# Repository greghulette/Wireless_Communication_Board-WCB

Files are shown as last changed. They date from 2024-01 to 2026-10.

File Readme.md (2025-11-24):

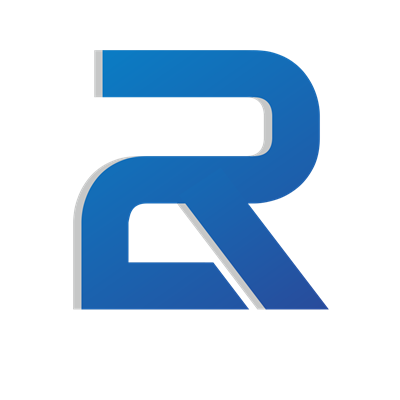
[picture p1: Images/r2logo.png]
<h1 style="display:inline; height: 75px; font-size:51px;">Wireless Communication Board (WCB)</h1>

<br>



# Software 3.0 and newer release changes the command structure.  Please read below to ensure proper operations.  

**NEW WIKI created to help better orgainize the documenation.  It can be found at the top the page or by clicking this link: [WCB Wiki](https://github.com/greghulette/Wireless_Communication_Board-WCB/wiki/)**

<br>
<br>
<br>
<br>
<br>

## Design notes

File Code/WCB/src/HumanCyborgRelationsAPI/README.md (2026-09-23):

> ## ⚠️ WCB vendored + patched copy — do not replace with stock upstream
>
> This is the [HumanCyborgRelationsAPI](https://github.com/roy86/HumanCyborgRelationsAPI)
> by roy86, **vendored directly into the WCB sketch** and patched for the
> Wireless Communication Board. It lives at `Code/WCB/src/HumanCyborgRelationsAPI/`
> and is pulled in with a relative `#include "src/HumanCyborgRelationsAPI/hcr.h"`,
> so **building the WCB firmware needs no library install** — and any HCR library
> already installed in your IDE is ignored (the bundled copy always wins).
>
> **WCB patches vs. upstream:**
> - **I2C/TwoWire removed** — the WCB drives the HCR over a serial UART only.
>   `hcr.h` `#define`s `TwoWire_h` before `#include <Wire.h>` (neutering it) and
>   every I2C constructor / transfer in `hcr.cpp` is commented out.
> - **`<String.h>` → `<string.h>`** (lowercase) so the build works on
>   case-sensitive filesystems (Linux CI), not just Windows/macOS.
> - **`PlayWAV()` debounce** is per channel and 150 ms (upstream: one global 5 s).
> - **`GetVolume(ch)`** added — the cached volume, no transmit. `getVolume()`
>   still sends `<QVx>` and returns the value cached before the reply.
> - **Dataframe key `QD`** accepted (the documented reply to `<QD>`); upstream
>   matched only `DF`, so the dataframe never parsed. Needs exactly 11 values.
> - **Receive framing:** `HCR_BUFFER_SIZE` 32 → 64, `<` resets the frame, only `>`
>   commits one (a CR/LF/NUL before it discards the partial frame), and an
>   over-long frame is dropped instead of parsed truncated.
> - **Reply validation:** every value field must be numeric, the field count must
>   match the key (2; `QE` 5; `QD`/`DF` 12), and `QVx` must be 0-100; anything else
>   is rejected (`onFrame(..., false)`) without touching the cache.
> - **`receive()` drains** up to `HCR_BUFFER_SIZE` waiting bytes per `update()`
>   (upstream: one byte), so a full reply set can't overflow the soft-serial buffer.
> - **`onFrame(frame, parsed)`** — protected virtual hook called after every
>   received frame. The library's own `Serial` prints never reach USB on the WCB.
> - **Virtual destructor** — the class now has a virtual hook, so it gets one.
> - **`StopEmoteGraceful()` / `StopGraceful()`** added — emit `<PSG>`, the
>   vocalizer's graceful stop. Upstream emits `PSV` from every stop path, so a
>   port owned by the library could only ever stop abruptly (issue #15).
> - **`<SoftwareSerial.h>` → `"../EspSoftwareSerial/SoftwareSerial.h"`** (`hcr.h`, and the
>   AVR/PIC32-only branches in `hcr.cpp`): the WCB's vendored, patched EspSoftwareSerial
>   (tracker #78, CLAUDE.md rule 7). Never use the angle-bracket include. CI installs no
>   stock copy, so the build would fail there; locally it would pull in the stock copy, and
>   the vendored header's `#error` or a class redefinition would stop the build.
> - **`SetEmotion(e, v)` accepts 0-100** (upstream accepted 0-99), to match `SetVolume`
>   and the range `;H,SETEMOTION` accepts. Upstream silently dropped v = 100.
>
> Upstream license is preserved in `LICENSE`. To pull a newer upstream, re-apply
> the patches above rather than dropping a stock copy in place.

---

Banner Employee Data title

# Human Cyborg Relations C++ API
C++ based API for interfacing with Michael Perl's [Human Cyborg Relations](https://humancyborgrelations.com/r2d2/) Teensy Based Vocalizers

## Overview

[Human Cyborg Relations](https://humancyborgrelations.com/r2d2/), created by Michael Perl, has set a new standard for Droid Vocalization through a fully functional AI, powered by advanced research into the speech patterns and emotional logic of R2-D2.

Each vocalization is unique. A sophisticated algorithm assembles R2’s speech "phoneme" by "phoneme." Billions upon billions of rules dictate how each sound should be selected, processed, timed, and sequenced to achieve emotional and canonical accuracy.

The [Human Cyborg Relations R2 Vocalizer](https://humancyborgrelations.com/r2d2/) has been ported to the Teensy 4.1 Hardware for stand-alone integration into custom droids build for the Astromech community usage. The WIKI and CODE here relates to the C++ Library created for Arduino/Teensy/ESP projects to allow people to interface their boards with the HCR R2 Vocalizer programmed Teensy 4.1 + Audio Shield.

Please when using this library, we encourage everyone to make a small donation directly to and support [Force for Change](https://www.starwars.com/force-for-change) and [FIRST®](https://www.firstinspires.org/)

## Documentation
### [API WIKI](https://github.com/roy86/HumanCyborgRelationsAPI/wiki)

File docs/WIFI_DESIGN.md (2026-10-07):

# WCB WiFi — hosting an access point, or joining one

Status: **in development on branch `WIFI`.** Not in a release.

A WCB can optionally bring up an IP interface — hosting its own access point, or
joining an existing one — so the mesh can be managed from a phone with no USB cable
and no extra hardware. It is **off by default**, and with it off the firmware behaves
exactly as it did before.

---

## 1. Why this lives on the boards

A phone cannot open a serial port. The Web Serial API is desktop-only — not Android
Chrome, never iOS — so a mobile client has no way to reach the mesh except over a
network. That single platform limit is what forces this design.

The alternatives were both rejected:

| Option | Why not |
|---|---|
| A dedicated relay board (`MgmtRelay` in `WCBClient`) | An extra ESP32, an extra power tap and an extra thing to fail, in every droid, whose only job is management. Fine as a bench tool; not something to ask every builder to install. |
| Require a NaviCore | Only a small subset of WCB users have one. Its AP cannot be assumed to exist. |

So the boards have to be able to carry it themselves. The relay and NaviCore paths
still work and are still useful — they are simply not the answer for most builders.

---

## 2. The one rule: the radio has one channel

The ESP32 has a **single radio**. An access point we host, or one we associate with,
shares its channel with ESP-NOW. Therefore:

> **The WiFi channel is always `meshChannel` (`?WCBCH`) and is deliberately not
> separately configurable.**

This is not a simplification for convenience. A WiFi channel that disagrees with the
mesh is a *silent, total* blackout: every ESP-NOW packet dropped, nothing logged on
the other boards, no fault indication anywhere. Offering the choice would mean
offering a way to brick the mesh with no symptom. Every entry point passes
`meshChannel` explicitly:

- `WiFi.softAP(ssid, pass, meshChannel, …)` — the channel argument **defaults to 1**.
  Once an AP owns the radio nothing later moves it, so a defaulted channel against a
  mesh on any other channel is exactly the blackout above.
- JOIN scans `meshChannel` alone for its SSID first (`WiFi.scanNetworks`, asynchronous, 120 ms) and calls
  `WiFi.begin(ssid, pass, meshChannel, bssid)` only for an AP heard there. `WiFi.begin`'s channel does not pin
  anything: it is where the driver's own connect scan *starts* (`wifi_sta_config_t.channel`, a "channel hint"),
  and with the AP absent that scan swept every channel on each attempt, taking the board off the mesh.
- JOIN asks the driver whether it is associated (`esp_wifi_sta_get_ap_info`), never `WiFi.status()`, and
  **verifies** the AP's own channel from that record: an AP elsewhere is disconnected and the join settles, since
  being deaf is worse than having no WiFi. `WiFi.status()` can lie both ways: the core leaves `WL_CONNECTED`
  standing after some disconnects, and it reconnects once on the first disconnect after every boot whatever
  `setAutoReconnect(false)` says, with a connect scan that sweeps. Reading the radio's channel mid-sweep, the old
  check took a lost AP for an off-mesh association and stopped rejoining for good. On a loss JOIN prints it, cancels
  that reconnect (`WiFi.disconnect()`) and goes back to scanning the mesh channel; an association that gets no
  address within 20 s is dropped and started over.

---

## 3. Modes

| Mode | Behaviour |
|---|---|
| `OFF` | ESP-NOW only. The default. Byte-for-byte the previous behaviour. |
| `AP` | Host a SoftAP on `meshChannel`, `WIFI_AP_STA` so ESP-NOW keeps its interface. Self-contained: no infrastructure, and nothing external can move the radio. The field mode. |
| `JOIN` | Associate with an existing AP (a NaviCore's, typically). One network reaches everything and the phone keeps its internet. |

**JOIN never falls back to hosting.** A board that quietly became an access point
because it could not find its network is precisely the rogue-AP surprise this design
avoids — and with several boards configured that way you would get several. It
scans the mesh channel for its network every 5 s indefinitely, logs occasionally, and stays a
station.

---

## 4. Ordering constraints

Two orderings are load-bearing, and they pull in opposite directions.

**`wcbWifiStart()` is called from `setup()` after `esp_wifi_set_mac()` and before
`esp_now_init()`.** That is the only point that satisfies both:

- *After* `esp_wifi_set_mac()`, so the ESP-NOW MAC is stamped on a plain `WIFI_STA`
  interface before an AP is added alongside it.
- *Before* `esp_now_init()`, because in AP mode the SoftAP must own the radio channel
  first. Once ESP-NOW is initialised nothing later moves the radio, and an AP raised
  afterwards fights it.

This mirrors what `WCB_Client` had to handle when NaviCore began hosting an AP:
`WCB_Client::begin()` inspects `WiFi.getMode()` and preserves an existing AP as
`WIFI_AP_STA` rather than forcing `WIFI_STA` and tearing it down.

**Settings apply at the next boot, not live.** Same discipline as
`saveMeshChannelToPreferences()`. Bringing an interface up or down re-enters the WiFi
driver underneath a running `esp_now`, and a config push arrives as a *stream* of
commands — losing the radio midway would strand everything still queued behind it.

---

## 5. Interaction with bit-banged serial (S3–S5) — **open**

This is the unresolved risk, and it is tracked here so it is not rediscovered.

S3–S5 are `EspSoftwareSerial`. TX busy-waits each bit period, so an interrupt landing
mid-byte compresses the remaining bits and the **receiver mis-frames** — the command
arrives cut short, not garbled. `enableIntTx(false)` fixes this by taking a critical
section, bounded to one byte (~0.94 ms at 9600) because `lazyDelay()` restores
interrupts at every stop bit.

`softSerialLoopTaskOnly()` (`WCB.ino`) only enables that protection where **no core-0
task writes the port**, because the library's interrupt mux is a single `static`
spinlock shared by all three ports — core 0 would otherwise spin on it with its own
interrupts disabled, inside the WiFi task. Ports excluded today:

- PWM input or output (`PWMTask` is pinned to core 0)
- the local Kyber port
- raw-mapped ports
- ports hosting a locally-attached Maestro

…all four because `espNowReceiveCallback` writes them directly from the WiFi task.

**Hosting an AP adds radio interrupt load** — beacons, associated stations, TCP — on
exactly those unprotected ports. Telling users "only enable WiFi on a board with none
of those configured" is not a deployable constraint.

The fix is to remove core-0 writers so every port qualifies for protection:

1. **`PWMTask`** is pinned to core 0 by choice (`WCB.ino`, `xTaskCreatePinnedToCore(…, 0)`).
   Every other task is already on core 1. Re-pinning removes the PWM exclusion — but
   it runs at priority 2 against the others' 1, so this needs measuring, not flipping. Its
   biggest cost is gone: output pulses are RMT-clocked (`pwmPulse()`, tracker #94), so
   `PWMTask` no longer busy-waits up to 2.5 ms for each one.
2. **`espNowReceiveCallback`** cannot move; it is the WiFi task. Its direct writes to
   Maestro, Kyber and raw-mapping ports must be handed to core 1 instead. The pattern
   and the consumer already exist — `mgmtQueueOut`/`drainMgmtOut`, and
   `RawSerialForwardingTask` polls every 2 ms — so the added latency is ≤2 ms.

Doing both also closes the residual noted in the source: a raw-serial mapping on a
*remote* board can target a port this board believes is idle, which is not locally
knowable and so cannot be handled by the predicate.

**Sequencing:** close the soft-serial timing first and confirm it on the bench, then
enable the AP on top. Doing them together leaves you unable to tell which change
caused a regression.

---

## 6. Commands

```
?WIFI                       Status: mode, SSID, IP, radio channel, free heap
?WIFI,OFF                   ESP-NOW only (default)
?WIFI,AP,<ssid>,<pass>      Host an access point
?WIFI,JOIN,<ssid>,<pass>    Join an existing one
```

All changes persist immediately and apply on the next reboot.

- The **AP password is mandatory, 8 characters minimum, and fails closed.**
  `WiFi.softAP()` with an empty passphrase creates an *open* network, and this
  interface accepts commands for the whole mesh with no credential of its own — a
  bare `?RESTART` carries none. It is rejected at both the command and at bring-up.
- **Default AP SSID** is `WCB-<alias>`, falling back to `WCB-<number>`. Two droids in
  one room must not advertise the same name.
- The password field is **not** trimmed: a trailing space is legal in a WPA2
  passphrase, and eating it would lock the operator out of their own AP.

### NVS

Namespace `wifi_cfg`: `mode` (u8), `ap_ssid`, `ap_pass`, `jn_ssid`, `jn_pass`.

### Config round-trip

`?WIFI` is emitted in the config dump (`WIFI,AP,<ssid>,<pass>` / `WIFI,JOIN,…` /
`WIFI,OFF`) so a backup captures it and a restore replays it. The password is
included deliberately: a restore that brought the AP back *without* its passphrase
would fail closed at boot, and the board would come up with no AP and nothing saying
why. `OFF` is emitted too, so restoring a WiFi-off backup actively turns it off
rather than leaving whatever was there.

---

## 6a. The WebSocket endpoint (`WCB_WS.{h,cpp}`)

`ws://<board-ip>/ws` — a second mouth for the same line protocol the USB port
speaks. Lines go to `processSerialCommandHelper()`, the identical dispatcher the
Serial0 reader feeds, so the two transports cannot drift. Starts automatically on
the first `loop()` pass where `wcbWifiReady()` is true, latched so a failed start
is not retried forever.

**Concurrency.** The httpd task is Core 0, beside the ESP-NOW receive callback. The
handler may only copy, enqueue and return — `processSerialCommandHelper()` writes
NVS, drives bit-banged SoftwareSerial and blocks on ETM retries. `wcbWsService()`
runs one command per pass from `loop()` on Core 1. The handler also **never
prints**: UART0 has no TX buffer, so a print there blocks the httpd task and holds
the UART0 mutex against `loop()`. Drops are counted and reported from `loop()`.

**Output tee.** `WCBSerial::write()` gains a third destination alongside USB and the
mesh relay. Teeing at that one point rather than at each print site is what keeps
the transports identical — handlers go on printing exactly as they always have.
`wcbWsSinkWrite()` only appends to a buffer: no print (that would recurse straight
back into the tee), no allocation, no TCP send.

**Per-command flags.** The drain resets `lastReceivedViaESPNOW` and `inSequenceBody`
before dispatching, exactly as the Serial0 reader does. They are snapshotted per
queue item, so a value left from a prior mesh recall's body drain would otherwise
latch and suppress this command's fan-out.

**Line cap is 1536, not MgmtRelay's 384.** The relay's socket only carries
`?OTA,DATA` with a 192-byte firmware chunk. This endpoint is the one an OTA over
WiFi uses, and that is the *direct* path — `?OTALOCAL,DATA,<base64>` with a
1024-byte chunk (`const CHUNK = 1024` in the Wizard), which encodes to ~1368 chars
plus prefix. At 384 every DATA frame would hit the line-too-long guard, and the
transfer would ACK the BEGIN and then move nothing.

**Two clients at once** (`WS_MAX_CLIENTS`, httpd's `max_open_sockets`). A third
connection still succeeds: `lru_purge_enable` closes the least recently used session
to take it. Each session costs heap beyond its static 1.5 KB accumulator: its socket,
TCP buffers and httpd's session state. With the AP up a classic ESP32 has about 17 KB
of heap, and with three sessions a `?backup` streamed to them took it to within 48 bytes
of empty (HIL tracker #111). It was three until 2026-10-07.

**A client that leaves without closing is let go at once** (HIL tracker #113). A phone out of range or a PC moved
to another network leaves its socket open while TCP retries it, and everything teed to it waits in lwIP, up to a
TCP send buffer (~5.7 KB) per session. So a failed send closes the session (`httpd_sess_trigger_close`), not just
the tee; `wsClose` resets the socket (`SO_LINGER` 0) so its buffers are freed at once; when the AP's last station
leaves, every session from the AP's /24 is closed on the next `loop()`; and httpd's send timeout, which a send to a
gone client blocks `loop()` for, is 2 s.

**AP address: the stock `192.168.4.1`. Do not call `softAPConfig()`.**

The plan was `192.168.4.<board number>`, so a host could tell a WCB from a NaviCore
by address — every ESP32 SoftAP defaults to `.1`, so probing it finds *something*
and cannot say what. It was tried **both before and after `softAP()` and breaks DHCP
either way**: the AP comes up, clients associate, `?WIFI` reports the correct IP, and
no lease ever arrives, so every client falls back to `169.254.x` and cannot reach the
board at all.

Measured repeatedly on hardware — Windows reports *"unable to contact your DHCP
server"* — and it is **not** a startup race: it still failed on a board that had been
up for minutes. It appeared to work once, which makes it worse than useless. An
intermittent DHCP failure costs far more to own than a duplicate default address.

Nothing about the symptom points at the cause: the address looks right in `?WIFI`
either way, and the AP is plainly up because clients associate to it.

**Identity belongs in the protocol, not the address.** A host should ask — one
command over the socket names the board — rather than infer from an IP.

**No default gateway.** The AP's DHCP server hands out an address and a subnet but
**no router** (DHCP option 3). This AP is a local management link with no upstream,
so advertising itself as the default gateway only invites a client to send
internet-bound traffic to a board that cannot deliver it: a laptop with a second
adapter ends up with two competing default routes, and a phone may decide the whole
network is broken. With no router offered, the client reaches `192.168.4.1` on-link
and keeps its existing default route for everything else.

It is done by clearing `OFFER_ROUTER` from the DHCP server's offer mask with
`esp_netif_dhcps_option(…, ESP_NETIF_ROUTER_SOLICITATION_ADDRESS, …)`. That option is
only accepted while the server is stopped, so the sequence is stop → set → start — the
same one the core's own `APClass::enableDhcpCaptivePortal()` uses. **The server is
restarted unconditionally, even if the set fails**: a stopped DHCP server is exactly
the dead-AP failure `softAPConfig()` produced, and nothing about that symptom points at
the cause. If the current mask cannot be read, the step is skipped entirely rather
than guessed at, leaving the stock behaviour in place.

Verified on hardware (WCB1, `6.2.1_101034RSEP2026`): after a full DHCP exchange the
client's gateway is `(none)` and its default route via the AP is gone, while the lease
itself is still a normal `192.168.4.2` and the WebSocket still connects.

**A client that was already connected keeps the old gateway.** A lease *renewal* is a
REQUEST/ACK, and Windows retained the previous default gateway when the ACK simply
omitted option 3 — `ipconfig /renew` after flashing still showed `192.168.4.1`. Only a
fresh DISCOVER (reconnect, `ipconfig /release` then `/renew`, or lease expiry) picks up
the gateway-free lease. Right after an upgrade, a gateway that is still there means the
client hasn't re-leased yet — not that the firmware didn't apply.

## 7. Wizard integration

WiFi is configured from the **board card** in the Setup Wizard, under an
`advanced-only` subsection — most builders never need it, and putting an access point
on a droid is a decision worth making deliberately.

It is a **per-board** field, unlike `meshChannel` which is system-wide, so it lives in
`boardConfigs[n].wifi` rather than in general settings. Four integration points in
`Wizard/parser.js`, all of which must move together:

| Point | What |
|---|---|
| defaults | `wifi: { mode, apSsid, apPass, joinSsid, joinPass }` |
| `case 'WIFI'` | parses `WIFI,OFF` / `WIFI,AP,<ssid>,<pass>` / `WIFI,JOIN,…` |
| command generation | emits one `WIFI,…` line, only when something changed |
| `check('wifi', …)` | so the diff engine sees an edit as unsaved |

The password is split off manually rather than taken from `parts[]`: a WPA2 passphrase
may contain commas, so everything after the SSID field is password.

`commandStringNeedsReboot()` in `app.js` lists `WIFI,`. Without that entry a push
applies the setting and never prompts for the restart that makes it take effect — the
board would silently keep its old WiFi state. The generator only emits the line when
something actually changed, so unrelated edits do not nag for a reboot.

**The channel is deliberately absent from this UI.** Offering it would be offering a
way to take the board off the mesh with no visible symptom. The note line instead
states which channel WiFi will run on, read from the live `meshChannel`.

### Why there is no separate WiFi tool

An earlier cut of this work shipped `Wizard/wifi-tool.html`, a standalone Web Serial
page. It was removed. Two reasons, both concrete:

- `?WIFI` is already in the **restorable config chain**, so the Wizard has to
  understand it regardless — a tool that set it independently would be silently
  undone by the next config push or restore.
- Two same-origin tabs cannot both hold a serial port.

### The transport constraint, and why it is already solved

A page served over **HTTPS cannot open a plaintext `ws://` or `http://`** connection to
a board. Mixed content is a hard block with no click-through, so the Wizard's published
GitHub Pages URL can never talk to a board over WiFi.

**NaviLink already routes around this** by serving the config-tool UI itself over
`http://127.0.0.1:PORT` and putting its WebSocket on that same origin. The host process
decides whether the far end is a COM port or the droid's AP, so serial and WiFi become
one code path in the page. Any browser-based network management has to be served that
way — from the host, not from Pages.

---

## 8. Measured cost

Baseline is 6.2.1 (`66845b9`), `PartitionScheme=min_spiffs`, core `esp32:esp32@3.3.4`.

| Target | Flash before | Flash after | Static RAM before | after |
|---|---|---|---|---|
| ESP32 | 1,299,367 (66%) | 1,309,559 (66%) | 95,664 (29%) | 95,744 (29%) |
| ESP32-S3 | 1,265,247 (64%) | 1,275,559 (64%) | 93,912 (28%) | 94,000 (28%) |

So the WiFi module itself costs ~10 KB of flash and under 100 bytes of static RAM on
both targets — neither percentage moved.

Adding the WebSocket endpoint (`WCB_WS`) on top:

| Target | Flash | Static RAM |
|---|---|---|
| ESP32 | 1,345,847 (68%) — **+36.3 KB** | 105,552 (32%) — **+9.8 KB** |
| ESP32-S3 | 1,311,099 (66%) — **+35.5 KB** | 103,808 (31%) — **+9.8 KB** |

The static growth is the per-socket accumulators (three, 3 × 1536 B, when this was
measured; two now), the 2 KB output sink and the 3 KB static receive buffer. The command queue is *heap*-allocated
(6 × 1540 B ≈ 9.2 KB) and so comes out of runtime free heap, not this figure.

**Measured on hardware**, WCB1 with the AP up and no client attached:

```
Free heap : 110588 bytes (min since boot 109828)
```

That figure was `ESP.getFreeHeap()`, which on a classic ESP32 also counts the ~39 KB IRAM
heap that a byte buffer cannot use (`MALLOC_CAP_INTERNAL`, as #58 found for
`getMaxAllocHeap()`), and it predates most of today's firmware. `?WIFI` now reads the heap
a `String` or a socket buffer comes from (`heap_caps_get_free_size(MALLOC_CAP_8BIT)`,
`WCB_WiFi.cpp`): about 17 KB on a classic ESP32 with the AP up and nobody attached, and
within a few hundred bytes of empty while a client is busy (HIL tracker #111). An
ESP32-S3 keeps about 100 KB.

That is the WiFi module only — no web server yet. For reference, the WebSocket
endpoint in `MgmtRelay` measured **+37 KB flash / +4.7 KB static RAM**, which would
take the ESP32 to roughly 68%.

**Runtime heap is the number that actually decides this**, and it needs hardware —
`httpd` plus the TCP stack want tens of KB, and AP+STA costs more than STA alone.
`?WIFI` reports `ESP.getFreeHeap()` and `getMinFreeHeap()` so it can be measured on a
board rather than guessed at. Static analysis says it fits; that is not the same
claim.

---

## Revision log

| Date | Commit | Change |
|---|---|---|
| 2026-10-07 | `41ce60b` | §6a: a WebSocket client that leaves without closing is let go at once - closed on a failed send and when the AP's last station leaves, reset so lwIP frees its buffers; send timeout 2 s (HIL tracker #113). |
| 2026-10-07 | `48da52a` | §6a: two WebSocket clients at once, not three (HIL tracker #111, Greg's call); a third evicts the least recently used. The memory section no longer reads the old 110 KB `ESP.getFreeHeap()` figure, which counted the IRAM heap, as headroom. |
| 2026-09-28 | `e55ba82` | §2: JOIN reads its association and the AP's channel from the driver, not `WiFi.status()` and the radio's momentary channel, cancels the core's forced reconnect on a loss, and starts over after 20 s associated without an address (tracker #103: the lost network was never noticed and never rejoined). |
| 2026-09-28 | `5770675` | §2: JOIN scans the mesh channel alone before each `WiFi.begin` (tracker #103): the channel argument was only the start of the driver's connect scan, which swept the band while the AP was absent. §3's retry line follows. |
| 2026-09-27 | `1f629a8` | §5 item 1: PWM output pulses are RMT-clocked (tracker #94), so `PWMTask` no longer busy-waits for each pulse; re-pinning it to core 1 costs less than it did. |
| 2026-09-10 | `b898088` | **The AP no longer offers a default gateway.** DHCP option 3 is cleared through `ESP_NETIF_ROUTER_SOLICITATION_ADDRESS`, so a client reaches `192.168.4.1` on-link and keeps its real default route — a board with no upstream advertising itself as the router gives a two-adapter laptop competing default routes and can make a phone reject the network. Stop → set → start with an unconditional restart, and skipped entirely if the offer mask can't be read; see §6a. **Verified on hardware** on `6.2.1_101034RSEP2026` (`b898088`): gateway `(none)` after a full DHCP exchange, lease and WebSocket unaffected — but an already-connected client kept the old gateway through a plain renew. |
| 2026-09-10 | `ba94d3a` | **Code review — five defects fixed, three of which defeated their own purpose.** (1) `WiFi.disconnect(true)` in the JOIN off-mesh guard: the bool is `wifioff`, and in STA-only mode it runs `STA.end()` → `WIFI_MODE_NULL`, stopping WiFi and **taking ESP-NOW with it** — the guard that exists to keep the board on the mesh was the one thing reliably killing it. Now `WiFi.disconnect()`. (2) The output sink was mutated from the printing task (including the ESP-NOW callback) while `sinkPump()` memmoved it on the loop task, with no lock — torn output indistinguishable from a real reply. Now guarded by a `portMUX`, with the critical sections deliberately never spanning the TCP send. (3) JOIN latched `joinSettled` on **success**, so with auto-reconnect off nothing ever retried after the AP rebooted or the droid drove out of range, and `wifiUp` never cleared so `?WIFI` reported "up" with no address. Only the off-mesh case settles now. (4) An oversized inbound frame returned without draining the payload, leaving it to be parsed as the next frame header and desynchronising the session permanently; it now returns `ESP_FAIL` so httpd closes cleanly. (5) `WIFI,` was missing from `dataBearingVerb`, so a passphrase ending in `?` was eaten by the trailing-`?` help shortcut and never saved. Also: the WS drain now `trim()`s like the Serial0 reader (a leading space made a line unprefixed, i.e. a mesh-wide broadcast), and bring-up prints `ws://…/ws` instead of a `http://…/` that was always a 404. |
| 2026-09-07 | `7586a19` | **Bulk replies were being truncated over the socket.** `wcbWsSinkWrite()` dropped whole lines once the 2 KB staging buffer filled, and it only drained once per `loop()` pass — but a config dump is a tight run of `Serial.println()` with no `loop()` iteration between them, so most of a ~3 KB reply was discarded. It now flushes **inline, but only while running on the loop task** (handle captured in `wcbWsService()`); off that task — above all the ESP-NOW callback — it still drops, because a TCP send there would stall the WiFi task. Verified: `WCB_WEBTOOL_CONFIG_PULL` over the socket returns 3,024 bytes / 67 lines with **0 drops**, ending in its checksum, `WIFI,` line included. |
| 2026-09-07 | `7586a19` | **`softAPConfig()` removed entirely — it breaks DHCP in either position.** See §6a; the board stays on the stock `192.168.4.1` and identity moves into the protocol. |
| 2026-09-07 | `7586a19` | **VERIFIED ON HARDWARE.** `softAPConfig()` was being called *before* `softAP()`, which leaves the DHCP server stopped — clients associated, got no lease, fell back to `169.254.x` and could not reach the board. Moved it after. Confirmed end to end on WCB1 (ESP32-D0WD): lease `192.168.4.2`, WebSocket connected to `ws://192.168.4.1/ws`, `?WIFI` and `?VERSION` answered over the socket, and an unsolicited `[ETM] WCB19 came ONLINE` streamed through — so the output tee carries events, not just command replies. Free heap 77,044 with a client attached (min 61,236). |
| 2026-09-06 | `eec12d5` | **Added the WebSocket endpoint** (`WCB_WS.{h,cpp}`, `ws://<ip>/ws`), which is what makes the AP useful — until now the radio was up with nothing listening. Feeds `processSerialCommandHelper()`, so it is the same command surface as USB. Handler copy-enqueue-returns on Core 0 and never prints; commands run from `loop()`; output tees through `WCBSerial::write()`. Line cap 1536 B, not MgmtRelay's 384, because `?OTALOCAL` uses 1 KB chunks. The AP also moved to `192.168.4.<board number>` so it stops colliding with NaviCore's default `.1`. Measured free heap before this landed: 110,588 B. |
| 2026-09-05 | `766f52d` | **`WCB_WiFi.cpp` was printing into an unopened port.** It omitted `#include "WCB_RemoteTerm.h"`, which ends in `#define Serial WCBDebugSerial`; `setup()` only calls `begin()` on that wrapper, so the core's raw `Serial` is never opened. `?WIFI` matched, ran and printed nothing — a *dead command* with no error, because the command was known. Recorded as rule 12 in `CLAUDE.md`, since it applies to any new subsystem file. |
| 2026-09-03 | `867addf` | WiFi moved into the Wizard board card (advanced-only) and the standalone `wifi-tool.html` removed — `?WIFI` is in the restorable config chain, so the Wizard has to own it or a push would silently undo an external tool. Wired through all four `parser.js` points, and `WIFI,` added to `commandStringNeedsReboot()`; without it a push applied the setting and never asked for the reboot that makes it real. |
| 2026-09-02 | `55df332` | Initial design and implementation on branch `WIFI`. `?WIFI` with OFF/AP/JOIN modes, channel locked to `?WCBCH`, fail-closed AP password, non-blocking JOIN with channel verification and no AP fallback, NVS `wifi_cfg`, config round-trip, and `Wizard/wifi-tool.html`. Section 5 records the open soft-serial interaction, which gates enabling this on a board with PWM / Kyber / raw-mapped / local-Maestro ports. |

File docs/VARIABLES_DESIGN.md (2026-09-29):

# WCB Variables & Conditional Execution — Design

Dynamic, persistent variables plus a single-command `IF` gate, usable in stored
sequences, at the serial terminal, and over ESP-NOW.

---

## 1. Variables

- **Store:** two kinds, one namespace. **Volatile** vars (`;V`, the default) live
  in RAM only — no flash, gone on reboot. **Persistent** vars (`;VP`, `?VAR,SET`)
  are RAM-mirrored and saved to NVS namespace `wcb_vars` (loaded into RAM at boot).
  Reads (`IF`, `?VAR,GET`) always hit RAM (instant); a persistent write also commits
  the NVS blob. A name is **one** variable — it's *either* volatile or persistent at
  any moment, not two separate slots.
- **Cap:** 100 variables (`WCB_MAX_VARIABLES`). Set #101 → error.
- **Type:** signed 32-bit integer. "Boolean" is just `0` / non-zero — `true`/
  `false` are input sugar for `1`/`0`. No separate type is tracked.
- **Names:** 1–15 chars (NVS key limit), **case-sensitive**, restricted to
  `[A-Za-z0-9_]`. Any other character (`, = < > ^ ; ?` space …) → rejected with
  an error at save time.
- **Undefined = 0.** `IF,x=1` on an unset `x` is false; `IF,x=0` is true.

---

## 2. Commands

### Set / mutate (runtime) — `;V` (volatile) / `;VP` (persistent)
`;V,<name>,<value-or-verb>[,<amount>]`  — volatile (default)
`;VP,<name>,<value-or-verb>[,<amount>]` — persistent (saved to NVS)

| Form | Effect |
|---|---|
| `;V,name,<int>` | set to integer (**volatile**) |
| `;VP,name,<int>` | set + **persist** to NVS |
| `;V,name,0` / `,1` | set boolean |
| `;V,name,true` / `,false` | set 1 / 0 |
| `;V,name,TOGGLE` | flip: non-zero → 0, 0 → 1 |
| `;V,name,INC` / `;V,name,INC,<n>` | add n (default 1) |
| `;V,name,DEC` / `;V,name,DEC,<n>` | subtract n (default 1) |

`;VP` accepts the same verbs. The comma after `V`/`VP` is **required** — the old
no-comma `;Vname,value` shorthand was removed.

**Persistence is a property of the variable, chosen at creation and never silently
lost:**
- `;V` on a **new** name → volatile; `;VP` (or `?VAR,SET`) on a new name → persistent.
- `;VP` **promotes** an existing volatile var to persistent.
- `;V` on an existing **persistent** var keeps it persistent (and persists the new
  value) — it does **not** demote. Demoting persistent → volatile is deliberate:
  `?VAR,CLEAR` then recreate with `;V`.

Both are `;` runtime commands — they work in sequences / serial / ESP-NOW and
respect the `IF` gate (a gated set is skipped).

### Manage (config) — `?VAR`
- `?VAR,LIST` — list every variable, its value, and its `[volatile]`/`[persistent]` type
- `?VAR,SET,<name>,<value>` — create/update a **persistent** variable with an
  **absolute** value (int / `true` / `false`; no `TOGGLE`/`INC`/`DEC` — those are
  runtime `;V`/`;VP`). Used by the Tools-page variable manager.
- `?VAR,GET,<name>` — print one
- `?VAR,CLEAR,<name>` — delete one
- `?VAR,CLEAR,ALL` — delete all

Note: there is no separate "declare" step — the first `;V` (volatile), `;VP`, or
`?VAR,SET` (persistent) creates the variable.

### Conditional (runtime) — `IF`
`IF,<condition>[,AND|OR,<condition> …]`

- **Condition (inline operator):** `<name><op><literal-int>`
  Operators: `=`  `!=`  `<`  `>`  `<=`  `>=`
  e.g. `IF,domeanimations=1`, `IF,count>5`, `IF,mode>=2`
- **Compound:** conditions joined by `,AND,` / `,OR,`, evaluated **strictly
  left-to-right, no precedence / parentheses**.
  `IF,a=1,AND,b=1`  •  `IF,mode>2,OR,override=1`
- **Right-hand side is a literal integer** (no var-to-var compares in v1).
- **Gates exactly the next `^`-delimited command.** True → next command runs.
  False → next command is skipped; the rest of the chain continues.

---

## 3. Execution model (invoke-time, chain-local gate)

> **History:** v1 used a global `skipNextCommand` flag consumed inside
> `handleSingleCommand`. That design raced across command sources (an
> unrelated ESP-NOW command could be swallowed by another chain's IF), across
> queue-drain boundaries, and across timer groups — it was replaced.

IF gating is resolved **when the chain is invoked**, inside the two canonical
chain splitters with **chain-local** state (no global):

```
parseCommandsAndEnqueue / parseCommandGroups, while walking the tokens:
    bool ifSkipping = false                 # lives on the stack, per chain
    for each trimmed token:
        ifGateConsumeToken(token, ifSkipping)   # ONE shared implementation
            IF,…       -> evaluate NOW; false => start gating
            comment    -> never consumes the gate
            ;t500      -> while gating: dropped, gating CONTINUES
            ;t500,cmd  -> while gating: dropped, gate consumed
            other      -> while gating: dropped, gate consumed
        tokens that survive are enqueued / grouped normally
```

- Shared semantics live in `ifGateConsumeToken()` (WCB_Variables.cpp) so the
  timer and non-timer walks cannot drift.
- **Timers between IF and its command work**: `IF,x=1^;t500^cmd` waits then
  runs when true; skips the delay AND the command when false.
- **Consecutive IFs AND together**: `IF,a=1^IF,b=2^cmd` runs `cmd` only when
  both hold (same result as the compound `IF,a=1,AND,b=2`). Compound is clearer;
  both work.
- **IF cannot ride inside a `;t` payload** (`;t500,IF,…` → error: write
  `IF,cond^;t500^cmd`) and **cannot ride inside a `;w` payload**
  (`;w2,IF,…` → error: gate the whole route — `IF,cond^;w2,cmd`).
- **Set and test must be separate invocations.** IF evaluates at invoke time,
  before any command of the same chain has executed — so
  `;V,x,1^IF,x=1^cmd` reads the OLD value of `x` (stale-by-one). Correct
  pattern: one sequence sets the flag, another tests it:
  `?SEQ,SAVE,arm,;V,x,1` … `?SEQ,SAVE,fire,IF,x=1^cmd`.

---

## 4. Scope & per-board semantics

- Works everywhere a command can be issued (serial / ESP-NOW / sequences).
- **Variables are per-board** (each board's own NVS):
  - `;w2,;V,domeanimations,1` → sets it on **WCB2 only**
  - broadcast `;V,domeanimations,1` → sets it on **every** board
  - `IF` always tests the variable on **whichever board runs the chain**

---

## 5. Backup

A persistent set or clear **succeeds only if NVS takes it.** `saveVarsToNVS()` reports whether
the store now holds what RAM holds. When a write fails (a full NVS), the set prints the
`[VAR] ERROR` line, prints no `[persistent]` confirmation, which is the line the Wizard's push
waits for, and puts RAM back as it was: a new variable is gone, an existing one keeps its old
value and type. A refused clear keeps the variable. So what a board reports is what it will
boot with. An empty store removes the NVS key instead of writing an empty blob, so clearing
the last variable works even on a full store (HIL `seq.nvs_full_consistency`, opt-in `nvs_fill`).

`?backup` emits one `?VAR,SET,<name>,<absolute-int>` config line per **persistent**
variable, so persistent variables round-trip through a backup/restore and survive a
reflash (not just a reboot). **Volatile** variables are RAM-only and are **not**
backed up. Relative verbs (`TOGGLE`/`INC`/`DEC`) are never emitted — only absolute
values.

---

## 6. UI

- **Wizard:** unchanged (variables aren't part of first-time setup).
- **Tools page (config tool):** a **Variables** panel per board — list, add,
  edit value, delete. `IF`/`;V` are typed directly into stored sequences; the
  sequence editor only needs to **accept `IF,…` and `;V,…` as valid** (no special
  conditional UI). They already render on their own lines (split on `^`).

---

## 7. Limits & notes

- 100 int vars ≈ ~5 KB, sharing the single 20 KB NVS partition with all config.
  Fine today; gets dedicated space when/if the 8/16 MB repartition happens.
- **Flash wear:** volatile `;V` never writes flash — safe to drive from a fast timer
  loop or a live feed at any rate. Only persistent writes (`;VP` / `?VAR,SET`) commit
  the NVS blob, and each rewrites the *whole* variables blob, so keep a
  rapidly-changing value **volatile** (don't `;VP` it). NVS wear-levels (~1–6 M blob
  rewrites before the 20 KB partition wears), but a persistent value churned hundreds
  of times a second can still wear it out in hours — which is exactly why volatile is
  the default.
- No nesting: `IF,a=1^IF,b=1^M23` does **not** mean "a AND b" (the first IF just
  gates the second IF). Use compound `IF,a=1,AND,b=1` instead.

---

## 8. Code touch-points

| File | Change |
|---|---|
| `WCB_Variables.h/.cpp` | RAM+NVS store with a volatile (`;V`, default) / persistent (`;VP`, `?VAR,SET`) split — `;VP` promotes, `;V` never demotes; `;V`/`;VP`/`?VAR` handlers, `IF` evaluator + `ifGateConsumeToken()` (the ONE shared gate implementation), name validation, backup emit (`?VAR,SET` form, persistent only) |
| `WCB.ino` | `loadVariables()` in setup; chain-local IF gating in `parseCommandsAndEnqueue` (via the shared helper); IF-in-`;w`-payload rejection in `processWCBMessage`; bare-IF safety drop in `handleSingleCommand`; `;V`/`;VP` (V-prefixed) case in the `;` dispatcher; `?VAR` case in `processLocalCommand`; backup emit call |
| `command_timer.cpp` | chain-local IF gating in `parseCommandGroups` (same shared helper); IF-as-timer-payload rejection; trimmed-token handling |
| `WCB_Help.cpp` | `?VAR ?`, `;V`, `IF` help blocks + overview lines |
| Wizard `app.js`/`index.html`/`parser.js` | Tools-page Variables manager; IF+command grouped on one editor line; `?VAR,SET` (and legacy `;V`) round-trips in backup parse/build |

---

## Revision log

Newest first. One row per change that altered what this document describes.

| Date | Commit | Change | Why |
|---|---|---|---|
| 2026-09-27 | `cc2a8a9` | A persistent set or clear that NVS refuses prints no confirmation and leaves RAM as it was; an empty store removes the key. | On a full store `?VAR,SET` printed the ERROR and then its `[persistent]` ACK, so the Wizard counted a value that was gone at the next boot, and a cleared variable came back (WCB coverage re-scan #13). |
| 2026-08-06 | — | Split variables into **volatile** (`;V`, now the default — RAM-only) and **persistent** (`;VP` / `?VAR,SET` — NVS). `;VP` promotes a volatile var; `;V` never demotes a persistent one. Dropped the no-comma `;Vname` shorthand; `?VAR,LIST` now shows the type. Also corrected §5 (backup emits `?VAR,SET`, not `;V`). | A `;V` in a fast loop rewrote the whole NVS blob on every value change — hundreds of writes/sec could wear out the shared 20 KB partition in hours. Making the churny default RAM-only protects the flash without the user having to know; persistence is now an explicit opt-in (`;VP`). |

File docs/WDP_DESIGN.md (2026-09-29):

# WDP — Wireless Discovery Protocol (WCB Mesh)

**Status:** Implemented and shipping — this document describes the protocol **as built**.
**Scope:** ESP32/ESP32‑S3 WCB firmware (`Code/WCB`), the Wizard/Config Tool (`Wizard/`), and the
`WCB_Client` Arduino library (v1.7.0+). Serial‑attached devices announce via the companion spec
[`WDP_DEVICE_ANNOUNCE.md`](WDP_DEVICE_ANNOUNCE.md).

---

## 1. What WDP is (and isn't)

WDP is a lightweight discovery/advertisement layer for the WCB ESP‑NOW mesh — conceptually
**"Cisco CDP/LLDP, but for WCBs."** Each board periodically announces *its own* identity and
capabilities; every board listens and builds a **neighbor table**. From that one mechanism the
mesh gets friendly aliases, a live "what's on my mesh" view in the Wizard, controller
auto‑configuration, and — with auto‑join — a peer table that builds itself.

**Goals (all met by the shipped implementation)**
- **Zero‑config awareness** — boards learn the mesh without hand‑entering cross‑board maps.
- **Extensible** — TLV encoding; new advertised facts never break older firmware.
- **Cheap** — a couple of 252‑byte broadcasts per minute per board (an advert, plus one WDP‑DA
  device‑list frame for a board with a few serial‑attached devices).
- **Backward compatible** — no wire‑size change; pre‑WDP firmware ignores the packets harmlessly.
- **Authoritative‑by‑owner** — a board only ever advertises *its own* facts.

**Non‑goals**
- **Not config replication/sync.** WDP is *discovery*. A board's own saved config remains the
  source of truth for itself.
- **Not a reliability layer.** Adverts are best‑effort broadcasts; the model is eventual
  consistency.
- **Not a new security boundary.** It sits *behind* the existing ESP‑NOW gates (§8).

**Relationship to ETM:** ETM answers *"is WCB 3 alive?"* (heartbeats → `boardTable[]`);
WDP answers *"who is WCB 3 and what can it do?"* (adverts → `wdpNeighbors[]`). Same carrier,
same auth, parallel tables.

---

## 2. Transport

WDP rides the existing 252‑byte ETM struct (`espnow_struct_message_etm`) as packet type
`PACKET_TYPE_WDP = 12`, reusing the `structCommand[200]` field that is empty on non‑command
packets. No wire‑size change, so the size‑based receive router is untouched; old firmware sees an
unknown packet type in the ETM branch and drops it.

A board's serial‑attached (WDP‑DA) device list rides the same struct as **`PACKET_TYPE_WDP_DA =
17`** (§3). It has its own packet type for the same reason WDP could be added at all: released
firmware and `WCB_Client` drop an ETM packet type they don't know (the fall‑through `return` at the
end of the ETM receive path; `WCB_Client`'s packet switch has no `default`). Sent on type 12, an older
board's advert decoder would take it for an **empty advert** and blank the sender (the SOLICIT trap, §3).

Decode is **deferred to `loop()`** (`enqueueWdpPacket` → `drainWdpPackets`, which dispatches on the
packet type) — the ESP‑NOW receive callback runs on the WiFi task and must not do heavy work.

### Cadence

| Trigger | Count | Notes |
|---|---|---|
| Boot burst | 3× starting ~1.6 s after boot | fast initial population, follows the ETM boot announce |
| Periodic backstop | every 60 s | staggered per board (`WCB_Number`‑based phase) so co‑booted boards don't collide |
| Solicited | 1× on hearing a SOLICIT (or local `?WDP,POLL`) | jittered 0–600 ms by board number so a fleet doesn't reply in lockstep; lets an operator refresh the whole mesh on demand |
| Advert change | 1× + 1 re‑send 800 ms later | the payload is hashed every 500 ms; any change (a label, a capability, a device) goes out now |

Every advert is followed by the board's **WDP‑DA device list** (§3), one frame per 25 ms. The list is
also sent on its own, plus one re‑send, whenever it changes (a device is saved, goes quiet or is
forgotten).

Facts go **stale** after `WDP_TTL_MS` = 180 s (~3 missed adverts). Staleness is display state —
the record stays in RAM until overwritten or `?WDP,CLEAR`.

---

## 3. Wire format

```
structCommand[200]:
+----------------------+
| 'W'  (0x57)          |  magic
| version (0x01)       |  WDP protocol version
+----------------------+
| TLV | TLV | TLV | ...|  until 0x00 terminator or end of field
+----------------------+

each TLV:  [ type : 1 ][ len : 1 ][ value : len bytes ]
```

Unknown TLV types are skipped via the length prefix, so an added TLV never breaks an older
peer’s parse.

**That is not the whole compatibility story, though.** A TLV whose meaning is *structural* —
one that changes what the packet **is**, rather than adding a fact to it — must be understood
by every receiver, because skipping it yields a wrong answer rather than a partial one.
`0x11` **SOLICIT** is the case in point: a solicit is byte-identical to an advert at the packet
layer (same magic, same proto, same WDP packet type) and carries no TLVs of its own. A receiver
that skips the unknown `0x11` decodes it as an *empty advert* and, because a board is the sole
authority for its own facts, replaces that board’s neighbor record with a blank one. Check for
SOLICIT **before** decoding, and return without touching the table
(`WCB_WDP.cpp` `wdpOnAdvertReceived`, `WCB_Client.cpp` `_handleWdpAdvert`).

### TLV registry (as shipped)

| Type | Name | Value | Sent by |
|---|---|---|---|
| `0x00` | END | terminator | — |
| `0x01` | ALIAS | board alias, ≤24 chars | WCB |
| `0x03` | FWVER | firmware version string, ≤27 | WCB + client |
| `0x04` | HWVER | numeric hw id (1, 21, 23, 24, 31, 32) | WCB |
| `0x05` | CAPFLAGS | uint16 LE capability bitmap (below) | WCB |
| `0x06` | MAESTRO | list of locally attached Maestro device IDs | WCB |
| `0x09` | PORTLABEL | `[port 1‑5][label bytes]`, one TLV per labeled serial port; unlabeled ports fall back to the type of the port's first‑heard saved WDP‑DA device | WCB |
| `0x0A` | CTRLID | controller (special‑peer) id this board links to | WCB, only when linked |
| `0x0B` | DEVTYPE | device type name — marks the sender as a **client device**; doubles as its display name | client |
| `0x0C` | HWREV | hardware revision string, ≤15 | client |
| `0x0D` | CAPTAGS | space‑separated capability tags, ≤48 | client |
| `0x0E` | MAESTRO_CFG | `[id][baudCode]` pairs — Maestro id+baud, for remote-proxy auto-config | WCB |
| `0x0F` | WLED_CFG | `[id][baudCode]` pairs — WLED id+baud, for remote-proxy auto-config | WCB |
| `0x10` | PWMTARGET | `[targetWCB][port]` pairs — this board's REMOTE PWM outputs; each named board self-configures that output port | WCB |
| `0x11` | SOLICIT | len 0 — a bare "advertise now" request (`?WDP,POLL`); carries no facts, receivers reply with a jittered advert and never record it | WCB |
| `0x12` | FLAGS | `[flags:1]` advert-flags bitmap. Bit `0x01` **TEMPORARY** = "adopt me as a **temporary** peer" — live so the mesh can reach it, but never persisted, evicted on silence, gone on reboot. For occasional devices (e.g. a management relay) | client (or WCB) |
| `0x13` | SEQHASH | `[hash:4 LE]` FNV‑1a over the board's stored‑sequence `key_list` **and every stored value** — a fingerprint of what sequences the board has, contents included, so an in‑place edit moves it too. A consumer caches what it pulled and re‑pulls only when this changes. Absent (`0`) means the firmware predates the TLV; an **empty** inventory is `0x811C9DC5`, not `0`. See [`SEQUENCE_INVENTORY.md`](SEQUENCE_INVENTORY.md) | WCB |
| `0x40–0xFE` | *reserved* | vendor / future | — |

*(Draft types `0x02 ROLE`, `0x07 CONTROLLER`, `0x08 HEALTH` were never shipped — see §10.)*

**CAPFLAGS bits:** `0x0001` HCR · `0x0002` MP3 · `0x0004` WLED · `0x0008` Kyber‑local ·
`0x0010` Maestro‑remote · `0x0020` PWM · `0x0040` Controller‑link · `0x0080` Maestro‑host ·
`0x0100` DFPlayer.

Wire strings are scrubbed on receive (`,`/`]`/control chars → `_`) so they can't corrupt the
machine‑readable dump lines (§7).

### WDP‑DA device‑list frames (`PACKET_TYPE_WDP_DA = 17`)

A board's saved serial‑attached devices (§5), in `structCommand[200]` of the same ETM struct:

```
[0] 'D' (0x44)  magic        [1] 0x01  frame version
[2..5] listHash (uint32 LE)  [6] frameIdx   [7] frameCount   [8] recordCount
then records until a 0 byte (port 0 = end) or the end of the 200 B:
  [port 1-5][flags][tLen][type ≤24][fLen][fw ≤27][hLen][hwRev ≤15][cLen][capTags ≤48]
flags bit 0x01 = LIVE (heard within the last 90 s)
```

A record is at most 120 B, so any record fits one frame; records pack greedily in list order (port by
port, first‑heard first) and a long list spans frames (at most 20). `listHash` is FNV‑1a over every
record's bytes, LIVE flag included, then the record count — so a device going quiet changes it too. An
empty list is one header‑only frame, which is how a receiver learns every device was forgotten.

A receiver assembles all `frameCount` frames of one `listHash` before it shows the list, replacing the
sender's previous one; a lost frame leaves the previous list in place, never half of a new one, and the
next send completes it. A `listHash` it already shows is ignored, so the per‑advert re‑sends cost only
the decode. Receivers keep neighbors' lists in a shared 32‑record RAM pool (`WDP_DA_POOL`) — not
persisted; the owning board has them saved and re‑sends them in its boot burst. A list that doesn't
fit the pool is dropped (logged once) and the one already shown stays. The same record encoding is the
NVS blob (`wdp_da`/`list`: `['D'][0x01][count]` + records, LIVE flag unused).

---

## 4. Neighbor table

`wdpNeighbors[MAX_WCB_COUNT]` (RAM‑only, indexed by `wcbNumber‑1`): alias/devtype, fw, hw
version/revision, capFlags/capTags, controller link, Maestro IDs, port labels, `isClient`,
last‑advert age, confirmed/stale.

Processing rule: an advert **replaces the sender's record wholesale** — the board is the sole
authority for its own facts, so removals happen naturally on the next advert. The *descriptive*
table is deliberately **not persisted** (it re‑learns within one advert cycle); what persists is
peer **membership** (§6).

---

## 5. The three announcer types

1. **WCBs** — advertise automatically when WDP is on (default).
2. **WCB_Client devices** (NaviCore, Sabé, MaestroSim, …) — call `setIdentity(type, fw, hwRev,
   caps)` (library ≥1.7.0) and the same advert goes out over the mesh; consumers see
   `isClient=true` with DEVTYPE/HWREV/CAPTAGS. Since 1.8.0 clients also **decode** adverts
   (`onNeighbor`/`getNeighbor`/`neighborCount`), and since 1.9.0 they **auto‑join** boards they
   hear (§6) — the client twin of everything in this document.
3. **Serial‑attached devices** — anything wired to a WCB serial port announces with a one‑line
   `@WDP1 {json}` every 25–30 s (see `WDP_DEVICE_ANNOUNCE.md`). The WCB keeps one record per
   port **and type** — up to `WDP_DA_PER_PORT` (4) per port, so boards chained on one port are each
   tracked (`?WDP,DA` to inspect).
   - **Confirmed by a second announce.** A device heard once is RAM‑only and dropped if not heard
     again within 90 s — the same idea as auto‑join's two‑advert vetting (§6): chained boards can
     garble each other into a line that still parses, and a record that is kept for good must not
     come from one such line.
   - **Persistent.** A confirmed record is saved to NVS (`wdp_da`) and kept when its device goes
     quiet (90 s without an announce: shown as not heard, still listed), and across reboots —
     reloaded as "not heard since boot". Only `?WDP,DA,FORGET` / `?WDP,DA,CLEAR` removes one; a
     newcomer on a full port may replace a device heard only once, but never a saved one, and is
     refused (logged once) until one is forgotten.
   - **Advertised to every neighbor**, in the board's device‑list frames (§3), so `?WDP,<n>` and
     `?WDP,DUMP` on any board list every board's devices, and the Wizard mesh view shows them.
   - The type of the port's **first‑heard** confirmed record — heard or quiet — fills its PORTLABEL,
     so the label holds still while several devices take turns announcing, and a Maestro plugged
     into WCB 4 shows up mesh‑wide by name with zero config. A `?LABEL` replaces only that name.

---

## 6. Dynamic peer membership + auto‑join

Historically the peer set was the contiguous range `1..WCBQ` and adding a board meant touching
every board's quantity. As built, each board maintains an explicit **membership set**:

```
active peers = {1..WCBQ}  ∪  {learned peers}  ∪  {temporary peers}  ∪  {controller/special peer}
               (the floor)    (WDP auto-join)     (WDP TEMPORARY)       (tracked separately)
```

- **Auto‑join** (default **ON**, `?WDP,AUTOJOIN,ON|OFF`, persisted): when a board hears a device
  advertise **twice**, it registers it as an ESP‑NOW peer **live** and adds it to membership.
  Regular WCBs **and** client devices both auto‑join (both force the derived MAC, so the peer is
  reachable from its id alone); the controller id is never auto‑joined (handled by the controller
  path, §9). A device that advertises the TEMPORARY flag (§3) joins as a *temporary* peer instead
  (below).
- **Learned peers are permanent.** Membership is persisted to NVS (`learned_peers`: schema
  version + MAC‑octet fingerprint + 20‑bit mask) and restored on every boot. Heartbeats drive
  online/offline as always, but membership never self‑evicts — a powered‑down board stays a
  member and simply shows offline until it returns. Cleanup is deliberately the operator's call:
  `?WDP,FORGET,<id>` (one) or `?WDP,CLEAR` (all learned). Changing the mesh MAC octets discards
  the saved membership (the fingerprint no longer matches).
- **Temporary peers.** A device can advertise the `FLAGS`/TEMPORARY bit (§3) to say
  *"adopt me, but don't keep me."* It registers live like a learned peer (so the mesh can reach
  it) but is **never persisted** to `learned_peers`, is **gone on reboot**, and is **evicted after
  ~50 s of silence** (`del_peer` — keeps the 20‑slot ESP‑NOW table lean; matches the `WCB_Client`
  temporary‑neighbor TTL so it clears the WCB roster as promptly as a NaviCore's). A device that was a
  permanent learned peer and then starts advertising the flag is **downgraded** to temporary. Use
  it for occasional devices — e.g. a management relay you connect now and then — that shouldn't
  become a permanent fixture; `?WDP,FORGET` / `?WDP,CLEAR` drop them like any peer. They show
  `PEER=4` ("temporary") in `?WDP,DUMP` and the Wizard mesh panel.
- **WCBQ is the floor, not the ceiling.** It still pre‑registers `1..WCBQ` at boot (useful so a
  fresh board isn't peerless before the first advert), and a live `?WCBQ` change reconciles
  registrations without a reboot. Run WCBQ=1 for a purely learned mesh.
- All ETM machinery (offline sweep, broadcast expected‑ACK set, retries, stats, load test) runs
  off the membership set. In‑flight messages evaluate against their own send‑time ACK snapshot,
  so membership changes can't race a pending broadcast. A learned peer is not counted against
  broadcast completion until it has ACKed at least once (protects mixed fleets with pre‑WDP
  firmware). Any ACK counts, including one that arrives after the configured boards' ACKs
  already resolved the broadcast: that is the usual order for an unproven peer, which the
  broadcast does not wait for (`etmProcessAck`, tracker #96).

This all works because WCB MAC addresses are **derived, not learned**: every board and client
forces its radio MAC to `02:<oct2>:<oct3>:00:00:<id>`. Knowing a board's number is knowing its
address, so "add a peer" is a pure local `esp_now_add_peer` — no handshake needed.

---

## 7. Commands + Wizard integration

| Command | Effect |
|---|---|
| `?WDP` / `?WDP,LIST` | human‑readable neighbor list |
| `?WDP,<n>` / `?WDP,DETAIL,<n>` | one neighbor in detail |
| `?WDP,STATUS` | `[WDP:en,autojoin,proto,neighbors,peers]` one‑liner |
| `?WDP,DUMP` | machine‑readable dump for the Wizard (below) |
| `?WDP,DA` | this board's serial‑attached (WDP‑DA) devices per port, incl. ones heard once |
| `?WDP,DA,FORGET,S<n>[,<type>]` | forget one device on a port (type as listed, any case), or all of the port's (RAM + NVS; neighbors drop it on the list's re‑send) |
| `?WDP,DA,CLEAR` | forget every serial‑attached device on this board |
| `?WDP,POLL` | advertise now + broadcast a SOLICIT so every board re‑advertises (fast convergence; skips the 60 s wait) |
| `?WDP,ON` / `?WDP,OFF` | enable/disable WDP (persisted; default ON) |
| `?WDP,AUTOJOIN[,ON\|,OFF]` | auto‑join learned peers (persisted; default ON) |
| `?WDP,ADD,<id>` | manually add a learned peer (same as hearing it) |
| `?WDP,FORGET,<id>` | drop one learned peer (RAM + ESP‑NOW + NVS) |
| `?WDP,CLEAR` | drop all learned peers + wipe the neighbor table |
| `?PEERSLIVE` | read‑only: live membership count (also emitted in config pulls) |

**DUMP format** (one line per neighbor, `PEER`: 0 = not a member, 1 = WCBQ floor, 2 = learned,
3 = self, 4 = temporary):

```
[WDP:N=..,CLIENT=..,ALIAS=..,HW=..,HWREV=..,FW=..,CAP=....,CTRL=..,CAPTAGS=..,MAESTRO=..,AGE=..,SEEN=..,PEER=..]
[WDPIF:N=..,S=<port>,DEV=<label>]          ← one per labeled/detected port
[WDPDA:N=..,S=<port>,TYPE=..,FW=..,HW=..,CAPS=<tags>,SEEN=<0|1>,AGE=<s|->]
                                           ← one per saved WDP-DA device on board N's port, any board,
                                             first-heard order; SEEN=1 = heard in the last 90 s; AGE =
                                             s since heard (this board only, "-" = not since boot or
                                             a neighbor's); "" = not sent, CAPS space-separated
[WDPX:N=..,MB=<id@baud.…>,WL=<id@baud.…>]  ← per board hosting Maestro/WLED: the per-device baud the
                                             main line omits, plus the full WLED list (`-` = none)
[WDPSEQ:N=..,HASH=<8 hex>]                 ← stored-sequence fingerprint (see SEQUENCE_INVENTORY.md)
[WDPPWM:N=<src>,DST=<dst>,S=<port>]         ← a remote-PWM drive edge: board <src> drives WCB <dst>'s S<port>
[WDPCFG:EN=..,AUTOJOIN=..,PEERS=..]
[WDP:END,count=..]
```

The self row is emitted first, flagged `PEER=3`. `WDPDA`/`WDPX`/`WDPSEQ`/`WDPPWM` are separate
lines (not new fields on `[WDP:...]`) so older Wizards ignore them instead of failing to parse the record; only
edges *touching the queried board* are reconstructable from one dump (a board keeps just the
`PWMTARGET` entries that name itself), so the full graph is assembled across per‑board pulls.

**Wizard:** the *WDP Mesh* panel renders the dump — every neighbor with kind/platform/fw/caps/
Maestros (with baud)/remote WLED/remote‑PWM wiring/port devices/membership, plus an auto‑join
toggle, per‑row Forget for learned peers, and Clear‑learned. Under each port it lists the
serial‑attached devices from `[WDPDA:…]` (dimmed when not heard), each with a ✕ that forgets it on
its own board — directly, or relayed through `MGMT,FRAG` for another board. The General section shows a
read‑only "mesh: N live peers" badge next to WCB Quantity (from `PEERSLIVE` in the config pull).

---

## 8. Security

Everything WDP does sits behind the inbound gates, in order:

1. **MAC‑group check** — source octets 2/3 must match this installation (all packet types).
2. **Password** — the ETM struct password must match.
3. **Sender validity** — id in range, not self.
4. **Sender‑MAC binding** — the claimed sender id must equal the source MAC's last octet
   (possible because all MACs are derived). A rogue in‑group node can no longer claim another
   board's id to fake an ACK, flip online state, spoof a controller advert, or trigger auto‑join.
   The `WCB_Client` library (≥1.9.0) enforces the same rule.

Auto‑join additionally requires **two** adverts before acting, so a single stray packet can't
inject a peer, and a learned peer only carries *membership* — an advert can never supply a MAC or
redirect traffic (addresses are always derived locally).

Like CDP, adverts are cleartext identity/capability broadcasts — acceptable for a hobby mesh,
noted here for completeness.

---

## 9. Auto‑configuration (shipped behaviors)

On **first learn** of a client device whose DEVTYPE is a controller (`NaviCore`, `Sabé`/`Sabe`):

1. If no controller peer is configured (`specialPeerEnabled` false), enable it pointed at the
   sender — same effect as `?CONTROLLER,ON,<id>`, registered live, no reboot. A manually pinned
   controller is never overridden.
2. If this board has a physically attached Maestro (and isn't the Kyber‑local host), flip
   Maestro‑remote on so the controller can drive it over the mesh.

On **every advert** from a confirmed peer whose `PWMTARGET` TLV (§3) names this board as a
remote **PWM output** target: if that port isn't already a PWM output and isn't reserved
(`canUsePWMOnPort`: a local Kyber's own port, a Maestro‑remote board's S1, or a device or
local‑Maestro port), reserve/configure it live — pin set + persisted to NVS, no reboot. Receiver-side
(the target owns its own config), so a board that was powered off when the mapping was created
still self-configures the instant it hears the advert. Idempotent and **self-healing**: the
auto-configured port is tagged (persisted) with its driving board, and when that board's *fresh*
advert stops naming the port (the mapping was deleted) the receiver clears its stale output
config itself — dropping the port from the list + NVS and re-enabling that port's broadcasts — so
a deletion made while the receiver was offline no longer strands the port forever waiting on a
`;MAP,PWM,CLEAR,OUT` push it may have missed. As with the manual clear (which reboots), the pin is
fully returned to plain serial on the next reboot; the self-heal deliberately does **not** force
one — a board shouldn't reboot itself because a *peer* dropped a mapping. Only WDP-tagged ports
self-heal; a manually configured PWM output is never auto-removed. The other hardware port of a
Kyber‑local board is not reserved, so an advert configures it like any port. A refused port is
skipped silently and retried on every advert, so a peer mapping that still names a port the Kyber
has just moved off re-claims it at that peer's next advert (the ~60 s backstop at the latest).

On **every** `;H` / `;A` / `;D` trigger, **single‑owner capability routing** (`routeStoredOrCap` →
`wdpCapOwner`) resolves the command to exactly one host: a persisted/pinned host if it is set and
online, otherwise the lowest‑numbered **online** board advertising the capability (HCR / MP3 /
DFPlayer), so
a broadcast can't fire the trigger N times. A pinned host that is *offline* fails over to live
election instead of black‑holing. WLED and Maestro are **id‑addressed** (`;L<id>` / `;M<id>` route
per‑id to the board that advertised that id), so they need no single‑owner election.

On **first learn** of a peer‑hosted Maestro or WLED, its `id → board @ baud` is auto‑added as a
remote proxy (`maestroAutoAddRemote` / `wledAutoAddRemote`) from the `MAESTRO_CFG` / `WLED_CFG`
TLVs — first‑host‑wins, persisted. No port field is needed in the TLV: remote Kyber bytes are
broadcast and the target board owns its own port. A **Kyber‑local** host additionally folds a
newly‑learned remote Maestro into its live `kyberTargets` (add‑only), so it forwards to the
just‑discovered board with no manual `?KYBER,LOCAL` re‑issue.

Plus the membership auto‑join of §6.

---

## 10. Future work (designed, not built)

*(Single‑owner capability routing (HCR/MP3), Maestro/WLED `id → board` auto‑config, and
temporary peers — once listed here — have shipped; see §9 / §6. The temporary idea
generalized the old "management‑peer 19" sketch into a per‑device `FLAGS`/TEMPORARY advert bit,
so any device can opt in regardless of id.)*

- **Generic capability addressing** — a syntax to address any command to a *capability*
  (`"whoever has X"`). Today only the ID‑less HCR/MP3 triggers auto‑resolve to a single owner;
  there is no general `;@<cap>` addressing form, and the Wizard has no surface to view or pin
  which board currently owns a capability.
- Draft TLVs / ideas not shipped: ROLE (`0x02`) and HEALTH (`0x08`) TLVs, and descriptive‑table
  persistence (deliberately a non‑goal — §4).

---

## 11. Pointers into the code

- Firmware: `Code/WCB/WCB_WDP.cpp` / `.h` (advertise, decode, neighbor table, WDP‑DA, commands),
  `Code/WCB/WCB.ino` (carrier structs, receive gates + queue, membership arrays,
  `addActivePeer`/`removeActivePeer`, `learned_peers` NVS, `?PEERSLIVE`). WDP‑DA:
  `wdpDaHandleLine` (announce → record), `wdpDaTick` (quiet / heard‑once drop, NVS save),
  `wdpDaBuildFrame` / `wdpDaOnFrameReceived` (the device‑list frames), `wdpDaCommand` (forget).
  The serial task and `loop()` share the table under `wdpDaLock()` — a scheduler suspend, because
  both run on core 1 and a critical section would hold off the soft‑serial RX ISR.
- Client library: `WCBClient` repo, `src/WCB_Client.{h,cpp}` — `setIdentity`, `onNeighbor`,
  `getNeighbor`, `neighborCount`, `setAutoJoin`, `forgetPeer`, `clearLearnedPeers`;
  `examples/NeighborDiscovery`.
- Wizard: `Wizard/app.js` (`parseWdpDump`, `renderWdpMesh`, mesh actions), `Wizard/parser.js`
  (`PEERSLIVE`).
- Serial device announce: [`WDP_DEVICE_ANNOUNCE.md`](WDP_DEVICE_ANNOUNCE.md).
- Stored-sequence inventory (the `SEQHASH` TLV and the pull it triggers):
  [`SEQUENCE_INVENTORY.md`](SEQUENCE_INVENTORY.md).

---

## 12. Revision log

| Date | Change | Commit |
|---|---|---|
| 2026-09-28 | **A learned peer's late ACK promotes it.** `etmProcessAck` promoted a learned peer only for an ACK that matched a still-pending entry, so one that was only ever broadcast to, whose ACK usually lands after the configured boards resolved the entry, was never counted or retried (tracker #96). | `cc231ba` |
| 2026-09-27 | **The advert stagger uses the board's own number.** `setup()` loaded `WCB_Number` after `wdpBegin()`, so the backstop phase was computed from the default 1 and every board advertised in WCB1's slot, in lockstep when powered together. `WCB_Number` now loads first; the same move fixes saved PWM outputs to W1 reloading as local ports (WCB coverage re-scan #1, #16). | `cc2a8a9` |
| 2026-09-23 | **PWMTARGET auto-config can claim the free hardware port of a Kyber‑local board.** `canUsePWMOnPort` now reserves only the port a Kyber mode owns (the Kyber's own port; S1 under Maestro REMOTE — `kyberModeReservesPort`, WCB_Storage.cpp), so the other hardware port takes an auto-configured PWM output like any port; before, it was refused along with the Kyber port (tracker #73 D4, HIL `kyber.local_free_port_takes_pwm`). Nothing changes on the wire. | `95dd811` |
| 2026-09-23 | **WDP‑DA devices are persistent, advertised to every neighbor, and forgettable** (issue #19 follow‑up). A device is confirmed by its second announce (heard once = RAM only, dropped after 90 s: a record kept for good must not come from one collision‑garbled line); a confirmed one is saved to NVS `wdp_da`, reloaded at boot as "not heard since boot", and kept when it goes quiet — still listed (`SEEN=0`) and still naming its port. It leaves only through the new `?WDP,DA,FORGET,S<n>[,<type>]` / `?WDP,DA,CLEAR` (and a Wizard ✕); a full port no longer evicts a saved device, it refuses the newcomer. The whole list goes to every neighbor as **`PACKET_TYPE_WDP_DA` (17)** device‑list frames — a new type because old firmware and `WCB_Client` drop unknown ETM types, while on type 12 an old board would read it as an empty advert — assembled all‑or‑nothing per list hash into a 32‑record pool; `?WDP,<n>` and every board's `?WDP,DUMP` now list every board's devices. `[WDPDA:…]` gained `SEEN=` and `AGE=-`. Host test covers the frame codec and assembly. | `ef4381d` |
| 2026-09-22 | **WDP‑DA keeps one record per port *and type*, up to 4 per port** (issue #19). One record per port meant boards chained on one port overwrote each other: `?WDP,DA` showed whoever announced last, and an unlabeled port's PORTLABEL flipped on every announce (~every 14 s for two boards), each flip costing an advert plus a re‑send. The label now comes from the port's first‑heard live record, so it holds still; a full port replaces the record heard from least recently. New self‑only `[WDPDA:…]` dump record with each device's type/fw/hw/caps/age. Announces must now be one whole line (end in `}`, no second `@WDP`) so a collision‑garbled line can't leave a phantom record. Also fixed in passing: TTL expiry compared ages unsigned, so a refresh landing just after `wdpDaTick` read `millis()` expired a device that had just announced. Nothing changes on the wire. The DUMP block above also gained the missing `WDPSEQ` line and `WDPCFG`'s `EN=`. | `95dd811` |
| 2026-08-19 | **A structural TLV is not forward-compatible by skipping.** `WCB_Client` predated `0x11` SOLICIT and decoded one as an empty advert, so every `?WDP,POLL` / "Poll mesh" blanked the sending board’s alias, port labels, capability flags, Maestro ids and seqHash in the client’s roster until that board’s next real advert (up to 60 s). Added the same solicit-first guard the firmware has, plus the missing other half — the client now **answers** a solicit, arming a jittered advert from `_wdpTick()` rather than sending inline (`_handleWdpAdvert` runs on the WiFi-task receive callback). `WCB_Client` 1.15.1. | `8455484` |
| 2026-08-17 | **SEQHASH now covers stored VALUES, not just `key_list`.** A keys-only hash never moved when a sequence was edited in place, so every peer kept a stale copy while believing it current — the exact failure the fingerprint exists to prevent. Cached in RAM and invalidated at each write path, because the WDP dirty-check rebuilds the advert twice a second and hashing values uncached would mean N NVS reads at 2 Hz. Mixed fleets are fine: the contract is only "if it changes, re-pull", so an older board simply doesn't signal value edits. | `80f44d9` |
| 2026-08-17 | Added TLV `0x13` **SEQHASH** — 4-byte stored-sequence inventory fingerprint, advertised before PORTLABEL so it survives a full payload. Names themselves are **not** advertised (~16 B each would evict the port labels from the fixed 200 B payload); they are pulled on demand — see [`SEQUENCE_INVENTORY.md`](SEQUENCE_INVENTORY.md). Decoder + `WdpNeighbor::seqHash` in firmware and `WCB_Client`; new `[WDPSEQ:N=,HASH=]` record in `?WDP,DUMP`; round-trip and absence-semantics coverage in `tests/wdp_wire_test.cpp`. | `bbd6bdf` |

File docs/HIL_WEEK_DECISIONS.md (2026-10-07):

# The away week (2026-09-27 to about 2026-10-04): decisions and full HIL runs

Greg, leaving on 2026-09-27: *"Can you make sure you're always working towards this goal this week and make any
decisions needed. Just track them so I can review when I return."* The goal: *"a complete hil tool that tests the wcbs,
navicore and intellex fully. All features of every system should be testable. Use playwright testing to test webpages
and functionality of that."*

Every decision that would normally have been his is recorded here, newest last, with how to undo it, and every
full HIL run of the week is logged below with a short summary (Greg: *"keep track of all the full hil tests you run
through the week as well with a brief summary of them"*). The work itself is tracked in
[HIL_TEST_AUDIT.md](HIL_TEST_AUDIT.md) §6 (plan and progress notes) and the commits it names.

## What Greg decided before leaving

- Servos may move all week. The bench GUI may be stopped. Firmware may be changed and flashed, NaviCore included.
- WCB work is pushed to `WIFI`, never to WCB `main` (which publishes a release). NaviCore, Intellex, WcbCmd and
  WCBClient may be pushed to `main` (NaviCore `main` republishes the production config tool).
- The dev mesh password in the WCBClient MgmtRelay example stays (F17 closed).
- Scheduled check-ins keep the work going; they live in the Claude session in VS Code, which must stay open.

## Decisions

| # | Date | Decision | Alternatives considered | Why | How to undo | Where |
|---|---|---|---|---|---|---|
| D1 | 2026-09-25 | WcbCmd shipped as **0.9.1**, not a re-used 0.9.0, and **not tagged** (so the Arduino Library Manager still offers 0.7.0). | Keep 0.9.0; tag 0.9.1. | 0.9.0 was already public with both bugs; a tag publishes a Library Manager release, which Greg had not asked for. | `git tag 0.9.1 0ab4af5 && git push origin 0.9.1` to publish. | WcbCmd `0ab4af5` |
| D2 | 2026-09-25 | WcbCmd #2's 200 ms stale-partial timeout shipped as bench-verified, with its limit documented (a WCB `loop()` stall over 200 ms mid-frame drops that frame), rather than redesigned. | Rescan for `7E` on a tail failure, which would remove both the timeout and the limit. | The shipped version had passed on the bench; a redesign could not be HIL-verified that day. | Revisit with the rescan approach. | WcbCmd `docs/WCB-INTEGRATION.md` Phase 5 |
| D3 | 2026-09-27 | All HIL tests for all three systems (WCB, NaviCore, Intellex, and their Playwright specs) live in this repo's `tests/`, run by one `run.py` and one GUI. | Put NaviCore/Intellex tests in their own repos. | One bench, one runner, one report: the goal is one complete tool. | Move a suite later; the runner loads suites by path. | `tests/` |
| D4 | 2026-09-27 | Check-ins every 3 hours (session cron), work chained continuously in between; usage paced so the weekly limit does not stop the week. | Once or twice a day. | A usage limit then costs hours, not half a day. | `CronDelete` the job in the session. | session job `c6b3f811` |
| D5 | 2026-09-27 | F23 fixed as recommended: every PWM output pulse (local passthrough and `;P`) is one RMT symbol on a per-port channel, so preemption cannot stretch it; with no channel free the port keeps the bit-bang and says so once. | Re-pin PWMTask to core 1 (a mitigation only: a flash write stalls both cores). | The 1830-for-1000 us pulse was the one a digital servo holds. | Revert the `pwmPulse()` commit; the fallback image is `results/builds/wcb-esp32-meshq-f21`. | tracker #94 |
| D6 | 2026-09-27 | A full HIL run (everything, servos on) at least once a day, overnight when the bench is idle, and after each phase; each one logged below. | Only targeted runs. | Catches cross-suite regressions the targeted runs miss; the bench is otherwise idle at night. | Stop scheduling them. | the run log |
| D7 | 2026-09-27 | The nightly full runs use `bench.json`'s opt-ins exactly as Greg ticked them, attended ones included (`mesh_password` - never run before - `nvs_erase`, `wifi_pc`, the relay OTA re-flashes, `nvs_wear`, `seq_wipe`, the soak). | Leave the attended ones out while nobody is at the bench. | Greg ticked them and wants everything tested; each is recoverable over USB without hands: W1's mesh password from W2's chain (the same value), an erased NVS from W1's chain, an OTA by a USB flash; `wifi_pc` uses only the second adapter, not the one carrying the internet. | Untick them in `bench.json`. | `tests/hil/bench.json` |
| D8 | 2026-09-27 | The Intellex test plan's 14 recommendations (DX1-DX14) adopted as written: tests in `tests/intellex/` run by `suites/s32_intellex.py`; a staged copy of Intellex per test with `LOCALAPPDATA` pointed into the stage; three env hooks added to Intellex (`INTELLEX_OFFLINE`, `INTELLEX_SERIAL_ALLOW`, `INTELLEX_DISCOVER_HOSTS`); flashing only W2, with its own bench image; new Intellex opt-ins start unticked. Pushing Intellex `main` also published Greg's unpushed local commit `d615344` ("Wizard: reconnect the link at its own slot, not slot 1"). | Test through Playwright route interception only, with no Intellex change. | Background loops and Python-level tests need the same leash; each hook is a few lines and inert when unset. | Revert Intellex `e9f95f2`. | Intellex `e9f95f2` |
| D9 | 2026-09-27 | The NaviCore plan's decisions D-NC1 to D-NC41 are taken as recommended (`hil_plan/NAVICORE.md` §7): its config may be written only inside a guard that proves byte-identity afterwards; it is flashed by `?OTALOCAL`, esptool only for recovery; WCBClient then NaviCore `main` are pushed after a bench pass; the SBUS controller gets RAM-only test verbs, flashed locally and not pushed; credentials are filtered from the logs. Except D-NC37 (wire a third probe to NaviCore's pins), which needs Greg's hands and waits for him. | Decide each as the work reaches it. | They are well-argued, each with its undo, and the week has no one to ask. | Per row, in the plan. | `hil_plan/NAVICORE.md` |
| D10 | 2026-09-27 | Every real firmware defect the WCB re-scan confirmed (26, `hil_plan/WCB.md` §3) is fixed this week, high first, each proven by its test on the bench before it is pushed; the 12 Wizard defects are fixed with their specs. First: the PWM mappings loading before the board number, `?HW` accepting the other chip's pin map, and the race that drops a typed broadcast from the mesh. | File them for Greg. | He asked for decisions to be made, and a known defect with a proving test is cheaper to fix now than to rediscover. | Revert per commit. | `hil_plan/WCB.md` §3 |
| D11 | 2026-09-27 | Intellex's specs live in `tests/intellex`, beside `tests/wizard`; the NaviCore config tool's specs go in `tests/wizard` under `navicore/` (D-NC10), served from the same origin as the Wizard. | One folder for every browser test. | Intellex's pages are served by Intellex, not by `serve.js`, and need no Web Serial grant, so they do not share the Wizard folder's Chrome profiles or server. | Move the folder. | `tests/intellex` |
| D12 | 2026-09-27 | The re-scan defects are fixed in batches: each batch is one image, flashed once to W1 and W2, and each fix is proven by its own new test. The three high ones' tests run first on the unfixed image, to show each catches its defect. | One image per defect. | A flash plus the checks around it costs minutes per board, and the fixes and tests are independent. Seeing a test fail before the fix is the evidence it tests the right thing. | n/a (process). | `hil_plan/WCB.md` §3 status |
| D13 | 2026-09-27 | The delimiter setters (`?DELIM`, the legacy `?D<x>`) refuse `,` and letters and digits too, not only the two prefixes (re-scan #7, #8). | Refuse only the prefix collisions, as the plan said. | `,` splits every command's arguments, and only the legacy `?D^` got the board back. The legacy form takes any two-character line, so the typo `?DE` made `E` the delimiter and split `?DEBUG,ON`. | Delete the two checks at the end of `delimCharOk` (WCB.ino). | WCB.ino `delimCharOk` |
| D14 | 2026-09-27 | A received timer chain longer than a timer-queue slot (219 characters) is carried whole in a heap buffer (re-scan #22). Only a failed allocation or a full queue refuses one, and `loop()` reports it. | Refuse it with a message; make every slot bigger. | `WCB_Client` fragments any command over 188 characters, so a long `;T` show chain from NaviCore is legitimate. Bigger slots would cost that heap all the time, on a board with about 19 KB in AP mode. | Restore the slot-length refusal in `enqueuePendingTimerChain`. | WCB.ino |
| D15 | 2026-09-27 | #31, a passphrase that cannot end in a space: the comment is corrected; `?WIFI` is not exempted from the line trim. | Exempt `?WIFI` lines from the trim in all three readers. | An exemption would make a terminal's stray trailing space part of the credential, which locks the operator out more often than a passphrase that must not end in a space. | n/a | WCB_WiFi.cpp comment |
| D16 | 2026-09-27 | #23, the unbounded line buffer: the cap is per source, 4 KB on S1-S5 and 32 KB on USB. | One 4 KB cap, as the plan said. | A whole `?backup` chain is pasted on USB as one line and passes 4 KB on a board with many sequences. The risk #23 names is a device that never sends a line end. | Change `serialLineMax` (WCB.ino). | WCB.ino |
| D17 | 2026-09-27 | Two dangerous new tests run unattended because each gates itself. `chars.delim_collision_refused` sends `?DELIM,?`, which would need an erase-flash should the guard ever regress (DELIM is now exempt from the trailing-`?` help shortcut, which used to swallow it), only after two recoverable arms prove the guard in both setters. `seq.reserved_bookkeeping_keys` sends the save and clear that would corrupt the sequence list only after a harmless local recall is refused. | Attended opt-ins; the plan put WP44 behind `seq_wipe`. | An opt-in nobody ticks is a test that never runs. On unfixed firmware each stops at its gate with nothing unrecoverable sent. | Add `opt_in="seq_wipe"` (or a new opt-in) to either decorator. | s18, s17 |
| D18 | 2026-09-27 | The ETM load generator's start line and its new closing line ("complete: N frame(s) sent") print always, not under `?DEBUG`. | Keep them under `?DEBUG,ON` and turn debug on on W2 for the test. | They are the only sign the load ran: with ETM on, `?STATS` counts only tracked sends, and the load is untracked. Each peer prints them once per `?ETM,CHAR`. | Gate them on `debugEnabled` again in `processETMLoad`. | WCB.ino |
| D19 | 2026-09-27 | The serial reader (`serialCommandTask`) no longer writes `lastReceivedViaESPNOW` or `inSequenceBody`; `parseCommandGroups` takes the origin as arguments. This goes one step past the plan's #3. | Leave the reader's reset in place. | It is the last cross-task writer of the loop-prevention flag. Landing while `loop()` ran a mesh-received command, it made that command look local, for example a second mesh fan-out of a recall. Every path the reader feeds now states its origin. | Restore the two writes in `processIncomingSerial`. | WCB.ino, command_timer.cpp |
| D20 | 2026-09-27 | Two re-scan rows corrected on reading the code. #25's first half was not a defect: the "space" the untracked ETM sender wrote was a raw NUL byte in the source, shown as a space; it is now an escaped `'\0'`. #26 (strncmp password checks) also covers `otaPktAuth`, 13 sites, not 11. | n/a | The code is the source of truth. | n/a | `hil_plan/WCB.md` §3 |
| D21 | 2026-09-27 | The wiki edits for these user-visible changes wait for the `WIFI` to `main` merge that releases them: `?HW` refusing the other chip, `?MAC` validation, the delimiter rules, the 30-character `?LABEL`, stricter legacy spellings, `?STOP` from the mesh. The list is kept with the status in `hil_plan/WCB.md` §3. | Edit the wiki now. | The wiki describes the released firmware, and users flash from `main`. | Edit it now anyway. | `hil_plan/WCB.md` §3 |
| D22 | 2026-09-27 | NaviCore follow-up, filed and not done yet: `WCB_Client` should drop `ETMCHAR_` and `ETMLOAD` frames as the WCB firmware does. NaviCore writes unprefixed mesh text to its opted-in ports, and every `?ETM,CHAR` sends it some. | Fix it in the WCB phase. | It is a `WCB_Client` change, which ships with NaviCore's bench pass (D9); no NaviCore port is opted in by default. | n/a | `hil_plan/NAVICORE.md` findings |
| D23 | 2026-09-27 | #15, PWM against a serial mapping (the plan left the rule open): PWM is refused on a port a `?MAP,SERIAL` reads as its INPUT, at configure time only (`serialMapOwnsPort`). A mapping's destinations are checked by neither side. | Refuse destinations too; put the term in `canUsePWMOnPort`. | Symmetric with `?MAP,SERIAL`, which refuses a PWM port as its input only. `canUsePWMOnPort` also runs in the boot loaders, and the output loader erases a saved output on a refused port, so a pair saved by older firmware would lose its PWM at the next boot. | Add the term to `canUsePWMOnPort` (boot included), or check destinations in both. | WCB_PWM.cpp |
| D24 | 2026-09-27 | #15, devices against a local Maestro: the refusal is a new line of its own (`[HCR] S2 is a local Maestro's port - config blocked`), and the old `... already in use by PWM/Kyber/...` lines keep their exact text. | Add "Maestro" to the existing lines. | Tests and tools match the existing lines exactly. | Merge the texts and update the tests that pin them. | WCB_HCR/MP3/DFP/WLED.cpp |
| D25 | 2026-09-27 | An independent review of the whole firmware batch before flashing; its three firmware findings were checked and fixed. `?DELIM,?` printed the help page (the trailing-`?` shortcut), so DELIM joined FUNCCHAR and CMDCHAR in the exemption. An over-long line is dropped whole instead of running its head. A `?C`-first console chain takes the timer gate too. The fourth, the Wizard offering delimiters the firmware now refuses, went to the Wizard work. | Flash first, review later. | A batch this size goes onto both bench boards and then to users; a review is cheap next to a bad image. | n/a | this log |
| D26 | 2026-09-28 | This checkout's pre-commit hook launcher (`.git/hooks/pre-commit`, not versioned) finds its script through `git rev-parse --git-common-dir` instead of `--show-toplevel`/.git. The stamping script is unchanged. | Commit worktree work with `--no-verify`. | In a git worktree `.git` is a file, so the old launcher failed before stamping and blocked every worktree commit; skipping the hook would skip the version stamp it exists for. | Restore the old line (saved in the session scratchpad as `pre-commit.orig`). | `.git/hooks/pre-commit` |
| D27 | 2026-09-28 | After the re-scan batch is committed (the hook stamps a new version string), the bench boards are re-flashed from the committed tree, so the nightly full run exercises exactly the committed image and its version matches CI's build of that commit. | Leave the pre-commit build on the bench, as with F23. | Traceability: a board reporting a version then runs that version's code. | n/a | `results/builds/FLASHED.md` |
| D28 | 2026-09-28 | Wizard: a push that changes only `?WCBQ` asks for no reboot. The Wizard agent found that the plan's WP20 row (a WCBQ edit appends `^?reboot`) was wrong: `?WCBQ` applies live (`rebuildActivePeers`, `syncActivePeerRegistrations`). | Reboot anyway, as the plan said. | A needless reboot interrupts a running board; the firmware needs none. | Add `WCBQ` to the Wizard's reboot verbs. | Wizard `app.js` |
| D29 | 2026-09-28 | The SBUS controller's stalled replies are handled in the harness, not in the controller firmware. `sbus.to_navicore` failed in run `20260928-005805` with no `getcfg` reply. The session logs show the cause: in `20260922-095341` the same missing reply arrived 5.2 s late, just ahead of the next test's pong. The controller holds a reply in its USB outbox until the host sends another byte (its own comments describe the HWCDC `connected` latch, `SBUSController.ino` `serialOutboxPump`), and its UI's 3 s ping heartbeat is what releases it there. `SbusCtl` now pings every second while it waits, as that UI does; `selftest.py` `t_sbus_reply_nudged_by_ping` holds a reply until a ping arrives. The controller-side latch is recorded in `HIL_TESTING.md` §6, not fixed: any host must ping anyway to open its 5 s mirror window. The same investigation found the controller's boot banner prints its AP password as `Pass: <value>`, which `redact_text` missed; it is hashed now. |
| D30 | 2026-09-28 | Wizard W-1 to W-12 merged to `WIFI` after a review and a second round (`b57fe2a`, `975bcba`). Behaviour chosen on Greg's behalf: a push replays the character changes in the board's own order (DELIM, then CMDCHAR, then FUNCCHAR) from the board's live characters, and a change the board would refuse part-way is refused before anything is sent, with the two pushes that would do it named, rather than split into two pushes silently. A board still on `,` as its delimiter gets `<func>D<x>` first, and the push is refused while General still shows `,`. A device edit taken back puts the port back to what the board reported. Left open, recorded in `hil_plan/WCB.md` section 3: an edit to one mapping re-sends every mapping (a PWM input one reboots the board), a mapping removed while disconnected is never cleared, and a harmless `Invalid format` after a direct delimiter change. The eleven new no-board specs are registered in `s30_wizard.py`. |
| D31 | 2026-09-28 | Tracker #95 fixed rather than documented: a data-carrying verb in mixed case (`?Mgmt,`, `?Seq,`, `?Wifi,`, and FUNCCHAR, CMDCHAR, DELIM) keeps a trailing '?' like the upper- and lower-case spellings, and `;Seq<key>` recalls like `;SEQ<key>`. The dispatcher already takes every verb in any case, and the WiFi case silently lost a passphrase ending in '?'. Two s17 tests had pinned the old behaviour as observed, not as a design (no doc recorded it); they now check the fixed behaviour. Found by the s05 test writer (WCB-WP13). |
| D32 | 2026-09-28 | Two more of the wave's findings. Tracker #96 is fixed in the same image as #95: any ACK from a learned peer now proves it reciprocates ETM, where only an ACK matched to a still-pending entry did, so a peer that was only ever broadcast to could go unretried indefinitely. The s18 test that tolerated both race outcomes now requires the second broadcast to count the peer either way. Tracker #97 (a full NVS can leave a new mapping's or device's port blocked with nothing on it after a reboot) is deferred: it needs a nearly full NVS, it touches seven configure paths, and it deserves its own full-NVS bench test; the proposed fix is in the tracker. The 46 legacy spellings that match only all-upper or all-lower stay as they are: a mixed-case one answers `Unknown command`. |
| D33 | 2026-09-28 | NaviCore's recorder buffer is bench state the harness must leave as found. `navicore.rec_play_clip` played a saved clip and left it in the buffer, so the next night's run found 191 events there and skipped the test as "an unsaved take". The test now puts the buffer back (empty, or the saved clip it held) and treats a buffer that exactly matches a saved clip as that copy. The buffer the 20260927 run left was cleared once by hand (`?REC,CLEAR`, RAM only) to return NaviCore to its pre-week state. |
| D34 | 2026-09-28 | NaviCore INF4 (`hil/ncflash.py`), as its builder chose: an OTA flash keeps one 1 KB chunk in flight (the config tool keeps eight) and settles anything unexpected with `?OTALOCAL,STATUS`, aborting rather than rewinding a written slot; the recovery write is one esptool connection writing the app at 0x10000 and `boot_app0.bin` at 0xe000 with `--after watchdog-reset` (as Greg's flasher does), never 0x0 or 0x8000, and only when a caller passes `allow_esptool`; a build refuses library drift between the sketchbook and the repos, a changed FQBN, a core other than 3.3.4, or a tree that changed during the compile. INF3 (`nc_guard`) is bench-verified (`nccfg.guard_selftest`, the diff path, byte-identical). |
| D35 | 2026-09-28 | The NaviCore recovery ladder is proven end to end before any new NaviCore image is flashed, esptool included: a new image that does not boot can only be undone by the esptool write, and nobody is at the bench to recover a board this week. Done on the healthy board with both slots holding the same known-good image (after `ncflash`'s first OTA flash of that image into `app1`): the real `recover` ran with its PING and hard-reset rungs stubbed to fail, esptool wrote the image into `app0` and set otadata, and NaviCore came back on `app0`, config untouched (only app0 and otadata are written). |
| D36 | 2026-09-28 | Tracker #98 fixed in the next image: `?KYBER,LIST`'s copy-paste line for another board now matches the one `?KYBER,LOCAL` prints (each Maestro's own baud, from the Maestro table, and the label `Maestro <id>`). Display only, but the line is meant to be pasted, and pasted it re-bauded the other board's Maestro. The s14/s22 tests (25, WCB-WP15 rows 2-4, WP51, WP27, WP53) are merged; the plan's disagreements with the code are in their docstrings (a two-slot get reads the later slot; the PWM output count in NVS never shrinks; a WDP fold needs the proxy cleared first). |
| D37 | 2026-09-28 | Tracker #99 fixed in the next image: an HCR, MP3 Trigger or DFPlayer refuses a port a serial mapping reads, and a mapping refuses their ports as its input, the same rule PWM got in D23 (a WLED only transmits, so it is left out). Three low observations from the same tests are recorded under #99 and not changed. The s15/s24 tests (21, WCB-WP26, WP52, WP39) are merged; they use W2's `?ETM,OFF` on its own console (not the `?MAC,3` flip) to take W2 offline, and WCB19 as a pin never heard. `docs/WLED_INTEGRATION.md` §3-§4 now describe the shipped commands. |
| D38 | 2026-09-28 | The s14/s22 tests ran on `6.2.1_280727RSEP2026` (`20260928-073122`): 23 of 25 pass. `kyber.local_targets_one_write_per_port` skips on this bench (W1's table holds an `M3:W2S1` proxy, and the test will not remove it); left as a skip, since rebuilding W1's Maestro table in order is itself a risk to the bench (D12-era `restore_w1_maestro_order`). #98's first fix is corrected (a remote slot records no port). Tracker #100 (cleared devices and PWM outputs leave NVS keys; W1 grew by 21 entries, one time) is deferred with a proposed fix, like #97: it needs a per-device design, and nothing is lost meanwhile. |
| D39 | 2026-09-28 | Tracker #101 fixed in the next image: a line whose append the heap refuses is dropped whole like an over-long one, instead of running its head alone. The s12/s13/s16/s17 tests (16; WCB-WP32, WP49, WP50, WP33, WP44 row 2, WP55) are merged, and `var.clear_all_name_collision`, vacuous since #39 made 'all' reserved, is retired for `var.reserved_all_and_clear_all`. `input.usb_line_over_heap_dropped_whole` nearly exhausts W1's heap for a few seconds; it runs unattended unless it ever panics W1, which would move it behind an opt-in. |
| D40 | 2026-09-28 | NaviCore INF6 (`hil/ncmesh.py`) and NC-WP1 (35 `nccfg` tests) merged. The new `navicore_reboot` opt-in is ticked in `bench.json` for the nightly runs, like every opt-in Greg ticked (D7): a software restart of NaviCore, and every recovery rung is proven (D35). `navicore_fault` is not ticked until INF9's hook build exists and is reviewed (its hooks corrupt `/config.json` on purpose). `nccfg.boardtype_change_no_reboot` stays a normal test, as the plan has it: a crash in its few seconds would boot NaviCore on the other pin profile, from which its USB config restore still works. NaviCore findings D-NC42 (UTF-8 cut by `strlcpy`), D-NC43 (tapWindowMs above holdMs's cap), D-NC44 (a parked tap survives a config apply; `nc_guard`'s fallback is exposed, not this bench's defaults) are logged in NAVICORE.md with `(should)` tests for the first two; NaviCore itself is not changed this week unless a test needs it. |
| D41 | 2026-09-28 | NaviCore INF7 (the config-tool Playwright rig) and NC-WP3's no-board specs merged: 61 spec ids in `s49_navicore_tool.py`, all green headless (83 expected with the Wizard's, 15 of them `(should)` specs failing on purpose as `test.fail`). As its builder chose: the tool is served on its own origin (8779), every request off 127.0.0.1 is aborted so nothing reaches GitHub or the cloud store, Playwright's clock steps timeouts, and stand-ins replace esptool-js and CryptoJS. CI does not run the NaviCore specs yet: that needs a NaviCore checkout step in `wizard-tests.yml`, left for Greg. The tool defects the specs pin (D-NC30-D-NC35 and the new ones in NAVICORE.md) are NaviCore repo changes and are not made this week. |
| D42 | 2026-09-28 | WCB wave 3 group 1 merged (WCB-WP16, WP17, WP36, WP37, WP47). As its writer chose: the WiFi setter tests save a throwaway or derived AP name for at most 6 s with no reboot and replay W1's own `?WIFI` line (no opt-in), and only the AP-up-under-its-derived-name half is behind `wifi_modes`; the identity windows are short (W1 is WCB 3 for ~3 s, off its mesh group for one boot in the fingerprint test) and each restore is confirmed or fails with the commands to type. Latent, logged not fixed: `saveWifiSettings` and five other setters still ignore their NVS write results (the class of re-scan #20). |
| D43 | 2026-09-28 | D-NC6 refined: this week's NaviCore image (INF9's hooks plus Greg's uncommitted NaviCore work, taken as-is) is built from a NaviCore branch `hil-week` in its own worktree, and **nothing is pushed to NaviCore main or WCBClient master this week**. A NaviCore main push reaches users through the config tool's Firmware tab, and it would publish Greg's work in progress unreviewed; the bench needs only the local image. Greg's NaviCore checkout is left exactly as it is. The branch, the image and the suite's results wait for his review; pushing is then one command. |
| D44 | 2026-09-28 | WCB wave 3 group 2 merged (21 tests; WCB-WP14, WP18, WP28, WP38, WP45, WP46, WP56); no new firmware defect. Two opt-ins ticked in `bench.json` for the nightly runs, as Greg ticked every opt-in (D7): `etm_seq_wrap` (several minutes of mesh flood and one W2 reboot) and `navicore_fault` (INF9's hook image now exists and was reviewed; each hook test restores NaviCore's config under `nc_guard`, and a hook-free image skips them). NaviCore INF9 is built on the local `hil-week` branch (Greg's WIP reviewed: nothing half-written, all six changes already on the bench image) and `ncflash` gained a source directory (`ncflash-source`, merged). |
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

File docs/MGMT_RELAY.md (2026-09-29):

# MGMT relay: the remote config pull

How a requester (the Wizard, Intellex, the HIL harness, or a person at a terminal) reads the saved config of a board
it has no cable to. The requester talks to a **relay** (a WCB, or a WCB_Client host running WcbMgmt such as NaviCore
or the MgmtRelay example) over USB serial or a WebSocket; the relay talks to the **target** over ESP-NOW.
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

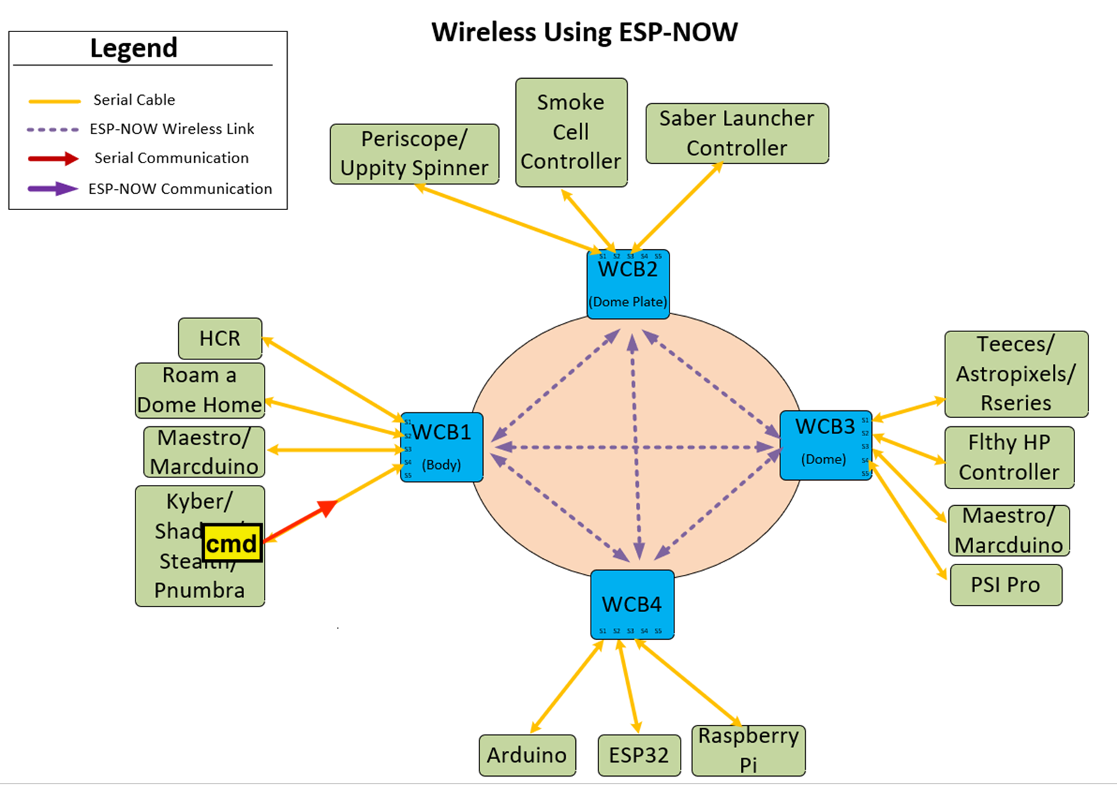
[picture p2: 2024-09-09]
Images/gif/Broadcasts/OverviewImage-3.png

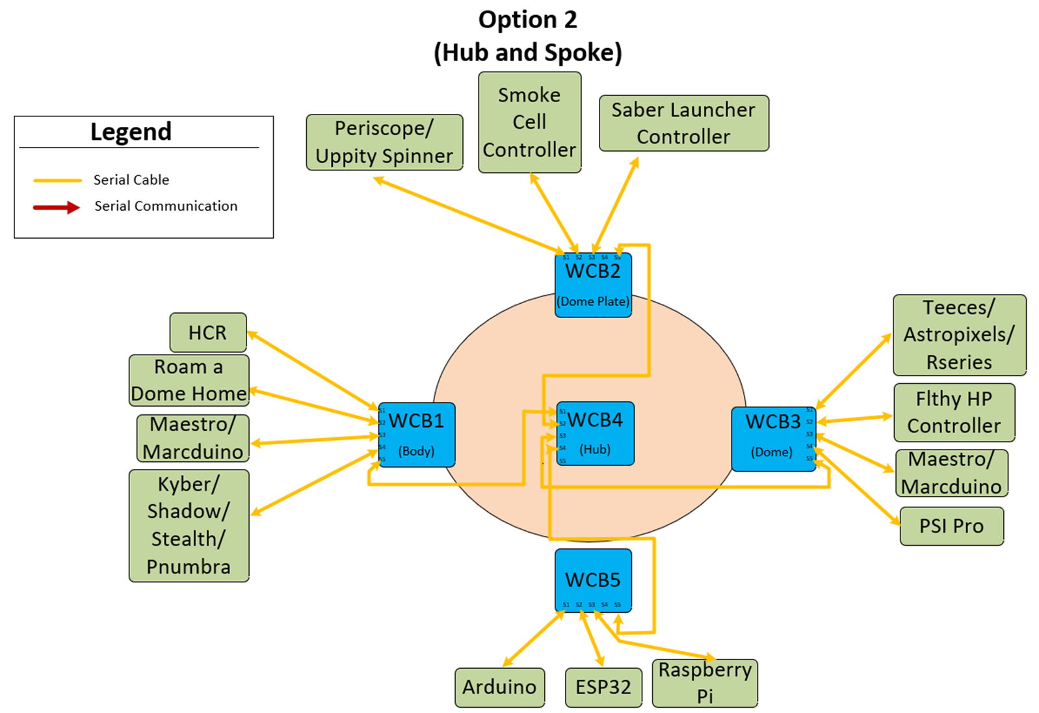
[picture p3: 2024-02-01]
Images/SerialOnlyConceptOption2.png

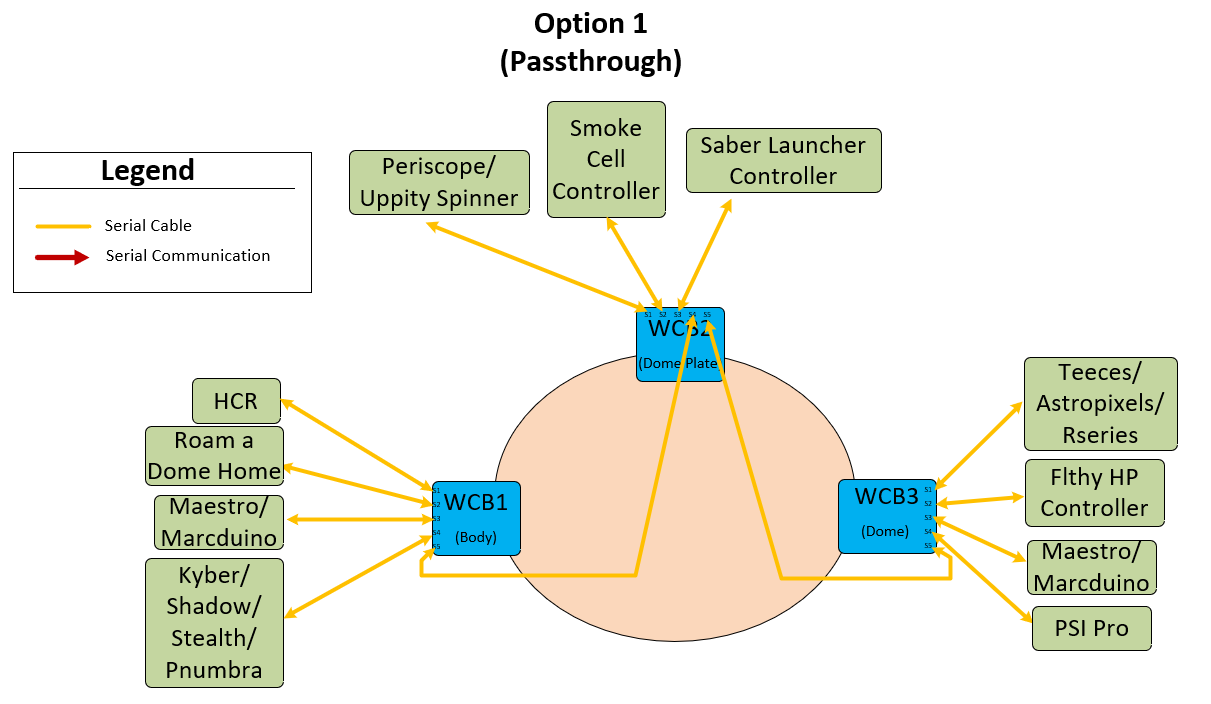
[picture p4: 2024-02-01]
Images/SerialOnlyConceptOption1.png

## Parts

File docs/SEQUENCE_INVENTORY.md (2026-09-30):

# Stored-Sequence Inventory

How a consumer — NaviCore, a browser UI, another controller — discovers **which stored
sequences exist** on the WCBs in a mesh, pulls any one of them in full, and pushes edits
and new sequences back.

The problem it solves: anything that offers "run a sequence" needs the list of sequences.
Hard-coding it goes stale silently the first time someone saves one from the Wizard.

Three operations, covered in §3 (list), §3a (fetch one), §3b (write). §3c covers how a
recalled sequence runs: nested recall and the cycle guard. §3d covers where sequences are
stored: a file of their own, not NVS.

---

## 1. Why the obvious answers don't work

There were already two ways to ask a board about its sequences. Neither is usable by a
remote consumer.

### `?SEQ,LIST` is not a wire format

`listStoredCommands()` (`WCB_Storage.cpp:712`) is a series of `Serial.printf` calls:

```
--- Stored Commands ---
Key: 'wave' -> Value: ';M1,1^;S5,<CA1021>^***wave and chirp'
--- End of Stored Commands ---
```

There is **no `?SEQ,LIST` packet and no mesh reply** — the full packet-type list is at
`WCB.ino:215-243` and nothing there carries sequence data. Three further traps if anyone is
tempted to scrape it anyway:

- The empty case prints `No stored commands.` with **no header or footer**
  (`WCB_Storage.cpp:717`), so a state machine keyed on the header never terminates.
- Values are `%s`-printed inside single quotes with **no escaping**.
- Output reaches **UART0 only** — `WCBSerial::write` (`WCB_RemoteTerm.cpp:49`) writes to
  `HardwareSerial` plus the optional RTERM mirror, never S1–S5. And over RTERM the line
  buffer flushes at 160 bytes *or* newline, whichever comes first
  (`WCB_RemoteTerm.cpp:68`, `RTERM_TEXT_SIZE` at `WCB_RemoteTerm.h:52`), with no
  continuation marker — so a long sequence value arrives torn into what look like separate
  lines. That failure only shows up on the sequences that matter.

### The config pull carries values, and overflows

`?MGMT,PULL,<n>` does return machine-readable text, and it *does* include sequences as
`?SEQ,SAVE,<key>,<value>` tokens (`collectConfigCommands`, `WCB.ino:3645`). But it carries every
sequence **value** plus the entire board config, and one reply caps at
`MGMT_MAX_CHUNKS` × 182 = **2912 characters** (`WCB.ino:1038`).

A board with ~20 real sequences exceeds that. A pull that asks for parts
(`?MGMT,PULL,<n>,P`, which the Wizard sends) then gets the config in parts of 2880 characters,
joined and CRC-checked by the requester ([MGMT_RELAY.md](MGMT_RELAY.md)). A plain pull gets a
`[MGMT:CFGERR,<n>]NOPARTS` line, and any pull through a relay or from a target that predates
parts still gets **nothing at all**, indistinguishable from a timeout. Either way the whole
config crosses the mesh just to read a list of names; that cost, and the silence on older
boards, are what this feature routes around.

---

## 2. The design: advertise a hash, pull the names

Two halves.

**A 4-byte fingerprint rides the WDP advert.** `WDP_TLV_SEQHASH` (`0x13`) is FNV-1a over
the board's key list (`k1,k2,...,` in save order) **and every stored value**. It changes
whenever a sequence is saved, edited, renamed or erased. Six bytes on the wire, which the
advert can afford.

It covers values, not just names, because editing a sequence in place never touches the
key list — a keys-only hash would leave every peer holding a stale copy while believing
it current, which is the exact failure the fingerprint exists to prevent. It is cached in
RAM and invalidated at each write path: the WDP dirty-check rebuilds the advert twice a
second, and hashing values uncached would mean a walk of the whole store at 2 Hz forever. A
store that cannot be read at that moment (§3d: it will not mount on a low heap) keeps the last
fingerprint and is tried again every 5 s; a value it could not read is never hashed as empty.

**The names are pulled on demand** with a dedicated request/response pair, only when the
hash a consumer sees differs from the hash it cached.

A steady mesh therefore costs **zero** request traffic, and a sequence saved on any board
shows up within a couple of seconds — WDP re-advertises on content change within ~500 ms
(`WCB_WDP.cpp:352`), it does not wait for the 60 s backstop.

### Why names are not simply advertised

The WDP payload is a fixed 200 bytes (`WCB_WDP.cpp:303`) and is already oversubscribed:
alias 26 + fwver 24 + hwver/capflags/ctrlid/flags 13 + maestro & wled cfg 40 + pwmtarget 22
+ five port labels 135 + magic/version/end 4 = **263 bytes worst case**. That is why port
labels are built last and documented as dropped gracefully on overflow
(`WCB_WDP.cpp:276`).

Sequence keys are capped at 15 chars (the **NVS key limit**, which the store keeps), so ~20 names is ~320 bytes —
more than the entire payload. Advertising them would silently evict the port labels, which
drive Maestro/WLED auto-config. `SEQHASH` is placed **before** PORTLABEL in the build order
for the same reason PWMTARGET is: it is functional, labels are cosmetic.

---

## 3. Wire format

### Request — `PACKET_TYPE_SEQ_REQ` (13)

Reuses `espnow_struct_config_req`, 43 bytes (`WCB.ino:783`). Broadcast, not unicast, so it
works before the target is a registered peer.

```
char    structPassword[40]
uint8_t packetType       = 13
uint8_t targetWCB        // board being asked
uint8_t requesterWCB     // only this requester is answered
```

Sent **three times** — a first broadcast frame to a given board is routinely dropped on a
busy mesh. The target dedups repeats from the same requester inside 1.5 s
(`handleSeqReqPacket`), so three sends still produce exactly one response.

The request reads the sequence store, so it is **deferred out of the WiFi callback** onto the
loop task via `enqueueMgmtReq` / `drainMgmtReqs`, exactly like CONFIG/STATS/ETM. Running it
inline stalls ESP-NOW and drops other inbound packets. A store it cannot read right then (§3d)
gets **no answer**, not an empty inventory: a `WCB_Client` reads any reply as the inventory. The
handler clears its dedup so the requester's retry is answered.

### Response — `PACKET_TYPE_SEQ_FRAG` (14)

Reuses `espnow_struct_config_frag`, 230 bytes (`WCB.ino:792`), through the shared
`sendResultFrags()` helper (`WCB.ino:3050`). **182 usable payload bytes per chunk** — the
183rd is reserved as a NUL terminator. (`WCB.ino:2950` records why: an earlier version used
all 183 and dropped one character per chunk, which ate the comma in `SEQ,SAVE,key,value`.)

> **Dispatch is by SIZE first, then packetType.** `CONFIG_REQ` and `MGMT_FRAG_UNICAST` are
> both type 5 and are told apart only by 43 vs 226 bytes (`WCB.ino:3316`). Any
> reimplementation of these structs must match the byte count exactly or the packet routes
> into the wrong handler — or nowhere, with no diagnostic at either end. `WCB_Client` pins
> both with `static_assert`.

### Payload

```
<hash8hex>,<count>[,<key1>,<key2>,...]
```

Comma separation is safe: `saveStoredCommandsToPreferences()` takes a stored key as
everything **before the first comma**, so a key can never contain one.

The empty case is `811C9DC5,0` — the FNV basis and a zero count — so a parser needs no
special case for "board has no sequences".

Sizing: 80 keys (`MAX_STORED_COMMANDS`) × 16 bytes ≈ 1280 bytes → 8 of the 16 available
chunks. Comfortable, unlike the config pull.

---

## 3a. Fetching ONE sequence

### Request — `PACKET_TYPE_SEQVAL_REQ` (15)

`espnow_struct_seqval_req`, **59 bytes** — its own struct because it must carry the
key, and the 43-byte request has no room.

```
char    structPassword[40]
uint8_t packetType       = 15
uint8_t targetWCB
uint8_t requesterWCB
char    key[16]          // NUL-terminated, ≤15 chars (the NVS key limit)
```

> It cannot instead be an ordinary `?SEQ,GET,<key>` command. A command arriving over
> ESP-NOW does not carry its sender into the firmware's handler — `sourceID` is a
> **serial port** (0 = USB, 1–5) and the ESP-NOW origin is only the
> `lastReceivedViaESPNOW` bool — so the target would not know who to answer.

59 is deliberately distinct from every other packet size (43/55/226/230/243/249/252)
because the receive path routes by size; a `static_assert` pins it on both sides.

Deduped target-side on **(requester, key)** within 1.5 s, not on requester alone —
otherwise a consumer walking a name list back to back would have its second request
mistaken for a retry of the first.

### Response — `PACKET_TYPE_SEQVAL_FRAG` (16)

Same 230-byte frag struct, through the same `sendResultFrags()`. Payload:

```
<key>,<status>,<value>
```

`status` is `OK`, `NOTFOUND`, or `TOOBIG`. The value may itself contain commas, so a
parser takes everything after the **second** comma verbatim. A store the target cannot read
right then (§3d) gets no answer at all, and the requester retries: `WCB_Client` reads any
status it does not know as `NOTFOUND`, which would be wrong.

**The reply is sent once and nothing acknowledges it.** Every chunk is one ESP-NOW
broadcast, 20 ms apart, with no second pass (unlike the config pull, which sends two).
Lose one chunk and the requester gets nothing: no partial value, no error. Its
half-built session is cleared silently after 10 s. So a requester must retry on
timeout, at least 1.5 s after its last request for the same key, or the dedup above
eats the retry. On the HIL bench, about 1 in 4 replies of 5-7 chunks was lost on the
first try.

**`TOOBIG` is reported explicitly.** `sendResultFrags()` silently refuses anything
over 16 chunks, so the handler checks the budget first and answers with a status
instead of nothing. Silence is what makes a config pull through older firmware unusable here (§1) and
reintroducing it in the replacement would recreate the very bug this routes around.
The budget allows a 2,903-character value, and the store takes up to 3,999 (§3d), so a
long enough sequence answers `TOOBIG`. What usually stops a long value first is the heap a
save costs (§3b): on a classic ESP32 about 2,400 characters. HIL `inv.seqget_largest` finds the
largest value a board actually stores and round-trips it.

### Why one at a time

A single value is bounded — ~1800 chars is about 10 of the 16 chunks. The whole set
is not. A consumer pulls the name list, then walks it:

```
requestSequenceNames(3)  →  "wave,park,scream"
  requestSequence(3, "wave")
  requestSequence(3, "park")
  …
```

No aggregate ceiling, fetch lazily (only the sequence someone actually opened), and
a board that drops mid-walk just resumes. At ~100 ms per round trip, mirroring a
20-sequence board takes 2–3 seconds.

There is deliberately **no** "give me everything" packet. That would need a real bulk
sender, which neither the firmware nor `WCB_Client` has — the library's bulk facility
is receive-only (it parses inbound `bb`/`bc`/`bd` and NACKs; there is no `sendBulk()`).

---

## 3b. Writing sequences

**No new wire format.** A write is an ordinary command — `?SEQ,SAVE,<key>,<value>` or
`?SEQ,CLEAR,<key>` — because everything needed already exists:

- `WCB_Client::send()` fragments anything over one packet (up to
  `WCB_MGMT_MAX_COMMAND_LEN`, 16 × 179 = 2864 chars).
- The firmware's parser has a dedicated `?SEQ,SAVE` branch that does **not** split on
  the `^` delimiters inside a sequence value — it treats only delimiter+funcChar
  (`^?`) as the boundary, because `^;` belongs to the value (`WCB.ino:2015-2048`).
- MGMT reassembly of a client-sent command keeps **unicast** semantics on 6.1.1+
  firmware, so a save lands on that board instead of fanning out.

A second, bespoke write path would drift from the one the Wizard and the console
already use. Don't add one.

**A long save costs about 7× its length in heap while it runs.** The line is copied at
almost every layer of the dispatcher before `saveStoredCommandsToPreferences()` takes its
own copy: the port's line buffer, the queue item, `args`, its upper-cased twin and the SEQ
arguments. A classic-ESP32 board has about 24 KB of byte-addressable heap after boot, so
a value of about 2,400 characters or more either fails with "Out of memory: could not copy"
or reaches the store with little heap left.
`?STATS`'s "min free since boot" is the sum of each heap region's own low point, not one
moment's free heap. After such a save it can read near 0 until the next reboot, without the
board ever having been out of memory (tracker #75).

**Key rules** (enforced client-side so a bad write fails loudly instead of silently):
1–15 chars (the NVS key limit, which the store keeps so a sequence can move between the two),
and **no comma** — `saveStoredCommandsToPreferences()`
takes the key as everything before the first comma, so a comma would truncate it on
save and then never match on read. The firmware refuses a longer key on **every** path, not
only on save (`SEQ_KEY_MAX_LEN`, `WCB_Storage.h`): NVS compares only the first 15 characters of
a lookup, so `?SEQ,GET`, `;C` recall, the `SEQGET` relay and `?SEQ,CLEAR` would otherwise read,
run or erase the sequence stored under the 15-character prefix. A longer key is reported as not
found and never reaches the store; on the NVS fallback, erasing by such a name still drops it
from `key_list`, where firmware before d83042e could list a key it had failed to store. The MP3 and DFPlayer
`ONERR` callback key is held to the same 15 characters.

**Two names are reserved.** `key_list` and `seq_mig_done` are the NVS layout's own records, kept
in the `stored_cmds` namespace beside the sequences it holds (§3d: the fallback, and every
firmware before the store). `?SEQ,SAVE`, `?SEQ,CLEAR`, `?SEQ,GET` and a `;C` / `;SEQ` recall
refuse both (`seqKeyReserved`, `WCB_Storage.h`), a recall before its mesh fan-out; `GET` answers
`NOTFOUND`. In that layout a save by either name corrupted the list or the migration flag, a clear
unlisted every sequence or re-armed the legacy migration, and a recall ran the name list as
broadcast text. `?NVS` shows what `stored_cmds` holds (HIL `seq.get_internal_keys`,
`seq.reserved_bookkeeping_keys`).

**A stored value ends only at delimiter + function identifier.** `?SEQ,SAVE`, `?CS` and `?MGMT,`
carry values that may themselves contain the command delimiter and a `;t` token, so only the
splitter that knows that boundary (`parseCommandsNoChecksum`) may walk such a chain. The timer
splitter (`parseCommandGroups`) does not: it cuts on the bare delimiter and reads any `;t` as an
inter-group delay, which truncated the stored value and ran its tail as live commands. Chains
carrying one of those verbs are kept off the timer path by `chainCarriesValueVerb()` (`WCB.ino`) at
every routing gate: `isTimerChain()` for the console and WebSocket reader, both ESP-NOW receive
paths and the reassembly of a multi-chunk `?MGMT,FRAG` or fragmented client unicast, and the
recall's own test in `recallCommandSlot()`. The cost is deliberate: a chain mixing a real `;t`
timer with a `?SEQ,SAVE` loses its inter-group timing, traded against a truncated stored value.
`isTimerChain()` also sends a chain that starts with the function identifier to the timer engine,
but only when a token is a real `<cmdChar>T<digits>` and no token is a checksum (a verified chain
goes through the checksum gate, which the timer path skips). Such a chain used to be refused
outright, so `?VERSION^;S1a^;T800^;S1b` ran both writes together and printed `Invalid Serial
Command` for the `;T`. A received chain longer than a timer-queue slot (219 characters) rides a
heap buffer to `loop()`; one the heap or the full queue cannot take is reported there
(`[TIMER] ... not run`), never cut.

### Confirming a write

There is no per-save reply packet. Confirm either by reading the value back with a
`SEQVAL_REQ`, or — cheaper — by watching the target's `seqHash`: the board
re-advertises within ~500 ms of any write, and **the hash covers values**, so an
in-place edit moves it just as a new key does.

That last point is why the hash is content-aware. A keys-only fingerprint would not
change when a sequence was edited, and every other consumer on the mesh would keep
serving a stale copy while believing it current.

---

### `0` vs `0x811C9DC5`

| `seqHash` reads | Means |
|---|---|
| `0` | The board advertised **no** SEQHASH — firmware predates the TLV. Unknown, not empty. |
| `0x811C9DC5` | The board has **zero** stored sequences (FNV-1a of an empty string). |

Conflating these makes an old board look like an empty one. `?WDP,DUMP` omits the
`[WDPSEQ:...]` record entirely rather than emitting `HASH=00000000`, preserving the
distinction.

The hash is **order-sensitive** (the key list keeps save order). That is intended: it
answers "did *my* inventory change", not "do two boards match".

---

## 3d. Where sequences are stored

**In a file of their own, not NVS** (`WCB_SeqStore.{h,cpp}`). The sequences are the lines of
`/seqs` - `<key>,<value>`, one per line, in save order - in a LittleFS on the 128 KB `spiffs`
data partition that the min_spiffs table carries and nothing else on a WCB uses. NVS keeps
one entry for them, the `stored_cmds/seq_mig_done` marker.

| Limit | Value | Why |
|---|---|---|
| Key | 1-15 characters, no comma | The NVS key limit, kept so a sequence can move between the two stores |
| Value | 1-3,999 characters, no line break | What NVS held (4,000 with the NUL); the file is one sequence per line |
| Store | 32,768 bytes of lines (`SEQ_FILE_MAX`) | A config pull carries at most 16 parts of 2,880 bytes (46 KB, `WCB_ConfigParts.h`), every sequence riding it as a `?SEQ,SAVE` token beside the other settings: at 32 KB a full store still pulls. It is also under half the partition, which a replace needs (below) |

`?NVS` ends with one line on it: `Sequences: <n> in the sequence store, <bytes> of 32768 bytes
(partition spiffs: <used> of <total> bytes used)`.

**Writes.** A new key appends one line. LittleFS commits a write only when the file is
closed, and not at all once a write to it failed, so a reset mid-append leaves the file as it
was. Replacing or removing a sequence writes the whole file to `/seqs.tmp` and renames it over
`/seqs`: a reset leaves the old store or the new one, never half of each. That copy needs room
for a second file, so a full store can still remove a sequence. A re-save of the value already
stored writes nothing, so a re-pushed config costs reads only. A replace keeps the key's place;
a clear and re-save moves it last - the same order rules the NVS key list had, so the hash is
byte-identical across the move from NVS.

**Mounted for each call, never between calls.** A mount holds 1.7 KB of heap (measured on
the bench's classic boards, access point up) and each open file about 0.7 KB more, a tenth of
what such a board has free (CLAUDE.md rule 14). Each call mounts (about 12 ms) and unmounts as
it returns. Held for 3 s after a call instead, a `?backup` left it mounted under a 250-token
one-line restore, which lost four tokens to `Out of memory while enqueuing command!` (HIL
`backup.one_line_restore`). Below 6 KB of free heap it refuses to mount, and the caller says
so: a save prints `Failed to store sequence '<key>' (out of memory)`, a recall `Could not read
sequence`, a mesh request goes unanswered until its retry. Every call is from the loop task;
never from the ESP-NOW receive callback.

**Reads.** A recall, `?SEQ,GET`, `?SEQ,LIST`, `?config`, the config walk (`?backup`, the config
pull) and the hash are each a walk of the file, with no copy of it in RAM: a value is held only
while it is used, and the hash reads none. A value the heap cannot hold is a lost token to the
config walk (F19): `?backup` warns, a pull answers `NOMEM`. A line no key can address (no
comma, or a key over 15 characters) is skipped, and the next replace or remove drops it.

**The settings store still decides when sequences are erased.** `?ERASE,NVS` and
`?SEQ,CLEAR,ALL` clear the file too. A factory reset that blanks only NVS - the Wizard's writes
0xFF over the NVS partition and leaves `spiffs` alone - takes the `seq_mig_done` marker with it,
and a boot that finds the file without the marker clears it: `[SEQ] The settings store was
erased since these sequences were saved (a factory reset): cleared them too.` The marker is
written at every boot that lacks it (`migrateOldStoredCommands`), so only a wipe removes it.

**The NVS fallback.** A boot that cannot mount the partition runs the store on the old NVS
layout (`key_list` plus one string per key) for that boot, and says why:
`[SEQ] Stored sequences are kept in the settings store this boot: <why>`. The reasons: no
`spiffs` partition (a build with another partition scheme), the last boot crashed while mounting
it, or `?DEBUG,SEQNVS` asked for it (a test knob, RTC memory, one boot). The crash check exists
because the core builds LittleFS with its asserts on: a damaged file system can `abort()` inside
the mount, and every later boot would mount it and crash the same way. An RTC word holds a
marker while a mount runs; a boot after a panic or a watchdog reset that still finds it skips
the mount. `?SEQ,CLEAR,ALL` on a fallback boot formats the file store, which is how a damaged
one is started over.

**Moving NVS sequences in.** Every boot that mounts moves whatever NVS still lists into the
file, in one rewrite, then reads each back before removing it from NVS: `[SEQ] Moved <n>
sequence(s) from the settings store into the sequence store.` That is how the first boot of this
firmware on a board moves every sequence it has, and how a fallback boot's saves come back. NVS
wins a key both hold, in the file's place: NVS only holds a sequence while the file exists when
a fallback boot or an older firmware saved it, which is newer. A listed name with no value is
dropped from the list; a value the file cannot take (a line break, or no room) stays in NVS,
unused, and the boot says so. A reset anywhere in the move loses nothing: the next boot moves
again.

**Going back to firmware before the store** shows no sequences: they are in the file, which
older firmware does not read. Restore them from a backup there. Coming forward again, the file
is still there, and what the older firmware saved in NVS moves in beside it.

## 3c. Running sequences: nested recall and the cycle guard

**A nested `;C` is enqueued, not run on the C++ stack.** `recallCommandSlot()` expands a body
into the command queue and returns, so a recall inside a body runs when its queue item is
dispatched, and the body it expands drains *behind* whatever was already queued. A body's
own commands therefore run before the bodies it calls: `;CBEEP^;S1x` prints `x` first.

**Each queued command carries its lineage**: the keys whose expansion produced it, outermost
first. `CommandQueueItem::seqDepth` counts them, and the entries themselves are FNV-1a 32
hashes of the exact key bytes (`seqKeyHash()`), stored in front of the command text in the
same allocation. The `loop()` drain restores an item's lineage into `seqCurPath` before
dispatching it. `recallStoredCommand()` then:

- refuses a key already on that lineage: `Sequence '<key>' recalls itself (directly or in a loop) — refusing to expand it again. Break the cycle in the stored sequence.`
- refuses at depth 8 (`SEQ_MAX_NESTING`): `Sequence nesting deeper than 8 — refusing to expand '<key>'.`

`recallCommandSlot()` pushes the key while it enqueues the body. A body containing `;t` goes
to the timer splitter, which captures the lineage in `commandGroupsPath` and re-applies it as
each group fires, so the lineage survives the delay.

As a result, `A→A`, `A→B→A` and a `;t`-paced self-recall (`;S1x^;t200^;CSELF`) are refused,
while the same sub-sequence can be called any number of times, at any depth. The key compare is
case-sensitive like the NVS lookup, and a hash collision can only over-refuse, never miss a cycle.
Every endless expansion either repeats a key on some lineage or passes depth 8, so the
guard also stops the queue refilling forever.

A top-level recall, a recall received over the mesh, and an MP3/DFPlayer `ONFIN`/`ONERR` body
each start a fresh lineage. A ring that crosses boards (`;W2,;C…` on both sides) is invisible
to any one board's guard.

**A nested expansion must fit, whole.** Back-to-back calls with no `;t` between them expand
every call before any leaf runs, because the queue is FIFO. `recallCommandSlot()` therefore
refuses a *nested* expansion (lineage depth > 0, no `;t` in the body) when its token count plus
`SEQ_QUEUE_RESERVE` (16) exceeds the free slots of the 200-slot queue. It prints one line,
`Command queue nearly full — not expanding nested sequence '<key>'. Space repeated calls with ;T.`,
and enqueues nothing. Without that check a full queue printed `Command queue is full!
Discarding command.` once per dropped token on UART0, which has no TX buffer. That stalled
`loop()`, dropped console commands and cut bodies short. A top-level recall (`;C`, `ONFIN`,
`ONERR`) must fit too, with no reserve: one whose token count exceeds the free slots is refused
whole, with one line (`Sequence '<key>' has <n> commands and the command queue has room for
<m> — not run.`), where it used to run its first part and drop the rest one line per token. A
body over 200 commands can therefore never run as one recall; split it with `;T`, whose groups
enqueue one at a time and are not checked. The serial reader, a task of its own, waits up to
2 s per command for queue room instead, so a pasted `?backup` of more than 200 tokens runs
whole; the loop task, which drains the queue, and the WiFi task never wait.

**Only one timer chain runs per board.** A called sequence that contains `;t` replaces the chain
that is running (`parseCommandGroups()`, "Timer sequence replaced mid-run"), so the caller's
remaining timed steps are dropped. Reused sub-sequences should not contain `;t`; the caller
should hold the delays.

Constraints:

- `seqCurPath` is **loop-task only**. `enqueueCommand()` stamps a lineage only when
  `seqOnLoopTask()` is true, and `seqLoopTask` is captured first thing in `setup()`. A command
  enqueued by `serialCommandTask` or the WiFi callback is top-level by construction. Off the
  loop task, `parseCommandGroups()` writes only `commandGroupsPath.depth` (0), so a concurrent
  copy on the loop task is always a consistent path. Moving the drain, the recall or timer firing
  off the loop task would empty every lineage, and `A→A` would run away again.
- Anything that dequeues `commandQueue` frees `commandItemBlock(item.cmd, item.seqDepth)`,
  **never** `item.cmd`, which points past the lineage.
  `grep -n "free(.*\.cmd)" Code/WCB/WCB.ino` must find nothing.
- Never go back to a global key set, and never pop one "when an expansion drains". In
  `;CBEEP^;CBEEP` the second call is dispatched while the first BEEP's body is still queued
  behind it, so it would still be refused. The stack has to belong to each queued item.

HIL: `seq.cycle_guard` (refusals and the depth limit), `seq.cycle_guard_case`,
`seq.cycle_guard_reuse` (reuse at every shape, plus a `;t`-paced self-recall), and
`seq.reuse_queue_reserve` (the nested-expansion reserve).

---

## 4. Using it

### From a WCB console

```
?SEQ,NAMES            # this board — one parseable line
?SEQ,GET,wave         # this board — one sequence
?MGMT,SEQ,3           # WCB3's names, over the mesh
?MGMT,SEQGET,3,wave   # WCB3's 'wave' sequence
?SEQ,SAVE,wave,…      # write (already existed)
?SEQ,CLEAR,wave       # delete (already existed)
```

Both produce the same shape, so a host parsing a board's console uses one parser for local
and remote:

```
[MGMT:SEQ,3]A1B2C3D4,3,wave,park,scream
[MGMT:SEQVAL,3]wave,OK,;M1,1^;S5,<CA1021>^***wave and chirp
```

`?WDP,DETAIL,<n>` shows a neighbor's hash, and `?WDP,DUMP` emits it as its own record —
`[WDPSEQ:N=3,HASH=A1B2C3D4]` — deliberately **not** as a new field on the `[WDP:...]` line,
whose field order is load-bearing for older Wizard regexes.
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

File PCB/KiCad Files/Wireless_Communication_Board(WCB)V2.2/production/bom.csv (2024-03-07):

Designator | Footprint | Quantity | Value | LCSC Part #
C1 | 805 | 1 | 10uF | C1222438
C12 | 402 | 1 | .1uF | C307331
C2 | 402 | 1 | .1uF | C307331
C3 | 402 | 1 | .1uF | C307331
C4 | 805 | 1 | 4.7uF | C126590
C5 | 402 | 1 | .1uF | C307331
C6 | 603 | 1 | 1uF | C913562
C7 | 603 | 1 | 1uF | C913562
C8 | 805 | 1 | 10uF | C1222438
C9 | 402 | 1 | .1uF | C307331
D1 | SOD3716X135N | 1 | B5819W-TP | C84354
D2 | SOT-143 | 1 | SP0503BAHTG | C7074
J1 | USB_Micro-B_Amphenol_10118194_Horizontal | 1 | USB_B_Micro | C132563
J2 | TerminalBlock_bornier-2_P5.08mm | 1 | Power In | C3011914
J3, J4, J5, J6, J7 | PinHeader_1x04_P2.54mm_Vertical | 5 | Conn_01x04 | C2691448
L2 | WS2812B-2020 | 1 | WS2812B-2020 | C965555
Q2 | SOT65P230X110-6N | 1 | UMH3N | C123008
R1 | 402 | 1 | 10K | C60489
R10 | 402 | 1 | 402 | C41042
R16 | 402 | 1 | 470 | C852799
R2 | 402 | 1 | 1K | C105637
R3 | 402 | 1 | 1K | C105637
R4 | 402 | 1 | 22.1K | C137898
R5 | 402 | 1 | 47.5K | C319605
R6 | 402 | 1 | 1K | C105637
R7 | 402 | 1 | 10K | C414854
R9 | 402 | 1 | 402 | C41042
S1 | SW_TL3342F160QG | 1 | TL3342F160QG | C492949
U1 | MODULE_ESP32-PICO-MINI-02 | 1 | ESP32-PICO-MINI-02 | C2980306
U2 | QFN-28-1EP_5x5mm_P0.5mm_EP3.35x3.35mm | 1 | CP2102N-A02-GQFN28 | C964632
U3 | WSON-6-1EP_2x2mm_P0.65mm_EP1x1.6mm_ThermalVias | 1 | LP5912-3.3DRV | C2876187
U4 | TSSOP-8_4.4x3mm_P0.65mm | 1 | TPS2115APW | C70287

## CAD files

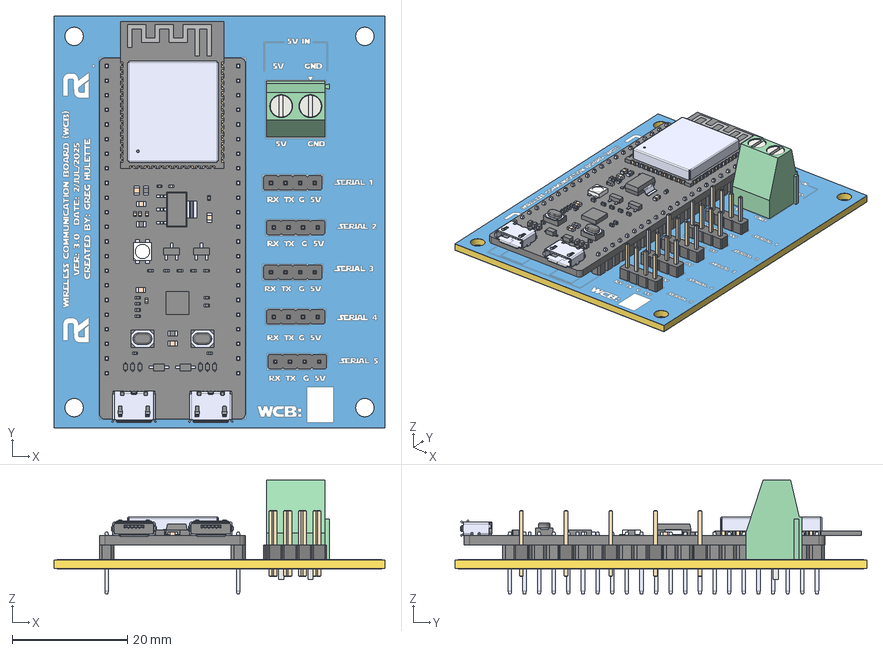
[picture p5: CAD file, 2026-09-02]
PCB/Wireless Communication Board (WCB)V3.2/Wireless3.2.step
57.5 x 71.5 x 19.8 mm
PinHeader_1x04_P2.54mm_Vertical x 5
TerminalBlock_Phoenix_MKDS-1,5-2-5.08_1x02_P5.08mm_Horizontal
ESP32-S3-DEVKITC-1-N8R2--3DModel-STEP-56544
Wireless3.0_copper
Wireless3.0_pad
Wireless3.0_silkscreen
Wireless3.0_soldermask
Wireless3.0_PCB

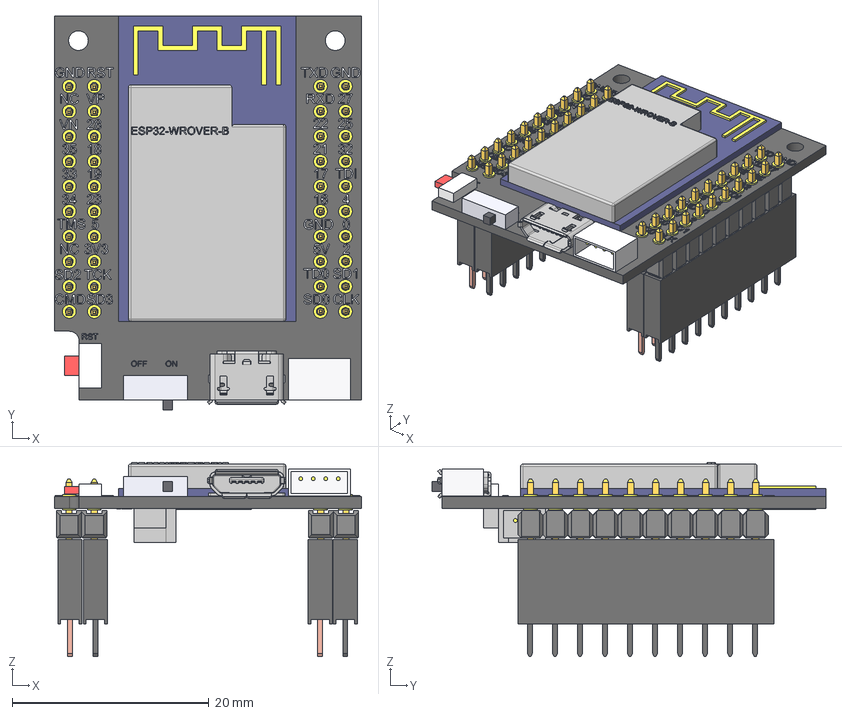
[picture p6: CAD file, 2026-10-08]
PCB/Wireless_Communication_Board(WCB)V1.0/ESP32 With Headers.step
31.2 x 40.0 x 19.7 mm
micro usb02
micro usb
Header Female 1x10 v1
Header Female 1x10 v1 (1)
Header Female 1x10 v1 (2)
Header Female 1x10 v1 (3)
Pin Header 1x10 TH Pitch 2.54mm v1
Pin Header 1x10 TH Pitch 2.54mm v1 (1)
Pin Header 1x10 TH Pitch 2.54mm v1 (2)
Pin Header 1x10 TH Pitch 2.54mm v1 (3)

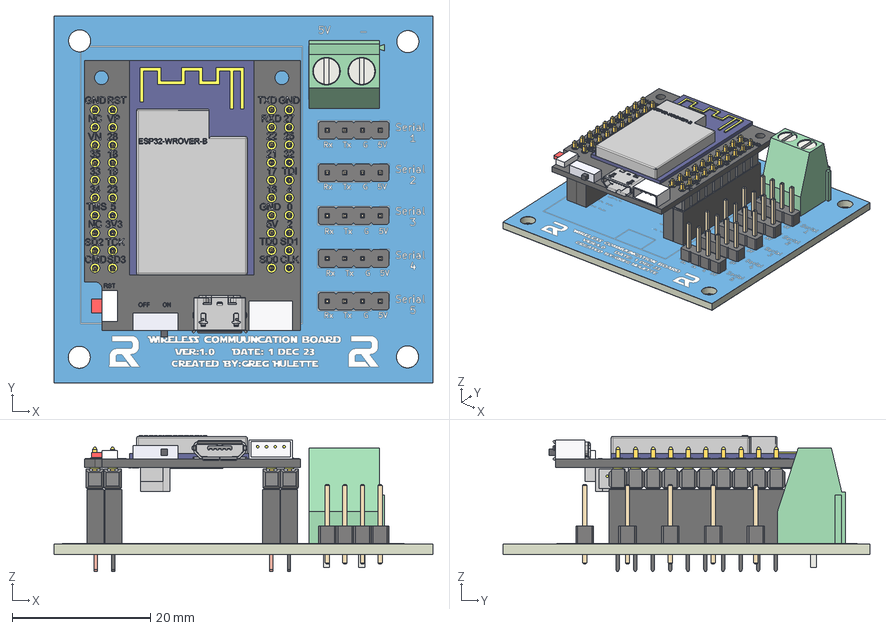
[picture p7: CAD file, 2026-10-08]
PCB/Wireless_Communication_Board(WCB)V1.0/WCB_V1.0.step
54.8 x 53.0 x 19.7 mm
PinHeader_1x04_P254mm_Vertical x 5
micro usb02
micro usb
Header Female 1x10 v1
Header Female 1x10 v1 (1)
Header Female 1x10 v1 (2)
Header Female 1x10 v1 (3)
TerminalBlock_Phoenix_MKDS-1,5-2-5.08_1x02_P5.08mm_Horizontal
Wir6368_copper
Wir6368_pad
Wir6368_silkscreen
Wir6368_soldermask x 2
Wir6368_PCB

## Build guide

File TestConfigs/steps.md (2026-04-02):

open webpage
click wizard
choose 3
v.1/2.4/3.1
yes kyber
change maestro to serial 1, change marcduino to serial 2.  Verify if you change the maestro port, that interface is not available for marduino
yes maestro
add 2 and 3 and set 2 to w2s2@115200 and 3 to w3s1@57600
Serial ports, add labels
click generate random cube to change
change delimeter to *
change function char to .
change command char '

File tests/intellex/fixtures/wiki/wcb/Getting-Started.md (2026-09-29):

# Getting Started

A second crafted page. Back to [[Home]].

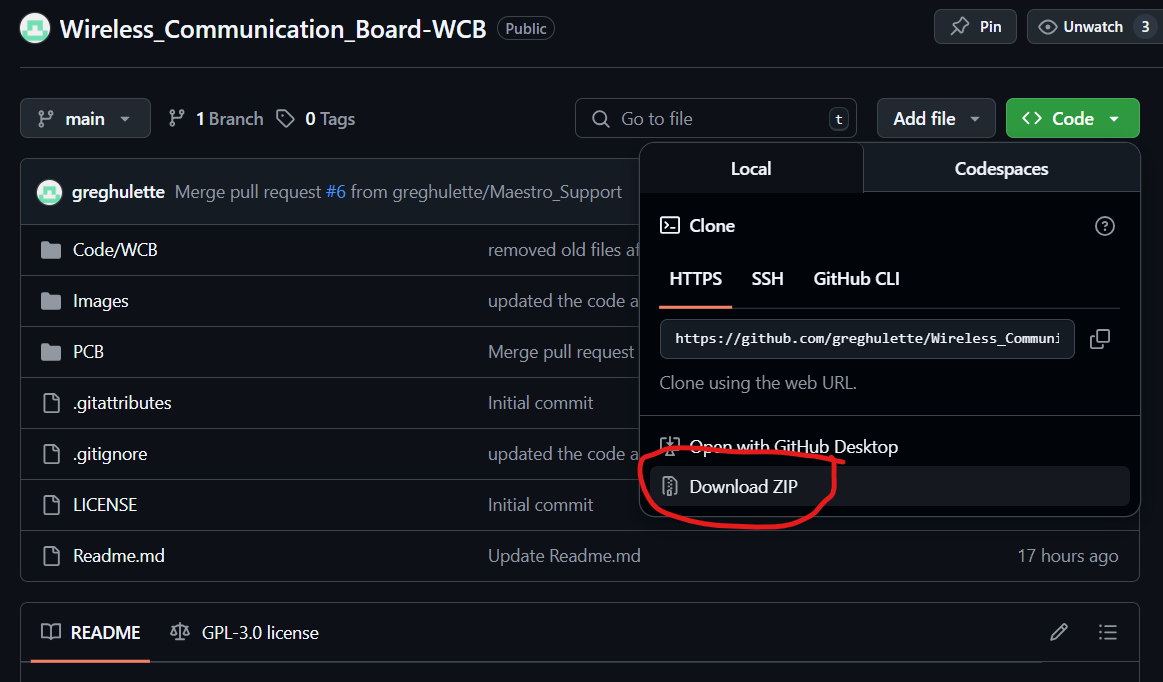
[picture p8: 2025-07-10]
Images/3.1_Instructions/download.png

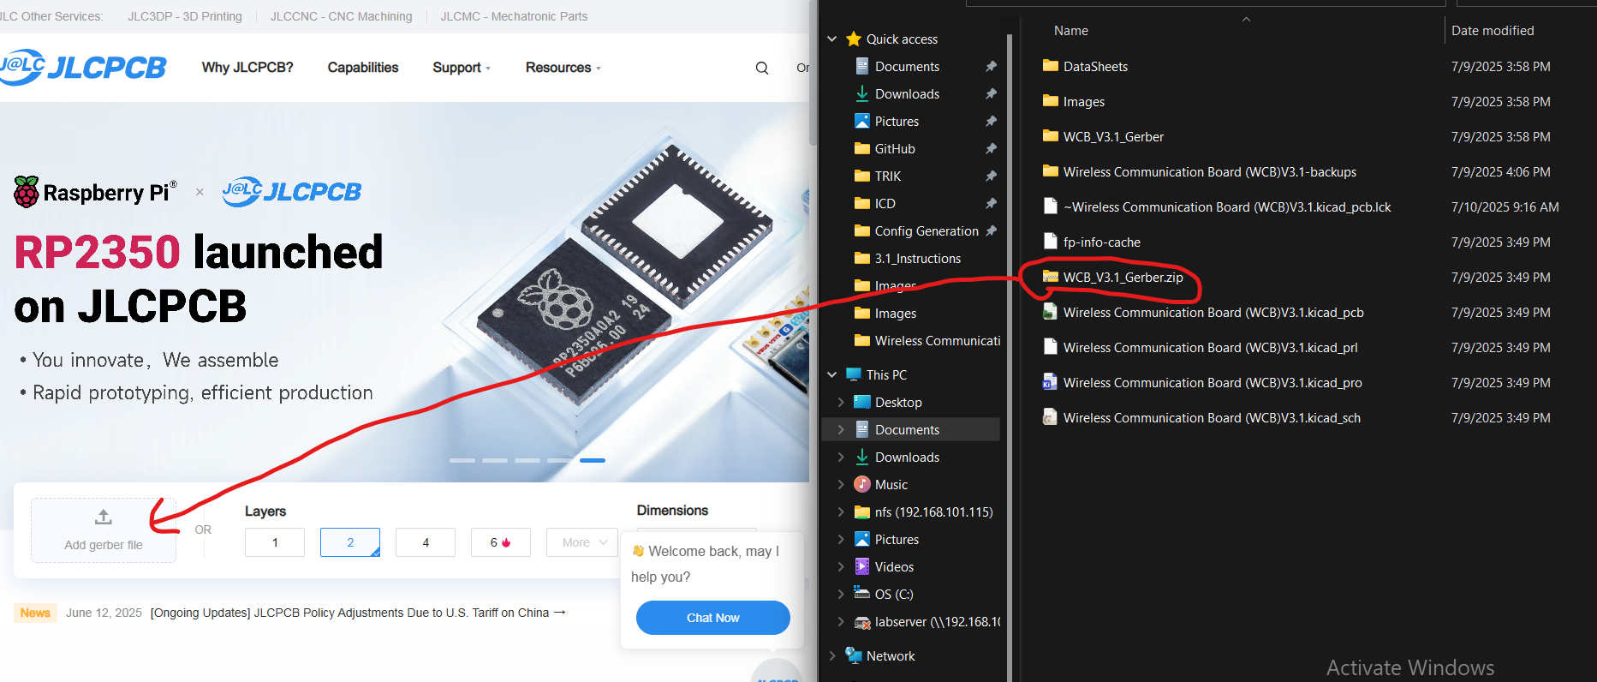
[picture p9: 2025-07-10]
Images/3.1_Instructions/jlc_drag.png

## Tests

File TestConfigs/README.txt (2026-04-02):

WCB TEST CONFIGURATION FILES
=============================

OVERVIEW
--------
Each file contains a pre-built configuration string for a specific board and
test scenario. Paste the PASTE line directly into the board's terminal in the
wizard. Commands are chained with ^ (the default delimiter) and execute in
sequence. The string ends with ?config to print the final state for verification.

These are SETUP SCRIPTS, not ?backup restore strings. They do not contain a
CRC checksum. After loading a config and verifying it looks correct, run
?backup on each board to capture the validated restore string for that state.

FILES
-----
Config 01 — Base Identity + Network
  WCB1_01_base.txt    Phases 2, 3, 3B, 4, 10, 12, 13
  WCB2_01_base.txt    Phases 2, 3, 3B, 4, 10, 12, 13
  WCB3_01_base.txt    Phases 2, 3, 3B, 4, 10, 12, 13

  What it sets up:
    - Hardware version, WCB number, WCB quantity
    - MAC octets, ESP-NOW password
    - ETM ON with standard parameters (HB=10s, MISS=3, TIMEOUT=500ms, CHKSM=ON)
    - Baud rates matched to physically connected hardware
    - Port labels
    - Broadcast reset to all-on defaults
    - All device configs and mappings CLEARED (Kyber, MP3, Maestro, serial, PWM)

  Use for: ETM/broadcast/serial command testing where device configs would
  interfere, and for any test that needs a known clean starting state.

Config 02 — Full Feature Setup
  WCB1_02_full.txt    Phases 5, 6, 7, 8, 11, 14
  WCB2_02_full.txt    Phases 5, 9, 11, 14
  WCB3_02_full.txt    Phases 5, 8, 9, 11, 14

  What it sets up (everything in base PLUS):
    WCB1: Kyber LOCAL (S2+S3), MP3 Trigger (S5), raw serial mapping S5<->W3S2,
          Maestro routing for M1/M2/M3 (all remote — routes to WCB2/WCB3)
    WCB2: Maestro M1 LOCAL (S1), Maestro M2 LOCAL (S2), Maestro M3 REMOTE (W3S1),
          PWM mapping S3->S4 local + W3S5 remote
    WCB3: Maestro M3 LOCAL (S1), Maestro M1/M2 REMOTE (W2S1/W2S2),
          raw serial mapping S2<->W1S5, PWM output S5

  Use for: All device-level testing, backup/restore round-trip, edge cases.

HOW TO LOAD A CONFIG
---------------------
1. In the wizard, open the terminal for the board you want to configure
2. Open the appropriate .txt file in any text editor
3. Find the line that starts with "PASTE:"
4. Copy everything AFTER "PASTE: " (the entire command chain on that line)
5. Paste into the terminal and press Enter
6. Watch each command execute — errors will print inline
7. The final ?config output shows the complete resulting configuration

AFTER LOADING — CAPTURE THE BACKUP STRING
------------------------------------------
Once you have verified the config looks correct with ?config, run ?backup.
Copy the output string (including the ?CHK... checksum at the end) and save it
as a separate file. That ?backup string is the true validated restore string
that will be accepted by the firmware with CRC verification.

Suggested backup filename format:  WCB1_02_full_BACKUP_v6.0.txt

NETWORK SETTINGS
-----------------
The files use these values from the test system:
  MAC group 2  : D3
  MAC group 3  : 3B
  ESP-NOW pass : Jq6SECq8dsNRmq

If your system uses different values, edit the PASTE line in each file before
using it. Change ?MAC,2,D3 / ?MAC,3,3B / ?EPASS,Jq6SECq8dsNRmq accordingly.
All boards in a system must share the same MAC octets and password.

HARDWARE VERSIONS IN THESE FILES
----------------------------------
  WCB1 : v2.1  (HW=21)
  WCB2 : v2.4  (HW=24)
  WCB3 : v2.3  (HW=23)

If you swap hardware, update the ?HW,xx value in the PASTE line.

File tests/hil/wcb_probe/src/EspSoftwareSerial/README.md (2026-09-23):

> ## WCB vendored + patched copy — do not replace with stock upstream
>
> This is [EspSoftwareSerial](https://github.com/plerup/espsoftwareserial) **8.1.0** by Peter Lerup and
> Dirk O. Kaar, **vendored directly into the WCB sketch** and patched for the Wireless Communication Board.
> It lives at `Code/WCB/src/EspSoftwareSerial/` and is pulled in with a relative
> `#include "src/EspSoftwareSerial/SoftwareSerial.h"` (from `hcr.h`, `"../EspSoftwareSerial/SoftwareSerial.h"`),
> so **building the WCB firmware needs no EspSoftwareSerial install**, and a copy already installed in your IDE
> or sketchbook is ignored. No file under `Code/WCB` may include `SoftwareSerial.h` with angle brackets: that would compile the
> stock library alongside this one (the check is in `CLAUDE.md` rule 7).
>
> The WCB uses it for **receive only** on S3-S5. Transmit goes through an RMT channel (`WcbSoftSerial`,
> `Code/WCB/WCB_SoftSerial.{h,cpp}`); the library's bit-banged TX is only the fallback when no RMT channel is free.
>
> **WCB patches vs. upstream 8.1.0** (tracker #78, `docs/HIL_FIX_TRACKER.md`):
> - **Level-triggered receive on the classic ESP32** (`ESPSWSERIAL_LEVEL_RX`, set from `CONFIG_IDF_TARGET_ESP32`
>   in `SoftwareSerial.h`). ESP32 erratum GPIO-3.14 loses an **edge** interrupt on GPIO0-31 when the GPIO ISR's
>   STATUS / W1TC handling of another pin lands on it. The WCB measured it on its own S3-S5 pins: 227 of 10125
>   two- and three-port lines lost when the pins took edges ~1.5-3 µs apart, every single-port line exact
>   (HIL `softrx.erratum_pairs`, 2026-09-23). `enableRx()` now attaches `rxBitISR` as `ONLOW`/`ONHIGH` for the
>   level the line is *not* at, and `rxBitISR` re-arms the opposite level first (`gpio_ll_set_intr_type`, one
>   register write), then records a transition only when the level differs from the last one recorded, and
>   re-reads the pad and re-arms if the line moved while arming. What is left (a transition just before the IDF's
>   post-handler status clear, or the glitch-train cap exit) is caught because a level status re-asserts while its
>   condition holds. Espressif's documented workaround for the erratum.
> - **The ESP32-S3 is untouched:** `ESPSWSERIAL_LEVEL_RX` is 0 there, and `rxBitISR`, `enableRx()` and the class
>   layout compile exactly as upstream.
> - **`rxBitSyncISR` (above ~74880 baud, i.e. 115200) stays on its FALLING edge** on both chips. It busy-waits a
>   whole frame inside the ISR, so as a level interrupt a line held low would re-enter it forever.
> - **`rxLevelTriggered()`** added (public): true while RX runs on the level-emulated interrupt. The WCB prints it
>   at `?DEBUG` (`[SOFTSERIAL] S<n> RX: ...`).
> - **Include guard renamed** to `WCB_VENDORED_SOFTWARESERIAL_H`, with `__SoftwareSerial_h` left undefined and an
>   `#error` if it is already defined, so the stock header in the same build fails loudly instead of
>   linking two receivers.
> - **Copied:** `src/SoftwareSerial.{h,cpp}`, `src/circular_queue/{circular_queue.h, Delegate.h, ghostl.h}`
>   (`ghostl.h` is reached only on non-ESP builds; kept so every include resolves), `LICENSE`. **Not copied:** `examples/` (the
>   `circular_queue_mp_test` `.cpp` would be compiled by the sketch's `src/` build), `MultiDelegate.h`,
>   `circular_queue_mp.h` (unused).
>
> **Constraint the patch adds (CLAUDE.md rule 13):** `rxBitISR` rewrites the pin's `GPIO_PINn_REG` interrupt type
> from core 1's GPIO ISR without the IDF spinlock, so an S3-S5 RX pin is only ever (re)configured from core 1
> (`setup()`, `loop()`, `applyLiveBaud()`), never from a core-0 task.
>
> The probe firmware (`tests/hil/wcb_probe`) and the Arduino-Code sketchbook keep the **stock** library.
>
> Upstream license (GNU LGPL 2.1 or later) is preserved in `LICENSE`, and the copyright headers in the sources are
> unchanged; every modification is marked `WCB patch` in the source. To pull a newer upstream, re-apply the
> patches above rather than dropping a stock copy in place.

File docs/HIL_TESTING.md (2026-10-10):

# Hardware-in-the-loop tests (`tests/hil`)

A Python harness, with a GUI, that drives real boards over USB and checks what they actually do —
the bytes a WCB puts on a serial port, the frames a Maestro receives, what comes back over the
mesh. It complements the compiler and `tests/wdp_wire_test.cpp`; it does not replace them, and
no CI runs it, because it needs the physical bench.

The one dependency is `pyserial` (the GUI uses tkinter, which ships with Python). On this PC the
`python` on PATH (PyManager) has it. **VS Code may run the file with a different interpreter** — a
uv-managed Python without pyserial — and the GUI then shows a message saying so. Double-clicking
`tests/hil/WCB Bench.cmd` always uses the PATH Python.

```bash
tests/hil/WCB Bench.cmd                      # double-click: the GUI
python tests/hil/gui.py                      # the GUI: devices, wiring, tests, log
python tests/hil/gui.py --run "hcr.*" etm.char_loaded   # opens and starts those tests, so a scripted run can be watched
python tests/hil/run.py                      # every test, command line
python tests/hil/run.py "maestro.*" "wled.*" # ids matching globs
python tests/hil/run.py --no-servos          # everything except the tests that can move a real servo (§2 no_servos)
python tests/hil/run.py --discover           # re-detect the wires first
python tests/hil/run.py --list | --plan | --links   # --list: each test's wires, expected time and opt-in
python tests/hil/run.py --resume [<run>]     # continue a paused or interrupted run (Ctrl+C once pauses a run)
python tests/hil/run.py --paused             # list the runs that can be resumed
python tests/hil/gui.py --resume [<run>]     # open the GUI and resume
python tests/hil/selftest.py                 # harness self-test: checkpoint and runner loop, CLAUDE.md rule 12 (t_rule12_remoteterm_first), no hardware
```

Each run writes `tests/hil/results/<stamp>/report.md` and `session.log` — every line sent and
received on every port, timestamped, with `# =====` markers per test. Next to them are
`checkpoint.json`, the run's resume state, written atomically when each test starts and ends, and
`run.lock`, an OS lock that marks the run as live in some process. Once a test has written NaviCore's
config, `navicore_snapshot.json` holds NaviCore's exact config from before that test (§5, §9). `report.md` is rebuilt
from the checkpoint after every test. A run of five or more tests also reads `?NVS` on each WCB with its own USB cable at
its start and end: the settings-storage use goes into session.log, a line per board under the report's summary,
and `tests/hil/results/nvs_history.csv`, so a store creeping towards full shows across runs (`hil/nvs.py`). Creating a file named `PAUSE` in the run folder, or `results/PAUSE`,
pauses the run at the next test boundary (§9). The wires found last time are in
`results/links.json`. The directory is gitignored: the log carries the mesh password in the WCBs' lines
(`?backup`, `?MGMT,PULL`), and `navicore_snapshot.json` and `results/navicore_config_week_start.json` hold
NaviCore's. NaviCore's and the SBUS controller's own lines in the log have every credential hashed (§5). The
checkpoint and the report store the password and WiFi credentials only as hashes, including where a failure message
quotes them.

**Before a run, close anything holding a bench port** — the Arduino IDE serial monitor, Wizard
or NaviCore tool tabs. A COM port has one owner. The GUI's *Close all ports* hands them back.

---

## 1. What a run does to the bench

The suite is not read-only. It **changes saved config** (labels, baud, sequences, variables),
**moves servos** (including Maestro subroutine restarts), **plays NaviCore animations**, moves
the SBUS controller's virtual sticks, and **reboots WCBs**. `run.py --no-servos`, or `no_servos` in
`bench.json` (§2), runs everything except the tests that can move a real servo.

Every test that changes saved config runs inside `config_guard` (`suites/common.py`): it
snapshots each affected board's config chain first and **fails the test if the board does not
end byte-identical**, even when the test body itself failed, naming the missing and extra
tokens. The snapshot is `?backup`'s configured-boards chain for the USB board and
`?MGMT,PULL,<n>` for a board reached over the mesh, CRC-checked in both cases. `?PEERSLIVE` is
excluded (it moves with learned peers on its own), and a `?SEQ,SAVE` value that itself contains
`^` is re-joined the way restore parses it (`WCB.ino:2326-2349`). After the guard, the harness
refreshes its config cache and re-binds any wire that follows the port's baud. Before it reports a leak, the guard
puts back what it safely can: a leaked `?BAUD`, `?BCAST`, `?LABEL`, `?SEQ,SAVE`, `?MAP,SERIAL`, `?VAR,SET` or `?ALIAS`
token is replayed from the baseline, or its CLEAR form sent when the baseline never had it, and the failure says what
went out (`AUTO_RESTORE`, `suites/common.py`). Identity, radio, ETM, WDP, device and `?MAP,PWM` tokens are never
touched — a replay there can reboot a board or persist a peer — and a leaked delimiter or command character stops the
auto-restore altogether. The test still fails: leaking is a test bug, but the bench is left clean.

A test that writes NaviCore's config runs inside `nc_guard` (`hil/nc_guard.py`, §5) the same way: it snapshots
NaviCore first and fails the test unless NaviCore's config ends byte-identical. The `nccfg` suite (`s40_navicore_config.py`) makes about 45 such saves a run, each rewriting NaviCore's `/config.json` (~14 KB). It changes only what has no live effect on this bench (tool metadata, mappings on matrix slots no SBUS value decodes, a disabled knob, a switch with no tiers, reports to WCB 0), never NaviCore's mesh password, WCB number or channel, and restarts NaviCore only under the `navicore_reboot` opt-in. `nccfg.boardtype_change_no_reboot` keeps a flipped boardType saved for a few seconds: NaviCore must not restart in that window.

After every test the runner also reads each WCB's and NaviCore's console since the test began. A panic there
(`Guru Meditation Error`, `abort() was called`) fails the test, and so does a WCB's `[MESH] ESP-NOW transmit stalled`
(tracker #112); the test's own verdict follows in the detail (`_console_panics`, `_wcb_stalls`, `hil/runner.py`). A
board that restarts mid-test loses state the test may never look at: NaviCore panicked on 8 of 45 boots in two full
runs (D-NC77), and every test through them passed but the one that reads the reset reason.

Two things are deliberately never done, because they cannot be cleanly undone:

- **No test adds a local Maestro id while WDP is on.** A local id is advertised over WDP, every
  other board auto-adds a remote proxy for it, and proxies are never evicted (`CLAUDE.md` rule 5).
  The tests that add a local id, or clear and rebuild the slot table, send `?WDP,OFF` first — it
  stops both the board's adverts and its handling of other boards' adverts (`WCB_WDP.cpp:356`,
  `:488`) — and `?WDP,ON` only once the table is back. The one exception is `maestro.wdp_auto_add_beside_local`, whose subject is that auto-add: it clears the id on W2 first, then W1's proxy, and a POLL proves W1 does not learn it again. Remote proxies are never advertised (only
  local slots are, `WCB_WDP.cpp:142-167`), so adding and clearing one is restorable.
- **No test sends free text to the SBUS controller.** Outside a `{…}` line its serial parser
  treats single characters as commands, and `m` and `w` write flash. Nor a verb that saves: its frame format
  (`mode`) goes out only as the RAM-only INF8 form with `"save":false`, and only once the controller has answered the
  INF8 probe, since an image without the test verbs saves `mode` whatever it says (§5).

**The host's own USB is part of the bench.** Every write to a bench port gives up after 2 s instead
of blocking. A port that vanishes is reopened, with DTR/RTS still low (`hil/serialdev.py`), and so is NaviCore's
when it goes silent: an `expect()` that times out on it with no byte at all since the last command has the reader
reopen it, and the failure says so (`revive_silent`; full run `20261006-122850`). While
tests run, the runner asks Windows not to idle-sleep (`SetThreadExecutionState`). That cannot stop
a lid close, the power button or a critical-battery hibernate, and a run started on battery is
flagged with a WARNING in the log. Two checks catch a host outage after the fact (`hil/runner.py`):
- A test that fails while the host was asleep for more than 5 s of it (`_awake_s()`, which compares
  Windows' sleep-excluding interrupt time with the monotonic clock). After a resume only some USB
  drivers drop their handles, so this is the reliable one.
- Every active bench port failing within 2 s of the others (`host_usb_loss()`): a hub reset or a
  pulled cable.

Either way the test is classified as an ERROR starting `NOT A RESULT`. It is checkpointed as not
run, not recorded as a result, and shows RETRY in the GUI. The run then waits up to 120 s of awake
time (`OUTAGE_GRACE_S`) for every port to come back. It then re-checks the bench: identity, mesh,
saved config and wires. The WCBs are rebooted first, since the cut-off test could not clean up.
After that the test runs again. If the ports do not come back, or a check fails, the run pauses
and can be resumed (§9). A second outage on the same test always pauses. Before each test a
further check runs. A bench port whose reader is waiting to reopen it, or more than 5 s of host
sleep since the last test ended, keeps that test from starting at all. Without it, the next test
and every one after it would fail on dead ports as genuine FAILs.

---

## 2. The bench and its wires

### `tests/hil/bench.json`

| Key | Meaning |
|---|---|
| `devices.<name>` | `port` (COM name; this computer's own ports, as Find devices, Add or a resume last saved them, are kept in `results/ports.json`, untracked, and override it, so a Mac's `/dev/cu.*` names never replace the Windows PC's in git), `kind` (`wcb` / `probe` / `navicore` / `sbus`); a `wcb` also has `wcb` (its board number), a `probe` its `mac`. `wcb1` is the **main console**, which sends every mesh command; any other WCB with its own USB cable is `wcb<N>`, and its config is read with `?backup` on that port instead of a `?MGMT,PULL`. A probe wired to NaviCore's own pins (probe 3, `hil_plan/NAVICORE.md` D-NC37) is an ordinary `probe` entry: discovery finds which of its headers serve NaviCore (below, "NaviCore's own pins"). |
| `mesh_only_wcbs` | Board numbers with no USB cable, reached only through the mesh from `wcb1`. |
| `wiring_plan` | Which probe each WCB's ports are suggested to go to (`{"1": "probe1"}`), header S*n* to port S*n*. Only a suggestion: any header can go to any port on any WCB, and when a header is already used the "what to connect" list suggests the next free one. `"navicore": "probe3"` names the probe on NaviCore's own pins (below): the list never suggests its headers for a WCB port, and the Wiring tab lists and draws NaviCore's five pins against it. A WCB or probe named here that is not plugged in yet is drawn dashed and listed as *(planned)*, so it can be wired first; nothing else (discovery, tests) sees it, and *Find devices* / *Add* give the next new probe the first planned name (`probe3`, then `probe4`). |
| `fixtures`, `device_links` | The wires made by hand between devices, which no probe sees: the SBUS controller's outputs to NaviCore and the Kyber, the Kyber's Maestro and MarcDuino ports to WCB3, the Maestros. `device_links` names each wire's two ends (`W3S2`, `navicore:SBUS_IN`, `kyber:MAESTRO`), its `signal`, `how` to wire it, what to `check` when it misbehaves, and the tests that prove it (`proof`); `fixtures` titles anything that is not a WCB or NaviCore and labels its pins. The Wiring tab draws them in a column of their own (purple SBUS, blue serial) and lists them, with each wire's status the newest result of its proof tests in `results/*/report.md`: green once one passed, red after a failure, amber with none yet (`hil/wiring.py` `device_plan`). It is the bench's troubleshooting guide for these wires. |
| `taps` | WCB ports where a real device already sits on the line, so the probe only listens (`RXONLY`) and never transmits. |
| `port_stimulus` | For a port with a real device, the command that makes it transmit safely and the exact bytes expected, instead of text (e.g. `;M2,getErrors` → `AA 02 21` for a Maestro). For a port whose sender is a device, not the WCB, `{"kyber_button": n}` makes the Kyber send instead: the SBUS controller is routed to it, its pad button n is pressed, and the bytes expected are that button's MarcDuino line (`hil/devchecks.py` `kyber_press`; `W3S5`). Such a wire carries the device's line, never the port's output, so tests never see it (`links.get` hides it, `LinkManager.device_sends`); auto-detect, *Verify*, `link.out` and `probe.device_links` use it. |
| `opt_in` | Tests that are skipped unless named here, because they wear flash or wipe a board's data: `nvs_wear` (fills W1's 100-variable table with persistent variables), `seq_wipe` (clears every W1 sequence, then replays them), `ota_erase` (OTA sessions, each erasing at least 4 KB of a board's inactive app slot), `ota_full` (full-image OTA on W1, two passes), `ota_full_wcb2` (the same, relayed to W2), `ota_wrong_chip` (an S3 image streamed to W1; attended), `navicore_clip` (replays a saved NaviCore clip: servo motion and recorded actions), `navicore_clip_write` (NaviCore takes recorded, saved, uploaded, renamed and deleted as `HIL<nonce>` clips on its clips partition, and replayed; one take runs 60 s to the recorder's backstop; each test fails unless `?REC,LS` ends as it began), `navicore_reboot` (restarts NaviCore in software: its USB re-enumerates, and the mesh and SBUS OUT lose it for about 5 s), `navicore_fault` (NaviCore's config-storage fault hooks `#L91`-`#L93`: a corrupted `/config.json`, an overflowing GET_CONFIG, a failed save; the tests skip on an image built without `NAVICORE_HIL_HOOKS`), `navicore_wire` (the seven `ncwire` tests on NaviCore's own pins: they need probe 3 wired as `hil_plan/NAVICORE.md` D-NC37 has it and `--discover` run after the wiring, and skip, naming the missing N20 wire, without; text out S3-S5, 200 long lines in one test, lines typed into them, SBUS OUT and the Maestro bus read, serialBcast saved for a few seconds inside `nc_guard`; with `navicore_aux_tx` ticked too HCR frames go out S4, and with `navicore_reboot` one test restarts NaviCore), `navicore_ota_erase` (4 KB `?OTALOCAL` sessions on NaviCore, ended by ABORT and by the 30 s idle reaper: each erases the head of its inactive app slot), `navicore_ota_full` (NaviCore re-flashed over USB with the bench image it runs, twice: two restarts, back on its slot), `navicore_ota_relay_full` (the same through W1's `?OTA` relay, ~12 min a pass; run by hand), `navicore_esptool` (watched: the recovery ladder's esptool rungs on the healthy NaviCore, writing the bench image into app0 and `boot_app0.bin` into otadata), `navicore_identity` (attended: a saved invalid NaviCore deviceId, written back over USB), `navicore_nvs` (NaviCore learns a permanent probe client as a mesh peer, forgets it with FORGET_PEER, learns it again and drops it when it comes back temporary: four writes of its learned-peer list to NVS; W1 and W2 learn and forget the probe too), `navicore_aux_tx` (routes an HCR, MP3 Trigger, DFPlayer or WLED to NaviCore's own S3-S5 for a few seconds and runs `#L20`/`#L21`: device-protocol bytes go out J4-J6, where nothing is recorded as attached; a hook image's `DBG_WIRE` log reads them back), `navicore_wifi` (a spare WiFi adapter on the PC joins NaviCore's access point for ~30 s to 3 minutes in each of fifteen `ncwifi` tests and six Intellex ones - `intellex.ws_transport_navicore` and `s35`'s - under a temporary profile with the SSID and password read from NaviCore's config; a PC whose only adapter carries its internet skips them; `ncwifi.ws_ping_soak` streams for 5 minutes; with `navicore_reboot` ticked too, two tests restart NaviCore and one may, D-NC62), `navicore_webserial` (attended: NaviCore's own port goes to Chrome over real Web Serial, `tests/wizard/.profiles/navicore`, whose first run asks someone to pick the port; the open restarts NaviCore, and `nctool.webserial_flash_same_image` runs the config tool's Full Wipe & Flash with esptool-js: the custom bootloader, the partition table and the bench image into 0x0, 0x8000 and app0, NVS and otadata erased, then a check that the config and clips came through), `intellex_reboot` (a NaviCore REBOOT sent through Intellex, over its own serial transport or, with `navicore_wifi` ticked too, over WiFi through NaviCore's access point: its USB port re-enumerates, and the mesh and SBUS OUT lose it for about 5 s; inside `nc_guard`), `intellex_nc_save` (the NaviCore config tool inside Intellex saves NaviCore's config twice, `chRateHz` one step away and back: two rewrites of its `/config.json`, inside `nc_guard`), `intellex_flash` (W2 re-flashed through Intellex's esptool path with the bench image it runs, from a seeded offline cache: the Wizard's Update, Flash and an Update with a second flash refused, and a full flash the host refuses; W2 is off the mesh about a minute a flash and ends on its version and config), `intellex_flash_factory` (attended: the Wizard's Factory Reset through Intellex erases W2's NVS, which the harness restores from W2's chain), `intellex_flash_navicore` (the config tool's Update Firmware through Intellex rewrites NaviCore's app0 with the bench image it runs and restarts it; inside `nc_guard`), `intellex_wifi_join` (attended: with Intellex attached to NaviCore's access point, the PC's spare adapter hops to W1's and back, and Intellex's own `wifi_bounce` disconnects and reconnects it), `sbus_reset` (reboots the SBUS controller), `wifi_modes` (W1's access point off and back, joining W2's, its access point up under its derived name, W2's access point lost and rejoined, an absent network looked for: up to ten W1 and two W2 reboots across its tests), `wifi_pc` (attended: a WiFi adapter on the PC joins W1's access point for ~30 s in each of six tests, the spare one when there is one), `mesh_password` (attended: W1 runs on a throwaway mesh password for a few seconds), `nvs_erase` (attended: erases all of W1's settings and restores them from its chain, three reboots per test), `nvs_fill` (boots W1 once on the sequence store's NVS fallback, `?DEBUG,SEQNVS`, fills its settings storage with throwaway sequences until one is refused, then removes them and boots back: two extra reboots per test). Two long measurements are opt-in for their length: `softrx_erratum` (`softrx.erratum_pairs`, ~15 min of soft-port input into W1 S3-S5; needs wcb_probe 4) and `w1s4_soak` (`soak.w1s4_wire`, W1's S2/S4 fan-out for `soak_minutes`), `etm_seq_wrap` (drives W1's ETM sequence counter past 65,535 with about 65,000 untracked JSON broadcasts typed on its console, its port broadcasts off meanwhile, then checks a unicast sent right after the wrap still runs on W2: several minutes of mesh flood, one W2 reboot). Every key, with its title, one line on what it does and a per-test time estimate, is registered in `hil/optin.py` (`OPT_INS`). The runner skips a gated test before it starts, with `opt-in: add "<key>" to bench.json "opt_in" (<why>)`, unless the key is here. The GUI's Tests tab has one checkbox per key (§4), which writes this list. |
| `soak_minutes` | How long `soak.w1s4_wire` runs, in minutes (default 20). |
| `no_servos` | `true` skips every test that can move a real servo, for a run with nobody watching the bench. `hil/servos.py` lists them by id, each with its reason, and names the tests it read and left out. On this bench the servos are Maestro 2 on W2 S1 and NaviCore's local Maestro 1, the dome's pie and panel servos. W1 holds an `M1:W20` proxy beside its local Maestro 1 on the W1 S1 probe, so every `;M1` subroutine or move verb typed on W1 also runs on the dome (`maestro.fanout_remote` proves the dispatch); `maestro.*` move tests are not probe-only. Also listed: Maestro 2 moves, NaviCore's `SET_MODE` (J2 moves), `TRIGGER` and clip replay, a stick on a bound channel, and every test that moves a controller channel at all, because NaviCore re-emits each channel on SBUS OUT (`sbusOutEnabled` is on) and nothing records what is wired there. The runner skips each one before it starts with `moves a servo (--no-servos)`, after a missing wire or device and before an opt-in. `run.py --no-servos` does the same for one run and leaves `bench.json` alone. The flag is kept in the run's checkpoint, so `--resume` and the GUI's *Resume* keep it, and `run.py --resume --no-servos` turns it on for the rest of a paused run. `run.py --list` tags these tests `[servo]`, or `[servo: skipped]` under the flag or the key. The key fails safe: any value but a missing key, `null`, `false`, `0` or a string saying no counts as on, so a hand-typed `"true"` cannot let a servo move. The GUI's *No moving servos* box (§4) writes it. A new test that can move a servo goes into `hil/servos.py`; `selftest.py` fails on a listed id that no suite registers. |
| `navicore_repo` | The NaviCore tree the config tool's board tests (`nctool.board_*`, `nctool.webserial_*`) serve, passed to them as `NAVICORE_REPO` (`hil/wizard.py` `navicore_repo_env`): the tree the bench's NaviCore image was built from, so the tool and the firmware under test are one pair. This bench sets the `hil-week` worktree. Unset, and for every no-board spec, the tool is served as it is on disk in the sibling NaviCore checkout (D-NC10). `NAVICORE_REPO` set in `run.py`'s own environment reaches every config-tool spec and Intellex's staged copy of the tool (`hil/intellex.py`) as well: how a NaviCore tree is verified before the sibling checkout has it. |
| `wifi_test_interface` | The WiFi adapter the tests that join an access point use (`hil/wlan.py` `pc_on_ap`: s28's `wifi_pc` tests, s45's `navicore_wifi` ones and Intellex's WiFi tests in s33 and s35), by its `netsh wlan show interfaces` name. Unset, a test takes an adapter that does not carry the default route, so the PC stays online; with only one adapter s28's tests use that one and the PC is offline for the test. NaviCore's tests never take the adapter that carries the default route, named here or not: they skip (`NAVICORE.md` D-NC14). Off Windows it is not read: the harness joins nothing there and uses the spare adapter already on a 192.168.4.x network (`hil/wlan.py` `_prejoined`, D79). |
| `discover_skip` | Port keys (`"W2S1"`) that discovery leaves out. |
| `maestro_safe_sub` | A Maestro subroutine number that is safe to run on Maestro 2 and on every NaviCore Maestro. Without it, `maestro.m0_broadcast` checks only `;M0,stopScript` and skips the subroutine broadcasts. |
| `port_devices` | Real devices wired to WCB ports instead of a probe, keyed by port: `"W1S5": {"kind": "navicore", "detail": "S1"}`. Kinds: `maestro`, `navicore`, `hcr`, `mp3`, `dfp`, `wled`, `wcb`, `kyber`, `other`. Set from the Wiring tab. A probe wire on such a port is always a listen-only tap. Unless `port_stimulus` names a safe command for the port, the port is closed to test traffic: tests never see a wire on it (`links.get` hides it); a test that names the port (as a wire, as a literal `;S<n>`, `;W<n>;S<p>` or `W<n>S<p>` in its source, or in `drives=[...]`) skips and names the device; auto-detect, *Verify* and `link.out` send nothing to it; and a wire added there by hand survives auto-detect. Broadcast fan-out still follows the board's own `?BCAST` settings, so turn broadcast output off for that port on the WCB. |
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

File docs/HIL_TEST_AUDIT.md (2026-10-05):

# HIL test audit — are the tests valid, and do they cover everything?

Working document, like `HIL_FIX_TRACKER.md`. Started 2026-09-23 at Greg's request: review `tests/hil` (and the
`tests/wizard` layer it drives) and record, test by test, whether each is a *valid* test — it can only pass when the
behaviour it names works — and where the firmware is left untested. Written to survive a context cut: every
section below is updated as the review goes, so a cold session can pick up at **§5 Resume here**.

Read `docs/HIL_TESTING.md` first (what the harness is), then this file. Nothing here changes a test; each finding
says what a fix would be, and the fix is separate work.

**Status 2026-09-23: the read-through is complete.** All 28 suites (422 tests), the harness core and `tests/wizard`
were read; 23 test findings (A1-A23) and one firmware observation (F1) are recorded, and §4 holds the coverage
diff. Nothing in `tests/hil` was changed and the bench was not used. `python tests/hil/selftest.py` passed 39/39 on
this tree.

## 1. Method

**Validity.** Each test was read against the harness primitives (`hil/*.py`, `suites/common.py`) and, where it
asserts a firmware specific (a byte sequence, a message, a limit), against the firmware source. A test is marked
with one or more of these codes when it does not hold up:

| Code | Meaning |
|---|---|
| V1 | **Vacuous** — can pass with the feature broken (e.g. asserts only that *something* printed, `expect` on a substring a stale line satisfies, a loop that asserts nothing when the list is empty). |
| V2 | **Asserts the wrong thing** — the assertion does not match the test's title/docstring, or checks a proxy (an ACK, a console echo) where delivery on the wire is the claim. |
| V3 | **State not restored** — changes saved config, RAM state, a peer table, a device, or a bench setting outside `config_guard`/its own restore, or restores in a way that can leave residue on failure. |
| V4 | **Timing luck** — a fixed sleep or a window that races the firmware, so a pass or a fail depends on load. |
| V5 | **Unchecked precondition** — depends on bench state (a config token, a wire's baud, WDP on, a peer online) it neither checks nor establishes, so a false FAIL or a silent SKIP. |
| V6 | **Stale vs firmware** — asserts a message or behaviour the current source no longer has (cite `file:line`). |
| V7 | **Helper misuse** — mark/since ordering, a read across a probe restart, `WCB.run()` across a delimiter/CMDCHAR change, `expect` where exact bytes are meant. |
| V8 | **Skips where it should fail** — a `Skip` raised for a condition that is the feature under test being broken. |
| V9 | **Redundant / mis-titled** — duplicates another test, or the id/area is misleading. |
| OK | Read; holds up. A note may still follow. |

**Completeness.** §4 lists firmware behaviour with no test, from the dispatcher and help text (`WCB_Help.cpp`,
`WCB.ino` command handlers, each `WCB_<area>.cpp`), compared with the registry (`grep '^@test(' suites/*.py`). The
2026-09-15 coverage audit in `HIL_TESTING.md` §7 is the baseline; §4 records what a fresh diff shows.

**What was not done.** Nothing ran on the bench during this audit (another session held the boards). Findings are
from reading; a finding that needs a bench run to confirm says so. The WcbCmd byte tables (HCR, MP3, DFPlayer, WLED,
Maestro) were spot-checked by hand (Maestro and DFPlayer frames re-derived), not re-derived in full.

## 2. Progress

Status: `read` (findings recorded) → `verified` (the finding's firmware claims checked against source).

| Suite | Tests | Status | Findings |
|---|---|---|---|
| harness core (`hil/*.py`, `suites/common.py`) | — | verified | A1-A4 |
| `s00_probe.py` | 2 | read | A5 |
| `s01_links.py` | 1 | read | OK |
| `s02_navicore.py` | 3 | read | OK |
| `s03_wcb.py` | 4 | verified | A6 |
| `s04_serial.py` | 7 | verified | OK |
| `s05_mesh.py` | 6 | verified | A7 |
| `s06_persist.py` | 4 | verified | A1 |
| `s07_seqvar.py` | 4 | verified | A1 |
| `s08_maestro.py` | 7 | verified | A8, A9 |
| `s09_wled.py` | 2 | read | A9 |
| `s10_navicore_mesh.py` | 3 | read | OK |
| `s11_sbus.py` | 2 | read | OK |
| `s12_serial_input.py` | 47 | verified | A1, A10-A13 |
| `s13_serial_mapping.py` | 36 | verified | A14, A15 |
| `s14_pwm.py` | 23 | verified | A16-A18 |
| `s15_hcr_mp3_dfp.py` | 35 | verified | A19, F1 |
| `s16_vars_if.py` | 31 | read | OK |
| `s17_seq_inventory.py` | 28 | read | OK |
| `s18_etm_config_wdp.py` | 43 | verified | A20, A21 |
| `s19_client_mesh.py` | 21 | read | A22 |
| `s20_ota.py` | 32 | read | A21 |
| `s21_navicore_sbus.py` | 38 | read | A21, A23 |
| `s22_maestro_kyber.py` | 29 | read | OK |
| `s23_softrx_measure.py` | 3 | read | OK |
| `s30_wizard.py` + `tests/wizard` | 7 | read | OK (gaps in §4) |
| `s99_etm.py` | 4 | verified | OK |
| coverage (§4) | — | done | help-text diff + dispatcher diff |

499 tests registered (2026-09-24, branch `WIFI`): 422 at the review on 2026-09-23 (uncommitted s12/s18 edits from the WDP-DA work included), the rest are the §5 additions, the §7 suites s24-s29 and s31, and the F20/F21 tests.

## 3. Findings

Numbered `A<n>` so the fix tracker can cite them. Severity: **S1** a test that can pass with the behaviour broken
or that damages the bench; **S2** a test that fails or skips for the wrong reason, or asserts something other than
its title; **S3** a nit (naming, a doc line, a redundant check). `F<n>` is a firmware or doc observation the review
turned up that is not a test defect. No S1 was found.

**Overall verdict.** The suites are valid tests in the sense that matters: they assert bytes on the wire and exact
console lines, never ACKs; every `(should)` test cites the code it guards; state changes are restored, usually in a
`finally`; preconditions are declared with `require_tokens` or a `Skip`. The substantive problems are three: the
harness detects a leaked config change but never restores it and 27 tests would leave one behind on failure (A1);
one test under-asserts against a bar the firmware has since raised (A10); and one documented firmware path, WDP PWM
self-heal, is never exercised (A17). Everything else is a nit.
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

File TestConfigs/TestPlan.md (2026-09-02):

# WCB System Test Plan

**Firmware branch under test:** _______________
**Tester:** _______________  **Date:** _______________

---

## Hardware Reference

| Board | HW Ver | Port | Connected Device | Notes |
|---|---|---|---|---|
| WCB1 | v2.1 | S1 | *(empty)* | |
| WCB1 | v2.1 | S2 | Kyber — Maestro port | 57,600 baud |
| WCB1 | v2.1 | S3 | Kyber — Marcduino | 9,600 baud |
| WCB1 | v2.1 | S4 | *(empty)* | |
| WCB1 | v2.1 | S5 | SparkFun MP3 Trigger | 9,600 baud · Raw serial ↔ W3S2 |
| WCB2 | v2.4 | S1 | Maestro ID1 | 57,600 baud |
| WCB2 | v2.4 | S2 | Maestro ID2 | 57,600 baud |
| WCB2 | v2.4 | S3 | PWM Input — Maestro ID2 Ch1 | |
| WCB2 | v2.4 | S4 | Servo 3 — PWM Output | Mapped from W2S3 |
| WCB2 | v2.4 | S5 | Servo Controller Board | 9,600 baud |
| WCB3 | v2.3 | S1 | Maestro ID3 | 57,600 baud |
| WCB3 | v2.3 | S2 | Marcduino Clone — MP3 source | 9,600 baud · Raw serial ↔ W1S5 |
| WCB3 | v2.3 | S3 | Marcduino Clone Serial Interface | 9,600 baud |
| WCB3 | v2.3 | S4 | *(empty)* | |
| WCB3 | v2.3 | S5 | Servo 4 — PWM Output | Mapped from W2S3 |

## Test Configurations

| Config File | Loads on | Used for Phases |
|---|---|---|
| `WCB1_01_base.txt` | WCB1 | 2, 3, 3B, 4, 10, 12, 13 |
| `WCB2_01_base.txt` | WCB2 | 2, 3, 3B, 4, 10, 12, 13 |
| `WCB3_01_base.txt` | WCB3 | 2, 3, 3B, 4, 10, 12, 13 |
| `WCB1_02_full.txt` | WCB1 | 5, 6, 7, 8, 11, 14 |
| `WCB2_02_full.txt` | WCB2 | 5, 9, 11, 14 |
| `WCB3_02_full.txt` | WCB3 | 5, 8, 9, 11, 14 |

> **How to load:** Open the board's terminal in the wizard, copy the `PASTE:` line from the config file, paste and press Enter. Verify with `?config`.

---

## Phase 1 — Wizard: Detect & Flash

**Load config:** None — wizard handles this
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

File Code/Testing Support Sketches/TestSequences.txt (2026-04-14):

Testing
;M21
;w3;s3track1 *** plays track 1 through marcduino clone
;a,play,1 *** plays track 1 via native mp3 trigger
:PP100:L0:A180:A2
;t4000
:D308
:PL1:P20:W3:H

mp3Finish
;m31

onError
;M01

stpe 7 header wrong

checksum falst?

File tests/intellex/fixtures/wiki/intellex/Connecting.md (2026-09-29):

# Connecting

A crafted page with no sidebar of its own: the viewer lists the pages instead.

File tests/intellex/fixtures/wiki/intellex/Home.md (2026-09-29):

# Intellex HIL Home

A crafted page for the Intellex HIL tests. See [[Connecting]].

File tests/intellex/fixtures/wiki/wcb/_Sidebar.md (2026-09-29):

**[Home](Home)**

### Start here

- [[Getting Started]]
- [[Home]]

### Reference

- [Reference page](Reference-Page)

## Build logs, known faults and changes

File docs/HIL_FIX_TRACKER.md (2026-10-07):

# HIL fix tracker — the 2026-09-16 bench run

Working document, not a design doc. Delete it when the list is done.

**What this is.** The 2026-09-16 full run (`tests/hil/results/20260916-122250`) failed 57 tests. Each was
traced to source by a subsystem agent and then attacked by two independent skeptics; 55 distinct defects
came out, and all but one survived. This file is the work list, with enough of each diagnosis to resume
cold. Full analysis transcripts are gone with the session — what is here is what remains.

**Verdict split.** 55 of the 57 failures are real defects (A). One is a test bug (B):
`input.soft_rx_baud_sweep`'s 38400 bar is above what a bit-banged port can do — but the same test also
found a real `?BAUD` range-check gap, so split it rather than just relaxing it. One cannot pass as
written (C): `hcr.softserial_integrity_mesh_load` asserts 300/300 frames exact against a stochastic
~0.3 % fault, so it needs a residual budget plus a signature check. `sbus.btn_single_tap` failed only
because the SBUS controller's USB handle had died; it passed once the GUI was restarted.

**Ownership.** Most of the list is this repo. Flagged otherwise: `WcbCmd` (2 — push it BEFORE the
firmware, CLAUDE.md rule 1), NaviCore (3), `WCBClient` (2).

## How to work this list

1. Fix in tracker order (high impact first, small effort first within a tier).
2. Compile after each: `arduino-cli compile --fqbn esp32:esp32:esp32:PartitionScheme=min_spiffs
   --build-path <scratch> --output-dir tests/hil/results/builds/wcb-esp32-meshq Code/WCB`
   (never run arduino-cli while the Arduino IDE is compiling — use an isolated build path).
3. Flash both boards, then run the defect's tests:
   `arduino-cli upload --fqbn esp32:esp32:esp32:PartitionScheme=min_spiffs
   --input-dir tests/hil/results/builds/wcb-esp32-meshq -p COM6` (and `-p COM15`), then
   `cd tests/hil && python run.py "<test id>"`. Close the GUI first — one owner per COM port.
4. Update the row's status here, and add a dated line to the session log below.

Status values: `TODO`, `WIP`, `FIXED (unverified)`, `VERIFIED` (test green on hardware), `DEFERRED`.

## Session log

| Date | What happened |
|---|---|
| 2026-10-07 | Filed and fixed **#113** (`41ce60b`): a WebSocket client that left W1's access point without closing held up to a TCP send buffer of heap and stalled `loop()` 5 s per send, until no client could connect. VERIFIED by the new `ws.vanished_client_released`; #111's two-client limit verified on the bench by `ws.client_slots` (`20261007-142719`). |
| 2026-10-07 | **#11**'s residual race seen (`client_mesh.rejoin_seq_reuse`, `20261007-090301`: W1 re-adopted a re-joined probe after its three boot announces and dropped two commands as duplicates) and fixed in `77a39d2`: a boot announce now clears the sender's duplicate ring whether or not it is a peer yet. VERIFIED by the new `client_mesh.rejoin_unadopted`: `[0, 0, 0, 1]` on `48da52a`, `[1, 1, 1, 1]` on `77a39d2`. |
| 2026-10-07 | **#111** decided (Greg: two WebSocket sessions) and FIXED (unverified): `48da52a`, `WS_MAX_CLIENTS` 3 to 2, flashed on W1-W3 as `6.2.1_070853ROCT2026`. Not measured yet: that needs a PC on W1's access point (the Windows PC, or the Mac's TP-Link moved there). |
| 2026-09-29 | Filed **#110** (a PC waits up to 47 s for a lease on W1's access point) and **#111** (with an access point up the heap's low-water mark reaches 76 bytes on W1 and 240 on W2), both found writing WCB-WP22 (`20260929-055154`, `-055837`). |
| 2026-09-29 | Filed **#109** (a relayed STATS, ETM,CHAR or sequence reply is sent once; NC-WP6's first bench run lost an ETM,CHAR reply to the load it had started). |
| 2026-09-29 | Run `20260929-023811` on `6.2.1_290236RSEP2026` (29 pass, 1 known skip): **#108** VERIFIED; the pacing retune (D54) passes `kyber.*` with no frame given up and the whole `etm.seq_wrap` flood; the four other fixes from `20260928-220200` pass. |
| 2026-09-29 | Full run `20260928-220200` triaged (816 pass, 31 fail, 9 skip; 26 fails are `(should)` tests): the #102 pacing retuned (a 50 ms give-up lost a Kyber frame), the RTERM ring back to 2.5 KB, and `?SEQ,SAVE` names an out-of-memory argument copy instead of 'Invalid format' (D54). |
| 2026-09-28 | **#103** VERIFIED on `6.2.1_282121RSEP2026` (`20260928-212350`, 11 of 11 `wifi.*`): JOIN scans the mesh channel before each connect (`5770675`) and reads its association from the driver (`e55ba82`). |
| 2026-09-28 | Filed **#108** (an ETM command is ACKed before it is queued, so a full command queue loses it; seen as seven discards during `etm.seq_wrap` on the #102 image). |
| 2026-09-28 | Run `20260928-205106` on `6.2.1_282046RSEP2026` (all 65 `etm.*`, `mesh.*` and `mgmt.*` pass): **#102** and **#107** VERIFIED; `etm.seq_wrap` survived its whole flood. |
| 2026-09-28 | **#102** and **#107** FIXED (unverified): every ESP-NOW send is paced by `wcbEspNowSend` (CLAUDE.md rule 16), and the RTERM relay keeps its lines in a byte ring and reports what it loses (D50). |
| 2026-09-28 | Run `20260928-201415` on `6.2.1_282006RSEP2026` (14 pass, 2 fail): **#104**, **#105** and **#106** VERIFIED; the two JOIN failures (#103) showed the radio off the mesh channel during the search; `mesh.rterm_long_output` passed whole (#107 intermittent). |
| 2026-09-28 | Full run `20260928-161745` triaged (768 pass, 28 fail, 7 skip): **#105** (a Kyber bridge task read a soft port while ?BAUD re-began it: W1 panicked) and **#106** (a stale RX-overflow claim on an OTA drop line) filed and FIXED (unverified) with **#104** (`WiFi.persistent(false)`); **#107** (the RTERM mirror loses lines of a long burst) filed. |
| 2026-09-28 | Wave 3 group 2 on `6.2.1_280758RSEP2026` (`20260928-160300`): 17 pass. Filed **#102** (a mesh-send flood exhausts the heap and W1 aborts, `etm.seq_wrap`), **#103** (JOIN mode drops mesh unicasts while looking for an absent network; no loss or rejoin reported) and **#104** (`nvs.net80211` grows with every JOIN `WiFi.begin`). |
| 2026-09-28 | **#101 VERIFIED** (`20260928-080619`). The s12/s13/s16/s17 tests on `6.2.1_280758RSEP2026`: 16 pass in `20260928-080156`, two ERRORs from a missing `nonce` import in s12 (an agent cannot run its tests), fixed and passing. |
| 2026-09-28 | **#101 filed and FIXED (unverified)**, found by the WCB-WP32 test writer: a USB line the heap could not hold ran its head alone, unverified (D39). |
| 2026-09-28 | **#98 and #99 VERIFIED** on `6.2.1_280741RSEP2026` (W1/W2 flashed about 07:50): `20260928-074616`, 22 of 22 (#98's test and the 21 s15/s24 tests). |
| 2026-09-28 | The s14/s22 tests on `6.2.1_280727RSEP2026` (`20260928-073122`): 23 pass, `kyber.local_targets_one_write_per_port` skipped (W1 holds a Maestro 3 proxy), and #98's test failed on the first fix, which never matched a remote slot; corrected for the next image. **#100 filed, deferred** (D38): cleared devices and PWM outputs leave NVS keys (W1 +21 entries). |
| 2026-09-28 | **#99 filed and FIXED (unverified)**, found by the WCB-WP26 test writer: a device and a serial mapping could share a port (D37). |
| 2026-09-28 | **#98 filed and FIXED (unverified)**, found by the WCB-WP53 test writer: `?KYBER,LIST`'s copy-paste line for another board used this board's rate and label for the port number (D36). |
| 2026-09-28 | **#95 and #96 VERIFIED** on `6.2.1_280150RSEP2026` (W1/W2 flashed 06:55): the wave-1 verification run `20260928-064402` (79 tests, 77 pass; the two failures were test bugs, fixed and passing in `20260928-070402`), and #96's late-ACK case in `20260928-070457`. |
| 2026-09-28 | **#96 filed and FIXED (unverified)**: a learned peer's broadcast ACK that arrives after the configured boards' ACKs resolved the entry now promotes it too, so it is retried from then on. **#97 filed, deferred** (D32): on a full NVS a new mapping or device saves its port flags first and can leave the port blocked with nothing on it after a reboot. Both found by this wave's test writers (WCB-WP19, WP42). |
| 2026-09-28 | **#95 filed and FIXED (unverified)**, found by the WCB-WP13 test writer: a data-carrying verb spelled in mixed case (`?Mgmt,`, `?Seq,`, `?Wifi,`) with a trailing '?' printed the help page, and `;Seq<key>` was refused. Decided in Greg's absence (`docs/HIL_WEEK_DECISIONS.md` D31). |
| 2026-09-27 | **#94 VERIFIED** (decided in Greg's absence, D5): one RMT symbol per PWM output pulse. `pwm.*` 26/26 (20260927-130212); both passthrough tests five more times, with the new held-pulse check (20260927-131152 to -131509, 20260927-174251 to -174402, 3/3). The one failure among them was the test's filter check counting a late pulse of the previous step, a harness race now fixed. |
| 2026-09-25 | Full run `20260925-092255`: 493 pass, 2 fail, 4 skip (docs/HIL_TEST_AUDIT.md §5). Filed #94 (a bit-banged PWM output pulse is stretched by preemption, audit F23), TODO for Greg's decision. `etm.reboot_defer_cap` was the harness: fixed in `WCB.run` and the reboot cleanup. |
| 2026-09-25 | **WcbCmd 0.9.1 pushed (`0ab4af5`)** with #2 and #21, on Greg's word. Before it, GitHub's WcbCmd (`e51c39b`) still had both bugs, so every CI build of WCB and NaviCore did: only local builds, from the sketchbook copy, had the fixes. The `DEVICE,2` golden vector added in 0.8.0 fails on that code, so the vectors had never been run. They now pass on a host build of the sketch (107 OK); not yet flashed to an ESP32. Version 0.9.1 rather than a re-used 0.9.0; not tagged. The WIFI binaries at `cd3746e` predate it and pick it up on the next `Code/**` push. |
| 2026-09-25 | No-servo full run `20260924-234056` on the F20/F21 image: 459 pass, 3 fail, 37 skip; all three test-side (docs/HIL_TEST_AUDIT.md §5), none from #91-#93. Test fixes to the offline-timing floor (plus #80's alternation check), the `?backup` chain parser and `?ETM,CHAR`'s peer wait; verified `20260925-015720` (21/21). Recorded audit F22 (a rebooted WCB sees its peers offline for one heartbeat), not filed here: the recommendation is to leave it. |
| 2026-09-24 | **#92 and #93 VERIFIED (20260924-233628, 43/43).** Greg: "Fix both". A cleared serial mapping frees its NVS keys; RTERM re-arms and `?STATS,RPT` no longer hold off a deferred restart, which also goes anyway after 20 s. A review found three small defects, fixed before flashing: `_act` written last, a slot whose count could not be stored keeps its output keys, and no ETM command is ACKed once the restart is imminent. W1/W2 flashed 23:36. The harness gained `--no-servos` (`hil/servos.py`, 27 tests, cross-checked by a second list). |
| 2026-09-24 | **#92, #93 FIXED (unverified)** on Greg's "Fix both": a serial-mapping save removes the keys no active mapping uses (`removeUnusedSerialMapKeys`), and a deferred restart ignores a re-arm of the running RTERM session and `?STATS,RPT`, with a 20 s cap (`RESTART_MAX_DEFER_MS`; sized in #93, not the 15 s proposed). Tests `map.nvs_keys_freed`, `etm.reboot_rterm_rearm`, `etm.reboot_stats_rpt`, `etm.reboot_defer_cap`. ESP32 70 %, S3 68 %, no new warnings; host tests and `selftest.py` pass; not flashed. |
| 2026-09-24 | Full run `20260924-190733` on the F13 image: 478 pass, 8 fail, none from F13 (docs/HIL_TEST_AUDIT.md §5). Filed #92 (a cleared serial mapping's NVS keys leak, audit F20) and #93 (RTERM re-arms starve a deferred reboot, F21), both TODO for Greg's decision; five harness fixes; reruns `20260924-205621`, `20260924-213158`. |
| 2026-09-24 | **#91 VERIFIED (20260924-190431).** F13 on Greg's word: a `?MGMT,PULL,<n>,P` of a config over 2912 characters arrives in parts, refusals are coded `[MGMT:CFGERR` lines, the target's reply is a non-blocking job, and the Wizard serialises pulls per relay (docs/MGMT_RELAY.md). Designed and reviewed by agent workflows (45 design issues, 15 code findings), implemented in the firmware, the Wizard, the harness and both WCBClient relays; W1/W2 flashed 19:04, backup and pull output byte-identical to before. Audit F14-F19 recorded, not fixed. |
| 2026-09-24 | **#90 VERIFIED (20260924-133332).** Greg took the recommendation: `?backup` streams its chains with a running CRC, and the mesh pull is measured, reserved once and never sent partial. The first build (20260924-131417) wrote 256 bytes at a time, and a peer's came-ONLINE line split a chain after a reboot; the writer now buffers 2 KB and flushes per line. W1/W2 flashed at 13:33 from `tests/hil/results/builds/wcb-esp32-meshq`; their `?backup` and the W2 pull are byte-identical to before. probe2's COM11 had been held by `Intellex.exe`, stopped with Greg's OK. Found audit F13: a pull over 2912 characters still gives the requester nothing. |
| 2026-09-24 | **#84-#89 VERIFIED, #90 filed.** Greg's decisions on the audit's F5-F10: `?TRACK` removed (#85), a negative `;T` delay refuses its chain (#86), `?LABEL` names a bad port (#87), `?ERASE,NVS` clears every namespace (#88), the sequence-list writes are checked (#84), and `?NVS` reports storage use, recorded by the harness per run (#89). Verified in 20260924-120036 and, for #84, 20260924-120958; W1/W2 run that image from `tests/hil/results/builds/wcb-esp32-meshq`. Filling W1's store showed `?backup` printing only a checksum where its one-line chains belong once the heap cannot copy them (#90, audit F12, Greg's decision). |
| 2026-09-24 | **Full run 20260924-092602 (servos on): 459 PASS / 6 FAIL / 8 SKIP in 1:45:28.** Three storage failures (`var.cap_persistent_full`, `inv.seqget_largest`, `seq.cycle_guard_reuse`) were a full NVS on W1 and pass once it is wiped (`20260924-112513`); nothing reports NVS usage (`docs/HIL_TEST_AUDIT.md` F10). The empty `?SEQ,SAVE,HILL1,` left behind is a firmware bug, filed as #84. `input.wdpda_port_full` lost one announce on W1 S4. `sbus.signal_loss_controller_reset` and `wifi.pc_joins_ap_ws` were test bugs, fixed and re-run to pass. |
| 2026-09-24 | **#81-#83 VERIFIED.** W1 and W2 flashed from `tests/hil/results/builds/wcb-esp32-meshq` (both report `6.2.1_232316RSEP2026`; the session's flash was refused by the auto-mode permission check until Greg switched the permission mode). The seven tests that depend on the fixes all pass (run 20260924-092423). The CI release of the same version name in `Code/bin` is a different image, so the bench build now lives in `wcb-esp32-meshq`, which the OTA tests stream; the previous build is kept in `wcb-esp32-meshq-231928`. Full run 20260924-092602 started, servos allowed. |
| 2026-09-24 | **#81-#83 filed and fixed from the HIL test audit** (`docs/HIL_TEST_AUDIT.md` F1-F3): the HCR/MP3/WLED soft-serial guards allow up to 57600 like `?BAUD`, the help's legacy PWM spelling, and `?HW` updating the running version. Compiled locally (ESP32 69 %, S3 68 %) into `tests/hil/results/builds/wcb-esp32-meshq`; NOT flashed - the session may not write the bench boards - so the three stay FIXED (unverified) until the image is on W1/W2 and `hcr.config_rejects mp3.config_rejects wled.config_rejects devices.soft_ports_fast_baud wled.soft_port_57600 ident.hw_setter pwm.legacy_forms` run. The audit's suites s24-s28 and the Wizard tests landed the same night (451 tests). |
| 2026-09-23 | **Full run 20260923-192959 on the pushed images (WIFI 95dd811/078a907, 6.2.1_231928RSEP2026 built locally; wcb_probe 7): 415 PASS / 0 FAIL / 5 SKIP in 1:59:25**, no probe panic, no host outage. Skips: the three WDP-DA label checks (need an unlabelled W1 port) and the opt-ins left off (`ota_wrong_chip`, `w1s4_soak`). Before it: #80 verified (`etm.offline_detection_timing` 10/10, no race fingerprint in 45 OFFLINE events), the probe crash loop reproduced on v6 (6 panics in 3 W1 reboots) and gone on v7 (0 in 10), and the three other failures of 20260923-154611 pass. CI on the push: firmware build (EspSoftwareSerial bundled, not installed), Wizard tests, WDP wire tests, Wizard preview - all green. |
| 2026-09-23 | **Full run 20260923-154611 (probe 6): 4 FAIL, all diagnosed and adversarially verified.** `etm.offline_detection_timing` = a pre-existing cross-core race on `boardTable` presence, filed and fixed as **#80** (spinlock helpers). `peers.controller_off_on` = test bug (an ACK during the OFF window re-adds WCB20; now excused only when that ACK is logged). `client_mesh.rejoin_seq_reuse` + `input.mesh_bcast_to_ports` = the probe: wcb_probe 6 boot-looped on interrupt-WDT panics after a CPU-only reset left a soft-RX level arm with no handler, and the harness kept reading its lost channel - #78's new failure mode, fixed in wcb_probe 7, hardened in WCB `setup()` (`clearStaleGpioInterrupts`), and the harness now re-binds after any probe restart (a dropped-and-reopened port included) and fails the test in which an unplanned one happens; a review pass made the forget selective and the end-of-test incident `RESET` the probe, so probe and host never disagree on which headers are held. ESP32, S3 and probe compile; `selftest.py` 39/39. Nothing flashed. |
| 2026-09-23 | #78 CONFIRMED and fixed (FIXED, unverified; compiled, not flashed). `softrx.erratum_pairs` on W1 (run 20260923-113109): 227 of 10125 two/three-port lines lost at -1.5 to -3 µs skew, all 10125 single-port lines exact; every attributable one-byte corruption is exactly one lost edge. Fix: EspSoftwareSerial 8.1.0 vendored at `Code/WCB/src/EspSoftwareSerial` with level-triggered, polarity-flipping RX on the classic ESP32 (S3 untouched), PWM input ISRs converted the same way, CI no longer installs the library, `?DEBUG` reports each soft port's RX mode. New test `softrx.level_irq_stuck_line`; `input.softserial_tx_rmt` asserts the RX mode. ESP32 69 % / S3 67 %, ISRs in IRAM, no stock library in the build. Next: flash W1/W2, run `softrx.*` and `input.softserial_tx_rmt`, then the soft-port and PWM suites. |
| 2026-09-23 | Targeted run 20260923-095057 on the 09:49 images (#47, #73 D4-D9, probe 4): **139/140**. The one failure, `kyber.local_port_move_releases_old` step (e), was not the Kyber change: every probe channel re-bind pulled the WCB's RX line low, W1 read a NUL at the front of the next line, and its parser broadcast that line as an EMPTY command (a lone CR on S4) and lost it. Fixed on both sides (#79): wcb_probe 5 holds a re-bound channel's TX high, and the WCB line reader drops NUL bytes. New (should) test `input.nul_ignored` failed on the 09:49 image as predicted; with probe 5 and the new image `input.*` is 50/50 (3 known WDP-DA label skips) and the Kyber test passes (20260923-111854). #47 and #73 D4-D9 VERIFIED. |
| 2026-09-23 | #78 measurement built (harness only; not run, nothing flashed): probe verb `TXSKEW` (wcb_probe 4, compiled) sets a sub-microsecond skew between up to three bit-banged lines, and new opt-in suite s23 has `softrx.erratum_pairs` (does W1 lose soft-port input to GPIO-3.14? pairs and triples at a swept skew against single-port controls) and `soak.w1s4_wire` (the W1S4 episode: hardware vs soft receiver, S4 alone vs with S2, crosstalk into idle S4). The level-triggered EspSoftwareSerial fix waits for a "confirmed". To run: flash probe1, add `softrx_erratum` / `w1s4_soak` to `opt_in`. |
| 2026-09-23 | #47 applied (FIXED, unverified; compiled, not flashed): the cycle guard's never-popped `activeChainKeys` set is replaced by a per-item lineage (seqDepth + key hashes in front of the queued text, restored into `seqCurPath` at drain, pushed in `recallCommandSlot`, carried across `;t` by `commandGroupsPath`), plus a 16-slot queue reserve for nested expansions. New (should) tests `seq.cycle_guard_reuse` (should fail on the current images: DEPTH HILL8, REFUSE HILL1-3) and `seq.reuse_queue_reserve`; `seq.cycle_guard` unchanged. ESP32 compiles at 69% / 108120 B RAM. Wiki self-loop / state-machine examples rewritten. |
| 2026-09-23 | #73 D4 applied (FIXED, unverified; compiled, not flashed): `kyberModeReservesPort()` - Kyber LOCAL reserves only its own port, REMOTE still S1 - in the HCR/MP3/WLED/DFP guards, `canUsePWMOnPort` and `;P`; the Kyber_Local boot skips the other port's UART when PWM owns it; the targeted Kyber bridge skips a device/PWM-owned port; the Wizard claims only the Kyber port and releases REMOTE's S1 (`KYBER,CLEAR`) before the device lines of a REMOTE -> local push. New (should) tests `kyber.local_free_port_takes_pwm` (should fail at the WLED S2 arm on the current images) and `wizard.kyber_local_frees_other_port` (no board). D4b filed (device guards lack a Maestro term; a skipped PWM mapping comes back). ESP32 compiles at 69%. |
| 2026-09-23 | #73 D5 + D9 applied (FIXED, unverified; compiled, not flashed): one `kyberReleasePort()` for CLEAR, a `?KYBER,LOCAL` port move and `?MAESTRO,REMOTE`; REMOTE zeroes `kyberLocalPort`; the bare `?KYBER,LOCAL` keeps the current port; `?backup` and the Wizard release before BAUD/BCAST (Wizard also re-sends the released port's rows and asks for a reboot on MAESTRO,REMOTE). #28's note on a refused `?MAESTRO` during a restore corrected. New (should) tests `kyber.local_port_move_releases_old` (fails at step b on the current images, before any injection) and `wizard.kyber_release_order` (no board; passes standalone, and failed on the old parser.js - which is how the Wizard tests' persistent Chrome profile was found serving a stale cached parser.js; `openWizard()` now disables the HTTP cache); `kyber.local_rejected_port_keeps_forwarding` compares only the `?KYBER,LOCAL` line. ESP32 compiles at 69%. |
| 2026-09-23 | #73 D6-D8 applied (FIXED, unverified; compiled, not flashed): the legacy S1 Maestro fallbacks skip an owned S1, a local Kyber target follows its Maestro slot (no broadcast skip, by decision), and ?KYBER/?config name the real Kyber port. New (should) tests `kyber.local_s1_legacy_fallback_skips_kyber_port` and `kyber.local_clear_maestro_drops_target` (both should fail on the current images); `kyber.local_mode_s2`'s needle updated. D6b and D7b filed open. ESP32 compiles at 69%. |
| 2026-09-23 | Reconciled: 14 FIXED items promoted to VERIFIED because every named test passes on the current images (runs from 20260922-211114 on): #14, #28, #58, #61-#63, #65-#72. Still open: #47 (cycle guard), #64 (IRAM flag - no test reproduces it; the whole full run ran on the fix), #73 (Kyber D4-D9), #78 (soft RX). Design workflow for #47/#73/#78 running. |
| 2026-09-23 | probe.soft_concurrent_rx residual: a verified diagnosis blamed ESP32 erratum GPIO-3.14 (lost edges, pins 0-31 share one interrupt status register). The rewritten self-check's control arm then caught an INTERMITTENT ~3.5 % W1S4 corruption with only one probe edge pin active (20260923-012123), which rules the erratum out for that episode. Minutes later everything was clean: W1S4 on a hardware UART 500/500, the control repeated 500/500, the full self-check 1000/1000 + 300/300 (20260923-012735). Filed #78 (open: bench check of the W1S4 lead/ground; inferred WCB exposure to the erratum) and corrected #66. |
| 2026-09-23 | **Full run 20260922-215719 (21:01/21:02 images): 401 PASS / 2 FAIL / 4 SKIP in 1:39:11** - skips = 3 WDP-DA label checks (need an unlabelled W1 port) + ota_wrong_chip (opt-out). Both FAILs were NaviCore test bugs (#76). Then: W1/W2 flashed with the #75 heap hardening (23:58); regression 20260922-235913 (172 tests on the changed paths): 2 FAIL - inv.mgmt_seq_remote (lost once-sent SEQ reply, #77) and probe.soft_concurrent_rx (probe instrument, ~0.17% of lines when two soft channels receive at once; diagnosis running). Verification 20260923-002254: 18/18 PASS incl. sbus.trim_exact then the NaviCore readback (#76), mesh_stats_counts, all inv.* (#77), kyber.remote_roundtrip (retried once: try 1 lost one 6-byte frame, #74). #74-#77 VERIFIED. |
| 2026-09-22 | **Rerun 20260922-193306 (69 tests): 64 PASS / 4 FAIL / 1 SKIP** — all 9 input.wdpda_* PASS (session wcb-ce's issue #19). Greg decided #14 (apply) and the #28 follow-up (refuse a local-Maestro port); both applied, and a verified review closed two bypasses (the backup/Wizard target form, a later ?MAESTRO) and the push-order regression (?backup and Wizard now claim KYBER,LOCAL after the Maestros; the Wizard sends KYBER,CLEAR first on a port move and re-sends the released port's BAUD/BCAST). #70 OTA teardown ACK (WCB + NaviCore), #71 seqget retry, #72 host hibernate on critical battery (laptop on battery since 15:59) + awake-time detector, #73 Kyber follow-ups filed, not applied. W1/W2/NaviCore reflashed 21:01; targeted GUI rerun of 62 tests started. |
| 2026-09-22 | **Triage of full run 20260922-151421 applied** (8 diagnoses, all adversarially verified; test rewrites by a per-file workflow, each diff adversarially reviewed). Firmware: #63 soft-port reads suspend the scheduler, #64 GPIO ISR service without ESP_INTR_FLAG_IRAM (crash risk found by two agents, confirmed from the map: __onPinInterrupt is in flash), #58 heap metric MALLOC_CAP_8BIT (explained), #28 reopened and fixed (refusal before any state change); NaviCore #65; probe #66 (wcb_probe 3). Tests #67-#69, plus inv.seqget_largest and kyber.local_port_s1_frees_s2. W1/W2 had been flashed by session wcb-ce at 19:25 from the same tree (it added WDP-DA per-port-and-type, issue #19, and three input.wdpda_* tests); NaviCore and both probes flashed 19:3x. Combined GUI rerun of 69 tests started. Awaiting Greg: #14 (who reads S1/S2 on Kyber_Local boards) and the #28 follow-up (refuse ?KYBER,LOCAL on a local-Maestro port). |
| 2026-09-22 | **Opt-in run 20260922-185238** (Greg enabled ota_erase, ota_full, ota_full_wcb2, nvs_wear, seq_wipe, sbus_reset, navicore_clip): 8 PASS / 2 FAIL / 15 SKIP. The 15 OTA skips were the image lookup (Code/bin only; the bench build keeps the committed version string): _image now prefers results/builds/wcb-esp32-meshq. Opened and fixed #61 (firmware: a rejected re-BEGIN strands USB at 921600) and #62 (test: an RTS-only pulse never reset the SBUS controller on Windows). Both diagnoses adversarially verified. Not yet flashed or rerun. |
| 2026-09-22 | **Full run 20260922-151421 (GUI, post-rewire): 357 PASS / 16 FAIL / 29 SKIP.** 12 of the 16 FAILs are one host event: Windows logged a power-source change at 15:59:03 and slept at 15:59:09; all seven bench ports errored in the same 12 ms; resumed 18:26 (so auth_mismatch_silent 'took' 8841 s). Harness now keeps the PC from idle-sleeping during a run, and reports an all-ports-at-once loss as ERROR 'NOT A RESULT' and waits for the ports (runner.host_usb_loss). Greg's rerun of the 16 (20260922-183613): 15 PASS; navicore.maestro_skip_not_logged_as_dispatch fails consistently (the first run in which it ran at all: every earlier run skipped it with 'NaviCore has no local Maestro slot that answers ?MAE,GET'). Remaining 4 real FAILs + 3 non-opt-in SKIPs under diagnosis (workflow). Skips: 26 of 29 are opt-ins. |
| 2026-09-22 | Greg rewired probe2 (W2S1 tap -> header S2, W2S5 -> header S5); --discover found all 10 wires verified. navicore.plain_broadcast_both_ways + input.bcast_fanout PASS, and every tap-dependent test still PASSes (20260922-150647): #60 VERIFIED. The three timing tests that skipped now wait and PASS on their own (20260922-145506). All three failures of full run 20260922-125537 are resolved. |
| 2026-09-22 | Kyber single-reader fix (#59) + probe hand-off guard (#60). Workflow diagnosis of the last 3 full-run failures, adversarially verified: two firmware (a local Maestro port on a Kyber board read by both the parser and the bridge task; ?KYBER,CLEAR leaving S1 double-read and printing no reboot notice), one harness (probe2 needs 3 hardware channels at once, and LRU eviction silently misattributed bytes). W1+W2 flashed; run 20260922-144915: every kyber.* and maestro.* PASS except two SKIPs (local_port_s3_frees_s2 by design; wdp_auto_remote_revert timing, being changed to wait). plain_broadcast_both_ways + bcast_fanout now fail with the guard's rewire message. |
| 2026-09-22 | Tracker reconciled against the bench: every FIXED item whose named tests all PASS in full run 20260922-125537 or a later rerun is now VERIFIED (47 promoted). Totals: 52 VERIFIED, 1 FIXED (#28 - its test skips by design since ?KYBER,LOCAL,S3 is refused), 2 DEFERRED (#14, #47), 2 OBSOLETE (#33, #55 - bit-banged TX is gone), 1 OPEN (#58). |
| 2026-09-22 | #52 decided (Greg): Maestro get with no slot unicasts to WCB<dev> within WCBQ, like the other two fallbacks. Both targets compile (69% / S3 67%), W1+W2 flashed. Maestro+Kyber suites 20 PASS / 12 SKIP (skips = bench wiring), NaviCore-hosted Maestro inventory PASS. |
| 2026-09-22 | **Full run 20260922-125537: 347 PASS / 3 FAIL / 52 SKIP, 0 serial events** (best yet; every NaviCore test passed). input.bcast_out_block = W1 S4 config drift from the aborted run (and a double-click-queued rerun, closed 1 s after starting, re-left S4 OUT OFF) - restored W1 to baseline, test PASS x2. maestro.list_and_legacy_spellings = relayed {"sys":1} rc_ch line inside ?KYBER,LIST output - WCB.run() now filters sys lines, PASS x2. maestro.get_fallback_unicast_within_wcbq = #52, still DEFERRED (needs Greg's call). |
| 2026-09-22 | GUI: dark theme by default (--light restores the bright one; palettes at the top of gui.py, DWM dark title bar) and a guard so a double-click during a run no longer queues a second run / clears results. Full run 20260922-125139 was aborted after 6 failures that were all one loose wire (W1S2 -> probe1 S4, knocked out during the unplug); rediscovered and restarted as 20260922-125537. |
| 2026-09-22 | NaviCore USB output stall: HWCDC (esp32 3.3.4) drops to 'disconnected' after one 50 ms TX stall and only host INPUT reconnects it - replies arrived a command late (~2 % of back-to-back commands). NaviCore loop() now kickUsbCdcTx(): txfifo_flush + re-arm IN_EMPTY every 20 ms (0/800 stalls). NaviCore docs ARCHITECTURE/TROUBLESHOOTING updated. navicore.probe_temp_peer_not_learned ran for the first time (index guard) and found WCB_Client marking ANY heartbeat/boot-announce sender online while the offline sweep only covers floor/learned/special - a temporary client stayed 'known' forever (boot half introduced by my #11). Both handlers now gate on tracked senders; both WCB_Client copies identical; README 1.17.1 changelog. Test PASS. Two navicore tests (mesh_json_declined lost-output, mesh_stats_counts extra send) fail only on a SECOND consecutive navicore+sbus run; pass 4/4 alone and after sbus.* - open. |
| 2026-09-22 | Bench contention: 4 orphaned headless Edge instances (from 2026-09-20) killed; sessions wcb-4f/-cf/-b7 asked to stay off the ports (all acked, none had touched them today). Real cause of the SBUS hang: bench.json sbus had been changed to COM19 (Bluetooth SPP) at 09:11 - likely the GUI port dropdown (lists all ports, wheel-scroll saves); restored COM4, dropdowns now USB-only / read-only / wheel-off. Own regression caught: setting write_timeout per send re-ran pyserial's SetCommState under the reader and delayed GET_CONFIG ~10 s on NaviCore - now set once at open (GET_CONFIG 10/10 in 0.1 s). sbus.* 9 PASS / 2 expected SKIP, twice. |
| 2026-09-22 | Harness: SBUS rerun hung 10 min holding COM4 - its second ping's write() blocked forever (no write_timeout) while the controller was not draining its USB endpoint; a concurrent wizard.* run from another session was also on the bench. hil/serialdev.py now bounds every write (raises ExpectTimeout) and reopens a vanished port from the reader thread (the cause of the 8 sbus.* ERRORs in 20260921-143814). Verified offline against a fake pyserial: drop->reopen after 2 failed opens, send after reopen, stalled write fails in 0.1 s, close stops the reader. |
| 2026-09-22 | Full run 20260921-143814 on the RMT image: 332 PASS / 9 FAIL / 8 ERROR, all classified - 8 sbus.* ERROR = the SBUS board's USB dropped mid-run and the harness never reopens a vanished port (not firmware); navicore x2 late replies; 3 pwm tests asserted bit-bang quirks (first ;P invisible; ;S bytes onto a live PWM output) - updated; inv.seqget_toobig opened #58; soft_rx 1 byte/~1000 lines once (3/3 clean after). Reflashed W1/W2 (the bench had gone offline mid-flash). Rerun 20260922-085933: 11 PASS + 1 expected skip, incl. every RMT test, the updated pwm tests, rejoin_seq_reuse and both navicore. **ESP32-S3 (WCB 3.2 / SBUS board) RMT check**: full 16 MB flash backed up, probe flashed: GPIO ISR L3 ESP_OK; S3/S4/S5 all rmt=yes alongside the NeoPixel (the whole 4-channel budget); 100-byte writes 104.7 ms @9600 (104.2 theoretical), 9.2 ms @115200 (8.7 - chunk gaps, 9 bytes/chunk on the S3's 48-word channels), 417.4 ms @2400; LED updated after. Backup written back, SBUS answers fwver 20260811-fae0af6. |
| 2026-09-21 | **Option 4 (Greg): S3-S5 TX on RMT.** New WcbSoftSerial (subclass of the library: RX stays EspSoftwareSerial, write() goes to an RMT channel via a simple encoder, 10 MHz >= 4800 baud / 1 MHz below, chunked to fit channel memory so the non-IRAM refill ISR is never needed mid-frame, falls back to bit-bang if no channel). ;P reclaims the pin via rmt_tx_switch_gpio. Results: soft_rx_under_soft_tx PASS, baud_on_raw_mapped_port PASS, core0_contention PASS, tx_integrity 200/200 on every arm incl. the old unprotected port (was 60-73/200). Then GPIO ISR service at level 3 (setup, before any attachInterrupt): soft_rx_baud_sweep 19200/38400/57600 20/20 x3 (was 15-19). ?BAUD S3-S5 now warns only above 57600. Tests rewritten: input.softserial_inttx_state -> input.softserial_tx_rmt; hcr.softserial_integrity_mesh_load and input.softserial_tx_integrity assert RMT (all arms). CLAUDE.md rule 13 rewritten. Both targets compile (69% / S3 67%). Full run 20260921-143814 started. |
| 2026-09-21 | **#57 fixed**: UART0 driver installed from a core-0 task (beginUsbSerialOnCore0). A/B on W1: protected S3 mangled USB lines in ~half of runs; unprotected 0/6 (but 0/10 S3 blocks); protected + core-0 ISR 0/8 and 8/8 PASS. ?STATS prints serialRxOverflows when non-zero. Both targets compile (69% / S3 67%); W1+W2 flashed. Regression run 20260921-121337 (input/ota/chars/map/wcb, GUI): 94 PASS, 3 known #16 fails, plus input.softserial_tx_integrity 1/200 wrong once (S3 output burst mis-framed, the #55 residual) - then 3/3 PASS, 1200/1200 protected lines exact. CLAUDE.md rule 13 records the core-0 constraint. |
| 2026-09-21 | Rerun 20260921-115338: chars.funcchar_change_restore + if.stored_seq_recall_time PASS. input.softserial_core0_contention reproduces (3 of 4 runs, GUI and CLI): opened **#57** - a USB command arriving during a mesh raw block to protected S3 loses its ';' ('7S4,…'/'784,…') and is broadcast; mechanism not proven, next steps listed there. |
| 2026-09-21 | **Full run 20260921-105657 (GUI): 6 FAIL / 341 PASS / 51 SKIP** (morning: 27 FAIL). Known: input.soft_rx_under_soft_tx + map.baud_on_raw_mapped_port (#16), maestro.get_fallback_unicast_within_wcbq (#52). New: chars.funcchar_change_restore - my shared prefixCharOk validator reworded the collision refusal; original wording restored ('— … Pick a different function identifier.'), compiled. if.stored_seq_recall_time - harness race (the [IF] true echo printed 93 ms after the command reached S1; test now waits for it). input.softserial_core0_contention - 8/10: R9 two corrupt bytes (#55 residual) and R4 interleaved with a BROADCAST line: W1's USB input received ';S4,HILL12…' as '7S4,…' (0x3B->0x37, one bit), so the line lost its prefix and was broadcast as text to every port. Single occurrence, not reproduced; recorded, no fix. soft_rx_baud_sweep passed this run. Wiki draft (7 pages) done, uncommitted. |
| 2026-09-21 | Decision (Greg): ?BCAST,RESET opens every port, device-owned ones included. Removed the device-port re-block (#41); message now says '(device ports included)'. Reflashed W1/W2; full run 20260921-105657 started in the GUI. hcr.status_reply_parse PASS after its age= wildcard stopped swallowing vage=. |
| 2026-09-21 | Reruns on the final image: CLI 20260921-102109 (63 tests: 61 PASS; only bcast_reset_persists [awaiting decision] and baud_on_raw_mapped_port [#16]) + GUI 20260921-102817 (36 tests: 35 PASS). Every regression fix, #56, #32, all 6 hcr.* test updates, the ota/#L1/maestro/client_mesh/pwm test updates PASS; wcb.mgmt_pull, wdp.controller_auto_enable and dfp.config_frames pass on rerun (one-off misses). Last red: hcr.status_reply_parse - STATUS gained rx=/vage= (other session); test updated, not yet rerun. gui.py gained --run <globs> (opens + auto-starts); run.py forces UTF-8 stdout. |
| 2026-09-21 | Rerun 20260921-100408 crashed on a cp1252 console encode (runner, not a test; rerun with PYTHONIOENCODING=utf-8). Up to the crash: mgmt_pull + map.text_* + clear_all_reaches_remote PASS. Found: #46 CLEAR,ALL never restored OUTPUT (fixed); W1 **S3** flags also left OFF by the 09-21 #46 regression (restored ON/ON - caused bcast_json_local_only + input_port_loses_output + a set_flags skip); pwm.wdp_autoconfig: CLEAR,ALL now clears W2 directly, so the self-heal step accepts either route. WcbCmd.h WCBCMD_VERSION still said 0.8.0 after the 0.9.0 commit - bumped in both copies. Reflashed W1/W2. |
| 2026-09-21 | **Full run 20260921-085938: 27 FAIL / 312 PASS / 59 SKIP** (09-16: 66 fail+error; (should) fails 53 -> 4). Classified all 27. **Firmware:** #56 new (ETM CHAR loop-time broadcasts gated by lastReceivedViaESPNOW), #32 re-fixed (quiet param was never applied). **Tests out of date with deliberate changes:** 6 hcr.* (one-frame poll <QM,QD,QVV,QVA,QVB>, 3 s unseeded retries, STATUS/debug never transmit, volume 0-100 - the other session's HCR/WcbCmd 0.9.0 work), ota.local_parse_help_unknown (#30 hint), navicore.cli_codes (#L1 profile), maestro.get_edge_cases (#29 normalises ',00000000005' to channel 5), client_mesh.adopt_identity_route ('(boot)' since #11), pwm.wdp_autoconfig_and_selfheal (deferred reboot opens a window for W1's PWMTARGET advert - setup now waits + retries). **Already fixed mid-run:** 5 map.* + input.bcast_json_local_only (#46/#37/#50 regressions). **Known/deferred:** soft_rx_under_soft_tx, soft_rx_baud_sweep, map.baud_on_raw_mapped_port (#16), get_fallback_unicast_within_wcbq (#52). **Open:** input.bcast_reset_persists (needs Greg's call), wcb.mgmt_pull + wdp.controller_auto_enable + dfp.config_frames (single misses, rerunning). Reflashed W1/W2, restored W1 S2 BCAST ON/ON. |
| 2026-09-21 | **Bench run on the new images caught three of my own fixes.** #46 (config-corrupting): re-issuing a mapping recorded the mapping's own disabled flags as 'previous', so CLEAR restored OFF and left the port dark - now records only when the slot is first claimed. #37: the separator was added to every remote line, changing wire bytes and spending a CHKSM char - now only when the payload starts with ','. #50 WCB half REVERTED: the WCB already sends target-0 JSON as an untracked ETM frame (bestEffortTelemetry); the double-processing was WCB_Client-only. Open: input.bcast_reset_persists is a design choice (device ports kept blocked vs RESET = all open) - Greg to decide; wcb.mgmt_pull got no reply at t=3.8 s but passed in 4 prior runs and MGMT works later in the same run, so re-run alone before calling it. |
| 2026-09-21 | Worked the whole list. **49 of 55 fixed**, 6 DEFERRED with reasons (#14, #16, #33, #47, #52, #55 - each needs the bench or a decision, see its entry). All three repos compile clean: WCB 69% flash / 106032 B RAM, NaviCore 6% of 16 MB, WcbCmd + WCB_Client via both. **Nothing hardware-verified - the bench was powered down for this session and the previous one.** Cross-repo: WcbCmd (#2, #21) and WCB_Client (#11, #50) are changed in BOTH the canonical repo and the Arduino-Code sketchbook copy; per CLAUDE.md rule 1 push WcbCmd before the firmware, since CI clones it. |
| 2026-09-20 | Third pass: #13 (ETM setters validated in both spellings + load-time clamp) and #18 (token-aware timer-splitter exemption, documented in SEQUENCE_INVENTORY.md). Thirteen defects fixed, all compile clean (68% flash / 106008 B RAM). Bench still powered down all session - nothing hardware-verified. |
| 2026-09-20 | Second pass, bench still offline: fixed #4 (one prefixCharOk validator for all four prefix setters), #5 + #6 (Kyber ids 1-8; port validated before kyberPort/kyberUseTargeting are assigned, REMOTE included), #17 (staged serial mapping + bare ,R refused) and #15 (staged PWM mapping). Eleven defects fixed in total, all compile clean at 68% flash / 106008 B RAM. Still none hardware-verified. |
| 2026-09-20 | Also fixed #1 (DFP port guard, five sites + three missing externs) and updated CLAUDE.md rule 11 to name both deferred-restart flags. Final build: 68% flash / 106008 B RAM, zero warnings. Six defects fixed, none hardware-verified. |
| 2026-09-20 | Fixed #9, #8, #10, #12, #3 — all compile clean (68% flash, 106008 B RAM). **None verified on hardware:** the bench was powered down (all five COM ports FileNotFoundError), so the flash failed silently and a `pwm.*` run errored on port-open. Boards still run pre-session firmware. When the bench is back: flash both from `tests/hil/results/builds/wcb-esp32-meshq`, then run `pwm.*` (#8/#9/#10) and `etm.acked_not_executed_reboot`, `etm.dedup_ring_covers_pending`, `etm.pending_table_evict` (#12/#3). The harness changed with the firmware in three places (`_inline_clear_out`, `clear_out_keeps_queue`, `hil/wcb.py reboot()`), so those fail against old firmware until the boards are flashed. |
| 2026-09-20 | Resumed. Greg had committed the harness plus the half-done #9 (WCB_PWM.{h,cpp} returned bool, but WCB.ino still rebooted inline) as `eb82f29`, and fixed HCR readback/graceful stop in `0fed82b` + `6aeee6a` — recheck #19/#20/#24 against those before touching them. Completed #9. |
| 2026-09-16 | Analysis complete: 57 failures → 55 defects, ranked below. Nothing fixed yet. |

## The list

### High impact (18)

#### 1. A configured DFPlayer's serial port is unprotected — HCR, MP3, WLED, PWM and Kyber will all take it, and both configs then persist

| | |
|---|---|
| **Status** | VERIFIED — conflict.dfp_port_unguarded PASS on the bench (20260922-125537) |
| **Owner** | `WCB_firmware` |
| **Effort** | S |
| **Tests** | `conflict.dfp_port_unguarded` |
| **Subsystem** | devices-hcr-dfp |

**Mechanism.** `isSerialPortUsedForDFP()` is defined at WCB_DFP.cpp:63 and declared at WCB_DFP.h:61, and the runtime paths do use it (`;P` passthrough WCB.ino:6936, broadcast-out skip :7074, `processIncomingSerial` skip :7116). But it appears in NONE of the five config-time port guards: WCB_HCR.cpp:649-652, WCB_MP3.cpp:314-317, WCB_WLED.cpp:326-329, WCB_PWM.cpp:78 (`canUsePWMOnPort`) and WCB_Storage.cpp:1203-1206 (Kyber LOCAL). DFP's own guard (WCB_DFP.cpp:267-271) checks all five of the others, so the asymmetry is entirely one-directional. `hcrReservePort` then calls `saveHCRSettings()` (WCB_HCR.cpp:520) while `dfpConfig` is already saved, so both configs land in NVS and both are emitted into `?backup` (the DFP token is built at WCB_DFP.cpp:367).

**How it is reached.** `?DFP,S4` then `?HCR,PORT,S4:9600` — the second is accepted. Session log 5492.606-5492.792: `[DFP] Configured: S4 at 9600 baud` … `[HCR] Configured on S4 at 9600 baud`, no complaint. Any builder who moves an HCR, MP3 strip, WLED or PWM output onto a port a DFPlayer already occupies (or forgets which port it is on) hits this on the first command.

**Why it matters.** Two drivers end up on one UART, persisted. Both write (HCRVocalizer text frames interleaved with 10-byte DFPlayer frames = garbage to both devices) and both read: `processDFPResponses()` → `dfpCodec.poll()` and `processHCRTick()` → `_hcr->update()` race for the same RX bytes, so ONFIN callbacks and HCR status parsing both break. Worse, the intruder's CLEAR then re-enables broadcast IN and OUT and wipes the label on the still-configured DFPlayer port (log 5493.787: `✓ Re-enabled broadcast output on S4` / `input on S4` / `Serial4 label set to: ''`), leaving the saved config internally inconsistent — and it survives reboot because both halves are in NVS. Recovery is a dead end for the user: `?D …

**Fix.** Add `isSerialPortUsedForDFP(serialPort) ||` to each of the five guards and add DFP to each message string: WCB_HCR.cpp:649-653, WCB_MP3.cpp:314-318, WCB_WLED.cpp:326-330, WCB_PWM.cpp:78-79, WCB_Storage.cpp:1203-1207. The declaration is already in WCB_DFP.h:61; WCB_Storage.cpp externs the peers itself at :28, so add one matching `extern bool isSerialPortUsedForDFP(int port);` there. Five one-line edits plus five string edits.

**Risk.** A board that ALREADY has the overlapping config saved keeps it — these are config-time guards only, and WCB_Storage.cpp:1201-1202 documents that loadKyberSettings() reads NVS directly and never replays the guard. So the change cannot reject an existing saved config at boot and cannot brick a board on upgrade; the overlap just stops being creatable. Watch that `?DFP,S<same port>` re-config still works (the DFP guard deliberately excludes itself — keep that property when mirroring it into the others).

#### 2. A truncated DFPlayer frame swallows the next good one — the ONFIN track-finished callback is lost with no diagnostic

| | |
|---|---|
| **Status** | VERIFIED — dfp.partial_frame_resync PASS on the bench (20260922-125537); shipped in WcbCmd 0.9.1 (`0ab4af5`, 2026-09-25) |
| **Owner** | `WcbCmd` |
| **Effort** | S |
| **Tests** | `dfp.partial_frame_resync` |
| **Subsystem** | devices-hcr-dfp |

**Mechanism.** `DfPlayerCodec::poll()` in WcbCmd/src/WcbDfPlayer.cpp:170-206. The comment at :177-178 states the requirement verbatim — "a partial or corrupt frame must not swallow the next good one (a DFPlayer emits unsolicited init/finish frames at will)" — but the implementation at :179 is `if (_rxLen == 0 && b != 0x7E) continue;`, which only resyncs while the buffer is empty. `_rxLen` is a member (WcbDfPlayer.h:82) that persists across poll() calls with no inter-byte timeout. After a partial `7E 01 02`, `_rxLen` is 3; the next real finish frame's first 7 bytes fill the buffer to 10, `_rx[9]` is 0x05 rather than 0xEF so the frame is dropped at :184, and the finish frame's remaining 3 bytes are then discarded by the resync. Nothing is printed — `[DFP] Track n finished` (:191) never runs, and `onFinished` (:192, wired at WCB_DFP.cpp:47 to `recallCommandSlot`) never fires.

**How it is reached.** A DFPlayer sends init (0x3F) and track-finish (0x3D/0x3C) frames unsolicited, so the WCB is always mid-stream on a line it does not control. One lost or spurious byte — module power-up, a re-plug, a noisy line, or a soft-serial RX drop on S3-S5 under mesh load (CLAUDE.md rule 13; `hcr.softserial_integrity_mesh_load` in this same suite shows real corruption on W2 S5 at 300 frames) — leaves `_rxLen` stuck non-zero forever, because there is no timeout that clears it. Proven directly: probe sends `7E0102` then `7EFF063D000005FEB9EF` (log 5467.605 / 5467.740) and the finish is never reported.

**Why it matters.** Every `;D,PLAY,n,ONFIN,<key>` chain depends on that one frame. When it is eaten, the chained sequence silently never runs — no error, no console line, nothing in `?DFP,LIST`. The builder sees "the sequence sometimes stops after the sound" and goes looking at the sequence, the mesh or the recall key, none of which are at fault. It is also self-perpetuating in the sense that once armed, the parser eats the next frame no matter how long later it arrives.

**Fix.** In WcbCmd/src/WcbDfPlayer.cpp:170-206, validate the fixed header as bytes arrive and re-anchor on 0x7E, so a bad byte cannot hold the buffer hostage: ```cpp if (_rxLen == 0) { if (b != 0x7E) continue; } else if ((_rxLen == 1 && b != 0xFF) || (_rxLen == 2 && b != 0x06)) { _rxLen = 0; if (b != 0x7E) continue; // this byte may itself start the next frame } _rx[_rxLen++] = b; ``` That alone fixes the observed case. Optionally add a stale-partial timeout for the `7E FF 06 <silence>` case: a `uint32_t _lastRxMs` next to `_rxLen` (WcbDfPlayer.h:82) and `if (_rxLen && millis() - _lastRxMs > 200) _rxLen = 0;` at the top of the byte loop. 200 ms is ~20x a 10-byte frame at 9600 baud and far below the gap between unsolicited frames. `Arduino.h` is already included (WcbDfPlayer.h:2). Push WcbCmd to GitHub first, then rebuild the WCB (CI clones the repo — rule 6).

**Risk.** The header check assumes every device→host frame is `7E FF 06 …`, which holds for all four frames the switch at :188-203 handles (0x3C/0x3D/0x3F/0x40) and for the ACK/query replies it already ignores. If some clone module (YX5300/MH2024K) uses a different version byte, its frames would now be dropped instead of parsed — worth a bench check against Greg's actual module before pushing, since the codec explicitly claims clone compatibility (WcbDfPlayer.h:5-6). NaviCore compiles this file but never calls `poll()` (NaviCore.ino:1878 says so explicitly), so its blast radius is WCB-only. `dfp.rx_frames` must stay green — it deliberately feeds a bad-checksum frame and junk (`0011227EFF063C0000050000EF`) and expects it to parse, which the header check still allows since the checksum is never verified.

#### 3. The receiver's duplicate ring (8) is smaller than the sender's pending table (10), so a burst of 9+ ensured commands re-executes on every retry

| | |
|---|---|
| **Status** | VERIFIED — etm.dedup_ring_covers_pending PASS on the bench (20260922-125537) |
| **Owner** | `WCB_firmware` |
| **Effort** | S |
| **Tests** | `etm.dedup_ring_covers_pending` |
| **Subsystem** | etm-mesh |

**Mechanism.** `ETM_PENDING_MAX` is 10 (WCB.ino:541) — ten ensured commands can be in flight at once, each retried up to 3 times reusing its original seq (WCB.ino:1351-1420). The receiver dedups against a per-sender ring of only `ETM_SEQ_HISTORY = 8` (WCB.ino:591-592, checked at WCB.ino:4355-4359, written at 4363-4367). With 9 distinct seqs alive from one sender, pushing the 9th evicts the 1st, so the 1st's retry reads as new and executes again — and since each retry re-inserts its own seq, the ring stays permanently one short and every round re-executes every command. The bench measured exactly that: 8 in flight -> [1,1,1,1,1,1,1,1] (the control passes); 9 in flight -> [4,4,4,4,4,4,4,4,4], i.e. original plus all three retries, nine times over. Nothing in the source ties the two constants together — the ring's comment (WCB.ino:586-590) explains why it is a ring rather than a single slot but never mentions the pending table's depth. Important: this does not need total ACK loss. One lost ACK inside a 9-command burst is enough — all 9 seqs are already in the ring, the oldest has been evicted, and that one command's retry executes a second time.

**How it is reached.** Any '^'-chain or stored sequence with 9 or more steps addressed to one remote board — a `;W2,...^;W2,...` chain from the console or Wizard, a `?SEQ` body that drives a remote board, a Maestro or HCR burst — combined with ordinary RF ACK loss. The duplicate execution is the damage: a `;S2` payload written twice to a Magic Panel, an MP3 retriggered, a Maestro script fired 2-4 times.

**Why it matters.** Corrupts commands in normal use, and does it *because* of the reliability layer — the retry that exists to guarantee one delivery produces several. It is also silent: the sender reports a clean ensured delivery, and the only symptom is a device that did the thing more than once.

**Fix.** Raise `ETM_SEQ_HISTORY` (WCB.ino:591) to 16 and tie it to the sender's depth so this cannot silently reopen: `static const int ETM_SEQ_HISTORY = ETM_PENDING_MAX + 6;` plus `static_assert(ETM_SEQ_HISTORY > ETM_PENDING_MAX, "dedup ring must outlast every retryable in-flight seq")`, with a comment saying why the two are coupled. Cost is 20*16*2 = 640 B of static RAM (up from 320 B), no wire change, no behaviour change below 9 in flight. Durable alternative if Greg wants it: adopt WCB_Client's window instead of a ring — `cmdSeqHigh` (uint16) + `cmdSeqMask` (uint32) per sender (WCB_Client.h:272-277) gives a 32-deep backlog in 6 bytes per peer and is already proven on the other side of the same protocol.

**Risk.** Low. A larger window holds a seq longer, so a genuinely NEW command reusing a seq within 16 (only after the uint16 counter wraps at 65535, or across an unannounced sender restart — defect 1) would be dropped instead of run; the 8-entry ring has the identical exposure, half as wide. Re-run etm.pending_table_evict, which asserts exact retry and failure counts at the 11-in-flight boundary, and the 8-command control inside etm.dedup_ring_covers_pending.

#### 4. ?CMDCHAR, legacy ?CC and legacy ?LF set the prefix characters with none of ?FUNCCHAR's guards — a natural typo (?CMDCHAR,?) kills the whole ';' family and persists to NVS

| | |
|---|---|
| **Status** | VERIFIED — chars.cmdchar_lfi_guard, chars.legacy_lf_guard PASS on the bench (20260922-125537) |
| **Owner** | `WCB_firmware` |
| **Effort** | S |
| **Tests** | `chars.cmdchar_lfi_guard`, `chars.legacy_lf_guard` |
| **Subsystem** | input-chars |

**Mechanism.** ?FUNCCHAR is the only one of the four prefix setters that validates. WCB.ino:5695-5721 rejects a value equal to CommandCharacter (:5702-5707) and rejects control/space characters (:5710-5713). Its three siblings assign blind: * ?CMDCHAR — WCB.ino:5724-5733: `CommandCharacter = args.charAt(0); saveLocalFunctionIdentifierAndCommandCharacter();` with no checks at all. * legacy ?LF<c> — dispatched at WCB.ino:5849-5850 into updateLocalFunctionIdentifier (WCB.ino:6065-6073): `LocalFunctionIdentifier = message.charAt(2)` + save. * legacy ?CC<c> — dispatched at WCB.ino:5854-5855 into updateCommandCharacter (WCB.ino:6075-6083): same shape. All three write NVS, so the state survives reboot. What that state does: handleSingleCommand tests the function identifier FIRST (WCB.ino:4970), then the command character (:4974), then falls through to broadcast (:4979). So `?LF;` (LFI := ';') routes every ';' device command into processLocalCommand's legacy catch-alls, and `?CMDCHAR,?` (CmdChar := '?') leaves nothing matching ';' at all — every `;M1…`, `;L1…`, `;S3…`, `;C<key>` line drops through to processBroadcastCommand and is emitted as plain text out every serial port and over the mesh. The firmware's own help already states the contract the code does not enforce: WCB_Help.cpp:995 "Must not conflict with LocalFunctionIdentifier (?)" for CMDCHAR, and WCB_Help.cpp:970 / :998 advertise the legacy `?LFx` / `?CCx` forms as supported. Run evidence (session.log:82451-82453): `?LF;` → "LocalFunctionIdentifier updated to ';'"; (session.log:83070-83071) `?CMDCHAR,?` → "Command character updated to '?'".

**How it is reached.** ?CMDCHAR and ?FUNCCHAR are documented commands with their own help pages, and the legacy ?LFx/?CCx forms are documented there too. The sharpest path is a plain typo: a user who types `?CMDCHAR,?` meaning "what is my command character?" gets it SET to '?' instead of a help dump — because CMDCHAR is on the dataBearingVerb exemption list (WCB.ino:5010-5011) that deliberately disables the trailing-'?' help shortcut for it. `?CMDCHAR ?` and `?CMDCHAR?` both print help; `?CMDCHAR,?` silently breaks the board. Same for `?LF;` typed by anyone following the legacy-command line in `?FUNCCHAR ?`.

**Why it matters.** Every ';' command on the board stops working, persists across reboot, and there is no error message — under ?CMDCHAR,? the commands are not even rejected, they are broadcast as text to every serial port and every peer, so a droid silently starts spraying `;M11` at its Teeces and Magic Panel instead of moving a servo. Recovery exists (`;FUNCCHAR,?` / `?CMDCHAR,;`) but requires knowing the trick; otherwise it reads as a dead board and ends in ?ERASE,NVS.

**Fix.** Extract the two ?FUNCCHAR guards (WCB.ino:5702-5713) into one validator and run all four entry points through it: `?CMDCHAR` (WCB.ino:5724-5733) must reject `nc == LocalFunctionIdentifier` and `nc <= ' ' || nc == 0x7F`; updateLocalFunctionIdentifier (WCB.ino:6065-6073) and updateCommandCharacter (WCB.ino:6075-6083) must call the same validated setters instead of assigning directly. Keep '?' legal for FUNCCHAR — it is the documented recovery (`?FUNCCHAR,?`, WCB_Help.cpp:963) and does not collide with ';'.

**Risk.** A restore chain sets FUNCCHAR before CMDCHAR (printBackupConfig, WCB.ino:3240-3241), so the new CMDCHAR check validates against the just-applied funcChar — I checked that ordering and it is safe. The one behaviour change is that a board already in the broken state (CmdChar == LFI in NVS) will now refuse the command that would re-create it; that is the point, but a board already stuck there still needs the existing recovery command, so do not also add a guard that rejects the recovery path. Watch that ?CMDCHAR,? now prints a rejection rather than being swallowed.

#### 5. ?KYBER accepts Maestro id 9 and writes it as a real slot, which permanently breaks every ;M9 ("all local Maestros") command and cannot be cleared

| | |
|---|---|
| **Status** | VERIFIED — kyber.target_id9_rejected PASS on the bench (20260922-135805) |
| **Owner** | `WCB_firmware` |
| **Effort** | S |
| **Tests** | `kyber.target_id9_rejected` |
| **Subsystem** | maestro-kyber |

**Mechanism.** `storeKyberSettings` validates Kyber target ids as `maestroID >= 1 && maestroID <= 9` (WCB_Storage.cpp:1319, with the matching diagnostic at :1402-1403) and then writes a full Maestro slot at :1362-1396. `configureMaestro` refuses 9 (WCB_Maestro.cpp:578, "9=all local, 0=all Maestros are reserved"), and so does WDP auto-add (:724). Once an id-9 slot exists, both `;M9<n>` and `;M9,<verb>` match it in the config-matched loop (WCB_Maestro.cpp:107-110 and :304-306) and `return` at :156 / :329 BEFORE the target-9 fan-out branches at :190 and :344 — so the board writes a literal device-9 Pololu frame to one port instead of re-addressing to each local Maestro's own id. Bench evidence: after `?KYBER,REMOTE,S1,M9:W1S1:57600`, `;M95` put `aa 09 27 05` on W1 S1 where `aa 01 27 05` was expected, and `;M9,goHome` put `aa 09 22` instead of `aa 01 22`. Worse, the slot is unremovable: `clearMaestroByID` rejects id 9 on both the bare-id path (WCB_Maestro.cpp:817) and the targeted path (:844), so `?MAESTRO,CLEAR,M9` and `?MAESTRO,CLEAR,M9:W1S1` both refuse. Only `?MAESTRO,CLEAR,ALL` gets rid of it, and that wipes everything.

**How it is reached.** A builder hand-typing a `?KYBER,LOCAL,S2,M9:W1S1:57600` target line, reasonably assuming 9 means 'all local' as it does in every `;M` command and in `?MAESTRO`'s own error text. The Wizard computes Kyber target lines from Maestro rows (see the comment at WCB_Storage.cpp:1325) so it would not emit 9 — this is a hand-typed / pasted-config path.

**Why it matters.** Silently destroys `;M9` board-wide: no local Maestro answers a device-9 frame, so every sequence that uses the 'all local Maestros' target stops actuating anything, with no error anywhere. And the user cannot undo it without wiping the whole Maestro map.

**Fix.** WCB_Storage.cpp:1319 — change `maestroID <= 9` to `maestroID <= 8`, and update the skip message at :1402-1403 to say 1-8. Nothing else creates a target with id 9 (`reconcileKyberTargetsFromMaestroConfigs` :1101 and the auto-populate at :1177-1189 both copy from `maestroConfigs[]`, which is already 1-8), so the narrowing is safe. Optional follow-up for the same root cause: have `storeKyberSettings` route its slot writes through `configureMaestro`'s validation instead of duplicating it.

**Risk.** Any existing board already carrying an id-9 slot keeps it — the fix stops new ones but does not clean up old ones, and clearMaestroByID still refuses 9. If you want those recoverable, also relax WCB_Maestro.cpp:817/:844 to allow a CLEAR of an out-of-range id that is actually present (clear-only, never add).

#### 6. A rejected ?KYBER,LOCAL,Sx still switches targeting on in RAM — on a Kyber_Local board that silently drops every sabre byte until reboot

| | |
|---|---|
| **Status** | VERIFIED — kyber.config_negatives PASS on the bench (20260922-135805) |
| **Owner** | `WCB_firmware` |
| **Effort** | S |
| **Tests** | `kyber.config_negatives` |
| **Subsystem** | maestro-kyber |

**Mechanism.** `storeKyberSettings` sets `kyberUseTargeting = true` at WCB_Storage.cpp:1160, inside the params-parsing block, and only afterwards checks the port range at :1166-1169 (`Invalid Kyber port. Must be S1-S5` → `return`). The flag is left true. Bench evidence: after both `?KYBER,LOCAL,S6` and `?KYBER,LOCAL,S0` were refused, `?KYBER,LIST` reported `Targeting mode: Enabled` on a board that had been in broadcast mode. Consequence on a board that actually hosts the Kyber: `forwardDataFromKyber` takes the targeted branch at WCB.ino:4825 and iterates `kyberTargets[]` at :4837 — which the rejected command never populated (the auto-populate at WCB_Storage.cpp:1172-1196 sits after the `return`) — so every byte is read at :4823 and written nowhere. The sabre bridge goes dead with no message. The sibling test kyber.local_rejected_port_keeps_forwarding was written for exactly this and SKIPped this run (bench wiring), so that half is confirmed in source only. It is also not merely 'until reboot': `saveKyberTargets()` persists the flag (WCB_Storage.cpp:2168), and it is called from the end of any later successful `?KYBER` (:1518) and from WDP auto-add on a Kyber_Local board (WCB_WDP.cpp:718-720) — either can make the leaked true permanent.

**How it is reached.** A typo (`S6`, `S0`) or a stale pasted config line while setting up the Kyber port. On a Maestro_Remote board it is invisible except in `?KYBER,LIST` (it is not in `?backup`); on the board that actually has the sabre it kills the bridge.

**Why it matters.** A refused command changes live behaviour, and on the Kyber host it silently stops forwarding the sabre stream while the board reports itself as configured — the 'reports success for something that did not happen' category, inverted.

**Fix.** WCB_Storage.cpp:1150-1169 — parse into locals (`int wantPort; bool wantTargeting = true;`), run the port-range check against `wantPort`, and only assign `kyberPort` / `kyberUseTargeting` after every validation has passed. While there, apply the range check to the REMOTE branch too — :1166 is gated on `baseCommand.equals("local")`, so `?KYBER,REMOTE,S9,...` skips it entirely.

**Risk.** Low. The one thing to preserve is the no-comma path at :1132-1143, which deliberately sets `kyberUseTargeting = false` + `kyberPort = 2` for bare `?KYBER,LOCAL` / `?KYBER,REMOTE` — keep that branch's assignments unconditional.

#### 7. NaviCore's WCB_SEND answers ok:true even when the WCB_Client library refused to send anything

| | |
|---|---|
| **Status** | VERIFIED — navicore.wcb_send_ack_reflects_refusal PASS on the bench (20260922-125537) |
| **Owner** | `NaviCore` |
| **Effort** | S |
| **Tests** | `navicore.wcb_send_ack_reflects_refusal` |
| **Subsystem** | navicore-ota |

**Mechanism.** The direct-USB WCB_SEND handler calls the library and throws away its bool: NaviCore.ino:4036 `wcb->broadcast(cmd);` and NaviCore.ino:4039 `wcb->send((uint8_t)target, cmd);`, each followed unconditionally by `Serial.println("{\"type\":\"ACK\",\"ok\":true}")`. Both library calls return bool and have several real false paths: WCB_Client.cpp:388-393 refuses an over-length BROADCAST outright (fragmentation is unicast-only); WCB_Client.cpp:449/452/460 refuse a fragmented unicast that is too long, that hits an already-in-flight frag job, or that cannot malloc; WCB_Client.cpp:2277 returns false when the ETM pending table is saturated; and _transmit (WCB_Client.cpp:2311 `return esp_now_send(...) == ESP_OK`) returns false whenever the target MAC is not a registered ESP-NOW peer. That last one is the quiet killer: _registerPeers (WCB_Client.cpp:1628-1637) only registers ids 1.._quantity, plus learned and special peers — a valid-looking id above quantity that has never been learned is simply not a peer, esp_now_send returns ESP_ERR_ESPNOW_NOT_FOUND, nothing goes on the air, and NOTHING is printed. The session log (results/20260916-122250/session.log:93963-93964) shows the contradiction directly: `[WCB_Client] broadcast: command too long (188 > 187 chars)` immediately followed by `{"type":"ACK","ok":true}`. The bridged twin has the same hole — rc_telemetry.h:1521-1522 discards the return of broadcast()/send() and sets `ok = true` at :1523 — although it does at least validate the target range and empty cmd first, which the USB branch does not (NaviCore.ino:4031 takes `hdr["cmd"] | ""` and never checks for empty).

**How it is reached.** Config tool → WCB Send panel (config_tool/index.html:18651-18657), described in its own comment as the bring-up test path. It validates only 0-20, not against the configured quantity, so sending to a board id above quantity that has not been learned this boot is a normal typo/bring-up mistake: the command never leaves the board, no diagnostic is printed, and the terminal shows ok:true. Also hit by the ETM pending-saturation path under a burst, by a second long unicast issued while a fragmented send is still in flight (~0.5 s window, WCB_Client.cpp:452), and by any scripted/JSON client. The specific 188-char case the test uses is NOT reachable from the shipped UI — qs-cmd carries maxlength="6 …

**Why it matters.** It reports success for something that did not happen, and in the unregistered-peer case it does so with zero other output — the board is silent, the ACK says ok, and the operator goes off hunting the far end (wiring, power, the WCB's own config) for a command that never reached the radio. That is the exact 'silently reports success' bucket. Tempered honestly: the shipped tool does not display the ACK today, so the current visible cost is to the raw terminal, scripted clients and the HIL harness rather than to a GUI badge.

**Fix.** NaviCore.ino:4034-4042 — capture the bool and report it: `bool sent = (target == 0) ? wcb->broadcast(cmd) : wcb->send((uint8_t)target, cmd);` then `Serial.printf("{\"type\":\"ACK\",\"ok\":%s}\n", sent ? "true" : "false");`. Add the empty-cmd guard the bridged path already has (`if (!cmd[0]) → ok:false`) so the two transports agree. Apply the identical change at rc_telemetry.h:1521-1523: `ok = (to == 0) ? wcb->broadcast(_pendingWcbSendCmd) : wcb->send(to, _pendingWcbSendCmd);`. Keep the SUCCESS ACK byte-identical to `{"type":"ACK","ok":true}` — do not add a msg field to it. Optionally add a msg only on the false branch.

**Risk.** Two things to watch. (a) ok:false does not always mean 'nothing went out': WCB_Client.cpp:2270-2278 transmits best-effort and THEN returns false on pending-table saturation, so a client that auto-retries on ok:false can double-fire a command. Do not add retry-on-false to the tool without also distinguishing 'refused' from 'sent unguaranteed'. (b) Several passing HIL tests pin the success ACK as an exact string (s21_navicore_sbus.py:358, 374, 410, 434, 777) — any change to the true-branch text breaks them, so change only the false branch's content.

#### 8. ?MAP,PWM,CLEAR,ALL's remote commands are sent non-ETM and every ETM board silently drops them — the user is told it worked

| | |
|---|---|
| **Status** | VERIFIED — pwm.clear_all_reaches_remote PASS on the bench (20260922-125537) |
| **Owner** | `WCB_firmware` |
| **Effort** | S |
| **Tests** | `pwm.clear_all_reaches_remote` |
| **Subsystem** | pwm |

**Mechanism.** WCB_PWM.cpp:9 re-declares the shared sender as `extern void sendESPNowMessage(uint8_t target, const char *message, bool useETM = false)` — but the real declaration, WCB.ino:977, defaults useETM to **true**. A default argument is per-translation-unit, so the two 2-argument calls inside clearAllPWMMappings — `sendESPNowMessage(wcb, remoteCmd)` at WCB_PWM.cpp:495 (the `?PX<n>`) and `sendESPNowMessage(wcb, "?REBOOT")` at :506 — go out as plain 249-byte packets. WCB.ino:4203-4225 drops any non-ETM packet on an ETM-enabled receiver unless it is raw serial, `;P`, `;M` or `{`-JSON; `?PX3` and `?REBOOT` match none of those, so the receiver never sees them. W1 nonetheless prints "All PWM mappings cleared" (WCB_PWM.cpp:523). WCB_PWM.cpp is the ONLY file with the divergent default — WCB_Maestro.cpp:24 and WCB_WLED.cpp:26 both use `= true`. Secondary: :494 and :506 hardcode the literal `'?'` while every other remote PWM command in the same file builds the prefix from LocalFunctionIdentifier (:319, :336, :367).

**How it is reached.** Any ETM-on fleet — which is effectively all of them, since CLAUDE.md rule 4 says WDP does not work with ETM off. Make a mesh PWM mapping (`?MAP,PWM,S3,W2S3`), then `?MAP,PWM,CLEAR,ALL` from the Wizard or a terminal. session.log:31224-32396 shows it exactly: at 4819.692 W1 prints "All PWM mappings cleared", W2 prints nothing at all, and 24 s later W2's ?backup still carries `?MAP,PWM,OUT,S3`.

**Why it matters.** Silent success for something that did not happen, and the leftover is permanent. The remote port stays reserved: broadcasts are skipped on it (WCB.ino:7043) and its UART is never begun at boot (WCB.ino:8083-8113), so the device wired there is dead. Because addPWMMapping declared the port with an explicit command, the slot is tagged manual (pwmOutputAutoSrc = 0, WCB_PWM.cpp:833), and reconcileWdpAutoPWMOutputs (WCB_PWM.cpp:842-865) only ever clears WDP-tagged ports — so self-heal will never recover it. Only a hand-typed `;W<n>,?MAP,PWM,CLEAR,OUT,S<p>` fixes it, and nothing tells the user it is needed.

**Fix.** Pass `true` explicitly at WCB_PWM.cpp:495 and :506, and delete the divergent default on WCB_PWM.cpp:9 — either match WCB.ino:977 (`= true`) or drop the default entirely so every call site in this file is explicit (:745 already passes `false` for the ;P hot path, so nothing else changes). While there, replace the `"?PX%d"` at :494 with `"%cMAP,PWM,CLEAR,OUT,S%d"` + LocalFunctionIdentifier so it matches :319/:336/:367 and does not depend on the legacy ?PX alias.

**Risk.** `?REBOOT` becomes an ACKed ETM command, so per CLAUDE.md rule 2 it now occupies a pending-ACK slot per board and retries up to 3x — send it AFTER the CLEAR,OUTs land, and note it becomes redundant once D2 is fixed (the receiver will restart itself via pwmRebootPending). This fix is also what makes D2's queue behaviour reachable: today the remote gets neither command, so fix D2 in the same change or the ?REBOOT and the second CLEAR,OUT will race.

#### 9. ?MAP,PWM,CLEAR,OUT and ?PX restart the board inline and unconditionally, destroying every command queued behind them — including the sibling CLEAR,OUT a multi-output mapping sends

| | |
|---|---|
| **Status** | VERIFIED — pwm.clear_out_keeps_queue, pwm.remove_clears_all_remote_outputs PASS on the bench (20260922-125537) |
| **Owner** | `WCB_firmware` |
| **Effort** | S |
| **Tests** | `pwm.clear_out_keeps_queue`, `pwm.remove_clears_all_remote_outputs` |
| **Subsystem** | pwm |

**Mechanism.** Two handlers still take the restart inside the command handler that CLAUDE.md rule 11 forbids: WCB.ino:5137-5140 (`?MAP,PWM,CLEAR,OUT,S<n>` → removePWMOutputPort, then `Serial.println("Rebooting in 3 seconds…"); delay(3000); ESP.restart();`) and WCB.ino:5941-5944 (the `?PX<n>` alias, identical). Neither checks whether anything was actually removed — removePWMOutputPort is void and just prints "Serial%d was not configured as PWM output" (WCB_PWM.cpp:892) on a miss. Every other PWM path was already converted to the deferred `pwmRebootPending` flag honoured in loop() (WCB_PWM.cpp:313-315, :384-386, :528-531 → WCB.ino:8385-8392); these two were missed. The cross-board case: removePWMMapping ETM-sends one `?MAP,PWM,CLEAR,OUT,S<p>` per remote output back to back with no delay (WCB_PWM.cpp:362-375 — note addPWMMapping's equivalent loop at :337 does have a `delay(50)`); the receiver ACKs each, but the first one's inline restart kills the rest.

**How it is reached.** Local: any chained restore or config push containing the token — session.log 4578.999 `?MAP,PWM,CLEAR,OUT,S4^;S0,HILC866D8` printed "Serial4 was not configured as PWM output" and rebooted anyway, and the chained `;S0` never ran; `?PX4` at 4588.516 did the same. Cross-board: `?MAP,PWM,CLEAR,S3` for a mapping with two remote outputs — session.log 4906.795 shows W2 clearing S3 and rebooting, and S4 never being touched, leaving `?MAP,PWM,OUT,S4` on W2 permanently (manual tag, so no WDP self-heal). The Wizard hits the same thing: app.js:4119-4157 sends one CLEAR,OUT per removed remote destination in a tight await loop.

**Why it matters.** Loses commands in normal use with no error anywhere. The sender sees an ETM ACK (the receiver ACKs before running the command) and the boot banner satisfies the pusher's "did the board answer" test, so the push is scored fully delivered — exactly the failure mode the pwmRebootPending comment at WCB_PWM.cpp:306-312 was written to prevent. It also reboots a board for a no-op, which in a config-push stream costs a reboot plus everything behind it.

**Fix.** Make `removePWMOutputPort` return bool (true when a port was actually removed) — WCB_PWM.cpp:868-893, returning true before the `return` at :889 and false at :893. Then at WCB.ino:5137-5140 and :5941-5944 replace the inline restart with `if (removePWMOutputPort(port)) { pwmRebootPending = true; Serial.println("PWM output cleared — rebooting once the command queue drains."); }`. That single change fixes both tests: the no-op case stops rebooting, and the multi-output case lets the second CLEAR,OUT drain before loop() takes the restart. Optionally also add a `delay(50)` between the sends at WCB_PWM.cpp:369 to match addPWMMapping:338.

**Risk.** Callers that relied on the restart happening within 3 s now wait for PWM_REBOOT_QUIET_MS = 4000 ms of queue quiet (WCB.ino:968, :8386) — the Wizard's `setTimeout(() => boardPull(removedSlot), 10000)` at app.js:4152 still covers that, but re-check the HIL helpers `_inline_clear_out` and `_w2_reboot_wait` (tests/hil/suites/s14_pwm.py:35-49), which expect the literal "Rebooting in 3 seconds" / an ONLINE(boot) inside 40 s. Also confirm removePWMOutputPort's two other callers (removePWMMapping:364 and reconcileWdpAutoPWMOutputs:860) ignore the new return value — the self-heal path must keep NOT rebooting (WCB_PWM.cpp:758-760).

#### 10. ;P has no Maestro-port guard, so a PWM stream aimed at a board's Maestro port silently kills that Maestro until reboot while ;M keeps reporting success

| | |
|---|---|
| **Status** | VERIFIED — pwm.p_refused_on_maestro_port PASS on the bench (20260922-125537) |
| **Owner** | `WCB_firmware` |
| **Effort** | S |
| **Tests** | `pwm.p_refused_on_maestro_port` |
| **Subsystem** | pwm |

**Mechanism.** processPWMOutput's owned-port guard (WCB.ino:6936-6942) covers MP3, DFP, HCR, WLED, raw-mapped ports and `Kyber_Local && port == kyberLocalPort` — but has no term for a Maestro port and no term for `Maestro_Remote` on S1. Execution falls through to the unconditional `pinMode(txPin, OUTPUT)` at WCB.ino:6954, which detaches the UART peripheral from that pin. canUsePWMOnPort (WCB_PWM.cpp:62-84), which DOES reject S1 under Kyber_Local/Maestro_Remote, is never called on the ;P path. There is no isSerialPortUsedForMaestro() helper anywhere (WCB_Maestro.h has none) — but the exact loop needed already exists inline at WCB.ino:7049-7056 in the broadcast path.

**How it is reached.** Two ways, and the second needs no typo. (a) Type `;P1<width>` on a board with a local Maestro on S1 — session.log 4503.567: after `;P11500`, the next `;M11` still prints "→ Maestro 1: Local S1, Script 1" but the probe sees no `AA012701` frame at all; the port stays dead until the reboot at 4505.635. (b) Map PWM at a remote board's Maestro port, e.g. `?MAP,PWM,S3,W2S1` — the Wizard's destination port dropdown offers a plain S1..S5 for any board (Wizard/app.js:4014-4017). W2 refuses the *declaration* (canUsePWMOnPort prints the refusal), but processPWMPassthrough sends `;P1<width>` to the target regardless of whether the declaration was accepted (WCB_PWM.cpp:743-745 has no such check), so the  …

**Why it matters.** Bricks a port until reboot AND reports success for something that did not happen: the ;M dispatcher matches, prints its routing line, and writes into a detached UART. A builder debugging "my dome Maestro stopped responding" has no signal at all pointing at PWM — the same class of failure CLAUDE.md rule 12 describes. The remote-mapping path (b) makes it recur on every boot, so it presents as intermittent hardware.

**Fix.** Add a Maestro term to the guard at WCB.ino:6936-6938, mirroring the loop already at WCB.ino:7049-7056: `bool isMaestroPort = false; for (int m = 0; m < MAX_MAESTROS_PER_WCB; m++) if (maestroConfigs[m].configured && maestroConfigs[m].serialPort == port) { isMaestroPort = true; break; }` and OR it in together with `(Maestro_Remote && port == 1)`. Keep the print gated on debugPWMPassthrough exactly as the existing branch is (:6939-6940) — this runs at passthrough rates. Better still, factor that loop into `bool isSerialPortUsedForMaestro(int port)` in WCB_Maestro.cpp, use it from BOTH WCB.ino:7049 and here, and add it to canUsePWMOnPort (WCB_PWM.cpp:78) so a Maestro on S3/S4/S5 also refuses the declaration.

**Risk.** The Maestro slot table holds remote proxies with serialPort == 0 (WCB_Maestro.h:48-52), so match on `serialPort == port` only — a `port` of 0 cannot reach here (WCB.ino:6921 rejects port < 1). Do NOT convert the guard into a call to canUsePWMOnPort: that function prints ungated (WCB_PWM.cpp:65, :71, :79) and would flood UART0 at passthrough rates. Also preserve the deliberate design recorded in the comment at WCB.ino:6931-6935 — the guard must keep blocking only OWNED ports and must never require a positive PWM declaration, or every remote-driven output stops working (pwm.p_forwarded_stats and pwm.passthrough_mesh would regress).

#### 11. A WCB_Client host that reboots has its first commands ACKed and silently thrown away as duplicates [owner: WCBClient repo]

| | |
|---|---|
| **Status** | VERIFIED — client_mesh.rejoin_seq_reuse PASS on the bench (20260922-125537); the residual race below VERIFIED 2026-10-07 (client_mesh.rejoin_unadopted) |
| **Owner** | `unclear` |
| **Effort** | M |
| **Tests** | `client_mesh.rejoin_seq_reuse` |
| **Subsystem** | etm-mesh |

**Mechanism.** OWNER IS THE WCBClient REPO (C:/Users/ghulette/Documents/GitHub/WCBClient/src/WCB_Client.cpp) — the schema's owner enum has no value for it. WCB_Client restarts its command sequence counter at every begin(): `_seqCounter = 0` (WCB_Client.cpp:77), first command therefore seq 1 (WCB_Client.cpp:2183-2184, declared WCB_Client.h:1089). The WCB keeps an 8-entry per-sender ring of recently-seen seqs (WCB.ino:591-592) and clears a sender's ring in exactly ONE place: on receipt of a PACKET_TYPE_ETM_BOOT announce (WCB.ino:4301-4305). WCB_Client defines that packet type (WCB_Client.h:52) and DECODES it from WCBs (WCB_Client.cpp:2704) but never sends one — grep for WCB_PACKET_ETM_BOOT in WCB_Client.cpp returns only the receive case. So after a client reboot its reused low seqs match stale ring entries, and WCB.ino:4369-4376 ACKs them and returns without executing ('Duplicate seq %d ... ACKd but not executed'). The ACK at WCB.ino:4348-4349 fires BEFORE the dup check, so the client's pending slot completes and it reports success. The loss window is arithmetic: the ring holds the last 8 seqs from that sender, {N-7..N}. A new session's seqs 1..8 collide iff N <= 15 — i.e. when the PREVIOUS session sent 15 or fewer commands to THAT board. Because it is per-sender per-receiver, a host that spreads 40 commands over 3 WCBs still leaves each board's ring in the bite zone. Log proof (results/20260916-122250/session.log:88187+): session A sends 3 MSENDs, all three land on probe1 (t=6395.809, 6396.496, 6397.121). Probe reboots and rejoins as the same id 18. Session B sends 4; the probe prints 'OK MSEND 1' for all four, and only the 4th (B3) reaches probe1 at t=6405.684. Three commands ACKed, zero executed.

**How it is reached.** Every time a WCB_Client host restarts while the WCBs stay up: re-flashing NaviCore, power-cycling it, a crash, MgmtRelay rebooting, SBUSController. Greg hits this on the bench constantly. The user sees 'the first couple of things I do after a reboot just don't happen, then it starts working' — and nothing anywhere logs a failure.

**Why it matters.** Loses commands in normal use AND reports success for them. It is self-healing after a few commands, which is worse than a hard failure: it trains the user to distrust the mesh generally instead of pointing at a cause. The design intent is unambiguous — the WCB's ring-clear-on-boot-announce exists precisely for this case (WCB.ino:4295-4300 spells out the scenario), the client's own receive-side window has the mirror clear (WCB_Client.h:277 seqResetMs), and only the client's SEND side was never wired up.

**Fix.** In the WCBClient repo: add `_sendBootAnnounce()` as a copy of `_sendHeartbeat()` (WCB_Client.cpp:1800-1815) with `structPacketType = WCB_PACKET_ETM_BOOT` and `structSequenceNumber = 0`, and send it redundantly in the first seconds after begin() — mirror the firmware exactly: 3 announces ~1200 ms apart (WCB.ino:1096-1105, `etmBootAnnouncesLeft` / 1200 ms; broadcast is unacknowledged, which is why it is sent more than once). Drive it from update() with a counter+deadline pair like the firmware's, not from begin(), so it does not block the join. Belt-and-braces second half: seed `_seqCounter` from `esp_random()` at WCB_Client.cpp:77 instead of 0 (keeping the skip-0 rule at 2183-2184) so a host whose announce is lost still misses the stale ring by ~65535/8. Do NOT try to fix this on the WCB side — the failing case leaves the peer continuously registered (the probe rejoined inside the 50 s temporary-peer TTL, so addTemporaryPeer's `!esp_now_is_peer_exist` branch at WCB.ino:7741 never re-runs), and WDP carries no boot or session counter, so the firmware has no signal to clear on.

**Risk.** The announce only clears the ring when the WCB already treats the sender as a peer (`wcbPeerActive[senderIdx] || isSpecialPeer`, WCB.ino:4281) — three spaced announces cover the case where the first arrives before the WDP advert is digested; consider also re-announcing once the first WCB heartbeat is heard. A client in a crash loop announcing more often than every 4 s will clear the ring repeatedly, which could let a genuine in-flight retry double-fire — the 4 s hold at WCB.ino:4301 bounds it, and WCBs already carry the identical exposure. Cross-repo release discipline applies: push WCBClient master, sync Arduino-Code/libraries/WCB_Client (it shadows locally), then rebuild NaviCore and tests/hil/wcb_probe.

**The residual race, seen 2026-10-07 (run `20261007-090301`).** The Risk above happened: the probe re-joined as WCB18 and W1 re-adopted it as a temporary peer at its next digested WDP advert, about 3 s after the join, after all three boot announces. The announces were ignored (the ring clear sat inside `wcbPeerActive[senderIdx] || isSpecialPeer`), so session B's seqs 2 and 3 matched session A's and were ACKed and not run (`[1, 0, 0, 1]`); W2, which adopted it in time, printed the `(boot)` line. A command needs no peer status to run, so the ring is now cleared on any sender's boot announce, after the password and the id-to-MAC check (`espNowReceiveCallback`, `WCB.ino`, `77a39d2`). It had passed in the six runs before. `client_mesh.rejoin_unadopted` (`4086299`) forces the race: W1's WDP held off, so it never adopts the client but still ACKs and runs its commands. Session B ran `[0, 0, 0, 1]` on `48da52a` (`20261007-101100`) and `[1, 1, 1, 1]` on `77a39d2` (`20261007-101228`), where `rejoin_seq_reuse` passes too.

#### 12. A remote ?reboot ACKs and then destroys every command queued behind it — the CLAUDE.md rule-11 trap, still live in four places

| | |
|---|---|
| **Status** | VERIFIED — etm.acked_not_executed_reboot PASS on the bench (20260922-125537) |
| **Owner** | `WCB_firmware` |
| **Effort** | M |
| **Tests** | `etm.acked_not_executed_reboot` |
| **Subsystem** | etm-mesh |

**Mechanism.** `reboot()` is `Serial.println(...); delay(2000); ESP.restart();` (WCB.ino:827-831) and is called straight out of the command handler at WCB.ino:5861. An ETM-received command is ACKed on the WiFi task (WCB.ino:4348-4349) and only ENQUEUED for loop() (WCB.ino:4549). `delay()` runs on core 1; `espNowReceiveCallback` runs on the WiFi task on core 0, so during the whole 2 s window the board keeps accepting commands, ACKing them, and recording their seqs in the dedup ring (WCB.ino:4363-4367) — then `ESP.restart()` discards the queue. The sender sees 'Seq N fully acknowledged' and never retries. The test proves both halves: `;W2,?reboot` -> fully acknowledged; 0.3 s later `;W2,;S2<marker>` -> also fully acknowledged, and the marker never appears on W2's S2, while the post-boot control command does. Three more sites take an inline restart from inside a command handler, two of them with a 3-second window: `?MAP,PWM,CLEAR,OUT,S<n>` (WCB.ino:5138-5140) and its legacy alias `?PX<n>` (WCB.ino:5942-5944), plus `eraseNVSFlash()` (WCB_Storage.cpp:1084-1086). The PWM one is the nastiest — the comment at WCB.ino:5133 says the Wizard sends it 'when a remote dest is deleted', i.e. in the middle of a config push, which is exactly the stream-of-commands case rule 11 was written about. The correct pattern is already in the tree and already carries the post-mortem comment: `pwmRebootPending` (WCB_PWM.cpp:25, WCB_PWM.h:38-42) honoured by loop() at WCB.ino:8385-8392 once the queue is empty AND quiet for PWM_REBOOT_QUIET_MS (WCB.ino:968). WCB_Storage.cpp:1074-1078 even records that clearAllPWMMappings' inline restart was already moved onto that flag once.

**How it is reached.** Rebooting a remote board from the Wizard terminal or the USB console (`;W2,?reboot`) is routine — after a config change, after a firmware setting, as the standard 'make it take effect'. Anything sent in the next 2 s is ACKed and lost. The PWM variant is worse because the Wizard itself issues it mid-push with a 3 s window, and the push is scored fully ACKed.

**Why it matters.** Silently reports success for something that did not happen, and loses queued commands — the exact failure CLAUDE.md rule 11 documents as having already cost a debugging session ('the pusher cannot tell, because the boot banner satisfies its did-the-board-answer test, so nothing retries and the push is scored as fully ACKed'). The user's config push looks clean and the board comes up with part of it missing.

**Fix.** Add a general `rebootPending` volatile beside `pwmRebootPending` (or reuse `pwmRebootPending` and generalise the loop() message) and set it instead of restarting inline: WCB.ino:827-831 `reboot()` becomes `Serial.println("Reboot queued — restarting once the command queue is quiet"); pwmRebootPending = true;`; same substitution at WCB.ino:5138-5140, WCB.ino:5942-5944, and WCB_Storage.cpp:1084-1086. loop() at WCB.ino:8385-8392 already does the quiet-window wait, the Serial.flush() and the 150 ms UART drain — no new machinery. Leave WCB_OTA.cpp:310 and :429 alone (post-flash restarts, not command handlers) and leave the boot guard at WCB.ino:7580.

**Risk.** `?reboot` stops being 'restarts in exactly 2 s' and becomes 'restarts after 4 s of quiet' — anything waiting a fixed time for the boot banner needs slack: the HIL harness's `w.reboot()` (tests/hil/suites/common.py), the Wizard's reboot button, and any OTA or config flow that reboots then immediately resumes. Second-order: a board being hammered with commands defers its restart indefinitely; that is intended, but the console line should say so or it reads as a hang. Also ensure `eraseNVSFlash()` cannot be re-entered while the flag is set.

#### 13. ETM numeric setters have no validation and no query form: a bare ?ETM,TIMEOUT / BOOT / DELAY and every legacy ?ETM<key> spelling persist 0 to NVS

| | |
|---|---|
| **Status** | VERIFIED — etm.unvalidated_setters, etm.legacy_miss0_rejected PASS on the bench (20260922-125537) |
| **Owner** | `WCB_firmware` |
| **Effort** | M |
| **Tests** | `etm.unvalidated_setters`, `etm.legacy_miss0_rejected` |
| **Subsystem** | etm-mesh |

**Mechanism.** One root cause, two spellings — the range checks were retrofitted key-by-key and most keys were missed. That is why these two tests collapse into one defect and one fix. New form (WCB.ino:5281-5360): `TIMEOUT` (5296-5299), `BOOT` (5330-5333) and `DELAY` (5338-5341) each do `etmVal.toInt(); saveETMSettings();` with no length test and no range test. A bare `?ETM,TIMEOUT` leaves etmVal == "", toInt() gives 0, and 0 goes to NVS. `?ETM,TIMEOUT,-5` stores -5. `HB` (5305-5316) and `MISS` (5318-5329) are the same code with a query form and a range check bolted on, and the comment at WCB.ino:5301-5304 states in plain words that this exact trap already bit once ('written straight to NVS and turned the board into a ~4 Hz heartbeat emitter that survived reboots'). `COUNT` is `constrain(...,10,200)` (5335) and is correct — the test asserts that half passes, deliberately. Legacy form (WCB.ino:5973-6004): `?ETMHB<n>` got the guard (5991-6000, with its own comment 'Same 0-writes-to-NVS trap as ?ETM,HB above'), and its four neighbours did not — `?ETMCHARDELAY` (5977-5980), `?ETMTIMEOUT` (5983-5986), `?ETMBOOT` (5987-5990) and `?ETMMISS` (6001-6004) all take `message.substring(n).toInt()` unchecked. Bare `?ETMMISS` gives substring("") -> 0 just like `?ETMMISS0`. What the bad values do: - etmMissedHeartbeats = 0 -> `offlineThresholdMs = (etmHeartbeatSec+1) * 0 * 1000 = 0` (WCB.ino:1114), so `millis()-lastSeenMs > 0` is true for every peer on every sweep: the whole fleet is marked OFFLINE (the bench log shows '[ETM] WCB2 went OFFLINE (no heartbeat for 0s)'), and `etmAddToPendingTable` skips every offline board at WCB.ino:1278, so no expectAckFrom bit is ever set — every ensured send silently degrades to fire-once with no retry, no ACK tracking and no failure report. - etmTimeoutMs = 0 -> t …

**How it is reached.** Typing the bare command to ASK what a setting is. There is no query form for TIMEOUT/BOOT/DELAY and no `?ETM,TIMEOUT?` — `?ETM,HB` answers ('ETM heartbeat is 10 sec') precisely because someone already did this, so the bare form reads as the house style. `?ETMMISS` / `?ETMMISS0` are in the legacy vocabulary that older configs and the wiki still use.

**Why it matters.** MISS=0 silently removes ETM's delivery guarantee fleet-wide while every board reports OFFLINE — the user is now debugging a 'dead mesh' whose commands mostly still arrive. TIMEOUT=0 makes every ensured command report FAILED. Both survive reboot, both ride into ?backup, and the trigger is a query the user believed was read-only. This is 'corrupts saved config' plus 'silently reports success for something that did not happen' in one command.

**Fix.** Route every ETM numeric key through one validated setter instead of repeating the pattern. In the `?ETM` block (WCB.ino:5296-5341) give TIMEOUT / BOOT / DELAY the shape HB and MISS already have: empty etmVal -> print the current value and return; otherwise parse, range-check (TIMEOUT 50-10000 ms, BOOT 1-30 s, DELAY 0-5000 ms — an explicit DELAY 0 is legitimate, it is only the *bare* form that must not write it), reject with the existing `Invalid ETM <name> '<val>'. Use <lo>-<hi>.` wording, and only then save. Mirror it into the legacy branch for `?ETMTIMEOUT` (5983), `?ETMBOOT` (5987), `?ETMCHARDELAY` (5977) and `?ETMMISS` (6001), copying the `?ETMHB` guard at 5991-6000 including its 'currently %d' phrasing so etm.legacy_forms keeps passing. Leave COUNT's constrain alone. Add a load-time clamp in WCB_Storage.cpp:2317-2326 so a board already holding 0 from this bug heals on the next boot — mirroring the defensive clamp the heartbeat path already carries (WCB.ino:1080-1084, 'belt-and-braces for a value restored from an NVS blob written by older firmware'). This one earns a docs line: it is a trap someone has now walked into twice.

**Risk.** Rejecting out-of-range values changes what a restore does with an already-corrupted backup chain — it will now print errors instead of silently re-applying 0, which is the point, but the console line should say so. etm.legacy_forms asserts the exact strings for ?ETMHB0 / ?ETMHB12 / ?ETMTIMEOUT650 / ?ETMBOOT3 / ?ETMCHARCOUNT5 / ?ETMCHARDELAY150 / ?etmmiss6 and the ?config rendering — keep those byte-identical. A TIMEOUT floor set too high would break etm.offline_detection_timing and the ETM characterization tool, which use short timeouts deliberately; 50 ms is safely below anything the suite sets (the bench runs 500).

#### 14. With the Kyber on S3-S5, ports S1 and S2 go completely dead — no command reader and no broadcasts — because Kyber_Local still means "S1+S2" in two places

| | |
|---|---|
| **Status** | VERIFIED — kyber.local_port_s1_frees_s2 (the replacement test) PASS in 20260922-211114 and 20260922-215719 |
| **Owner** | `WCB_firmware` |
| **Effort** | M |
| **Tests** | `kyber.local_port_s1_frees_s2` (replaces `kyber.local_port_s3_frees_s2`, which can never run now that #28 refuses S3-S5) |
| **Subsystem** | maestro-kyber |

**Mechanism.** `serialCommandTask` computes the right predicate at WCB.ino:7378 (`const int kyberOwned = Kyber_Local ? kyberLocalPort : 0;`) and uses it correctly for S3-S5 at :7383-7385 — but the S1/S2 branch at :7388-7391 is still a bare `if (Kyber_Local) { /* skip both */ }`. Its comment ("the Kyber task drains both regardless of kyberLocalPort") is factually wrong: `forwardDataFromKyber` returns at WCB.ino:4812 unless `kyberLocalPort` is set and then reads only that one port (:4821-4822), and `forwardMaestroDataToLocalKyber` reads only configured LOCAL Maestro ports (:4900-4910). So with `kyberLocalPort == 3` and no Maestro on S2, S2 has no reader at all: serialCommandTask skips it, KyberLocalTask never touches it, RawSerialForwardingTask only handles raw-mapped ports (:7425-7426). Separately, `processBroadcastCommand` skips `(i <= 2 && Kyber_Local)` at WCB.ino:7042, so broadcast OUTPUT to S1 and S2 is suppressed too — overriding the user's persisted `?BCAST,OUT,S2,ON`, which `?backup` still reports as ON. Bench evidence: results/20260916-122250/session.log lines 99363-100219 — `?KYBER,LOCAL,S3` accepted, then a `;S4` typed into W1 S2 never executed and a USB broadcast never reached S2, while the S4 control paths both worked. Same code has a sibling hole: :7383-7385 skips only `kyberOwned`, not local Maestro ports, so a Maestro on S4 with the Kyber on S3 is drained by BOTH serialCommandTask and forwardMaestroDataToLocalKyber (`processIncomingSerial` filters MP3/DFP/HCR/query/reconfig at WCB.ino:7112-7128 but not Maestro ports) — byte-stealing, confirmable in source, not exercised by this run.

**How it is reached.** Any builder who puts the Kyber/sabre on something other than S2 — `?KYBER,LOCAL,S3` is an advertised form and the command accepts S1-S5 — and who also has a device on S1 or S2 that sends `;` commands or expects broadcasts (W1's own bench config has 'Magic Panel(IA)' labelled on S2 with BCAST ON). No error, no warning; the port simply stops existing.

**Why it matters.** Bricks up to two ports until the Kyber mode is changed, with no diagnostic and while `?backup` keeps reporting them enabled. A dead command port reads as 'the WCB is broken' — the exact failure mode CLAUDE.md rule 12 calls out as costing a debugging session.

**Fix.** WCB.ino:7388-7391 — delete the `Kyber_Local` special case for S1/S2 and gate those two ports the same way S3-S5 already are: skip when `kyberOwned == port`, and skip when the port hosts a configured local Maestro (the Kyber/Maestro-remote tasks own those bytes). Then apply the same Maestro-port skip to :7383-7385 so S3-S5 Maestros stop being double-read. WCB.ino:7042 — change `(i <= 2 && Kyber_Local)` to `(Kyber_Local && i == kyberLocalPort)`; configured Maestro ports are already excluded generically at :7048-7060, so nothing is lost. Fix the false comment at :7389-7391 in the same commit.

**Risk.** This changes who reads S1/S2 on every Kyber_Local board in the field, so the single-reader invariant must hold exactly: verify on the bench with the Kyber on S2 (the common case) that S2 is still read only by the Kyber task and S1 only by the Maestro bridge, before and after. The Maestro-port skip added to S3-S5 is the riskier half — get the 'is this a local Maestro port' helper right or you will silently stop parsing commands on a port that used to work.

**Update (2026-09-22).** #28 now refuses S3-S5, but #14 is still reachable through the other hardware port. With `?KYBER,LOCAL,S1` and no Maestro on S2, serialCommandTask still skips S1 AND S2 for any Kyber_Local board (WCB.ino ~:7620-7624, whose comment is still wrong). KyberLocalTask reads only `kyberLocalPort` and the local Maestro ports, so nothing reads S2. `processBroadcastCommand` also skips every port <= 2 whenever Kyber_Local is set (~:7240), overriding a persisted `?BCAST,OUT,S2,ON`. The mirror case is live too: Kyber on S2 with the Maestro on S3-S5 leaves S1 unread. **Designed fix (not applied, needs Greg's OK):** read S1/S2 when `kyberOwned != port` and the port is not raw-mapped (processIncomingSerial already drops bridge-owned Maestro ports, #59), fix the false comment, and change the broadcast skip to `(Kyber_Local && i == kyberLocalPort)`. The per-slot Maestro exclusion in the broadcast loop still protects configured Maestro ports. **Caveat:** a board with a real Maestro on S1 but NO `?MAESTRO` slot would start receiving ASCII broadcasts on S1. The new test `kyber.local_port_s1_frees_s2` pins the bug and fails until this is fixed.

**Applied (2026-09-22, Greg: "apply it").** serialCommandTask reads S1/S2 on a Kyber_Local board unless the port is `kyberLocalPort` or raw-mapped, and processBroadcastCommand skips only `kyberLocalPort`. A review confirmed the reader logic in every mode and transition, including `kyber.local_mode_s2`'s pre-reboot deaf window (the Kyber port stays unread until the reboot). Follow-ups it found are #73.
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

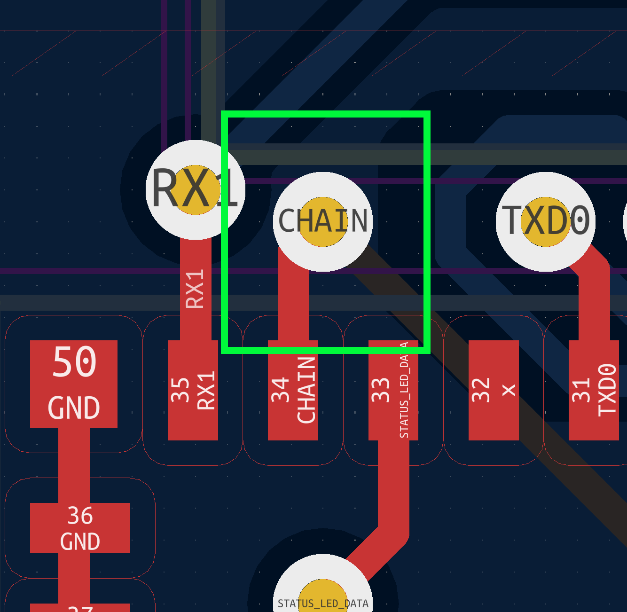
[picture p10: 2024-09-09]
Images/Issues with 2.3/Chain via Top Layer.png

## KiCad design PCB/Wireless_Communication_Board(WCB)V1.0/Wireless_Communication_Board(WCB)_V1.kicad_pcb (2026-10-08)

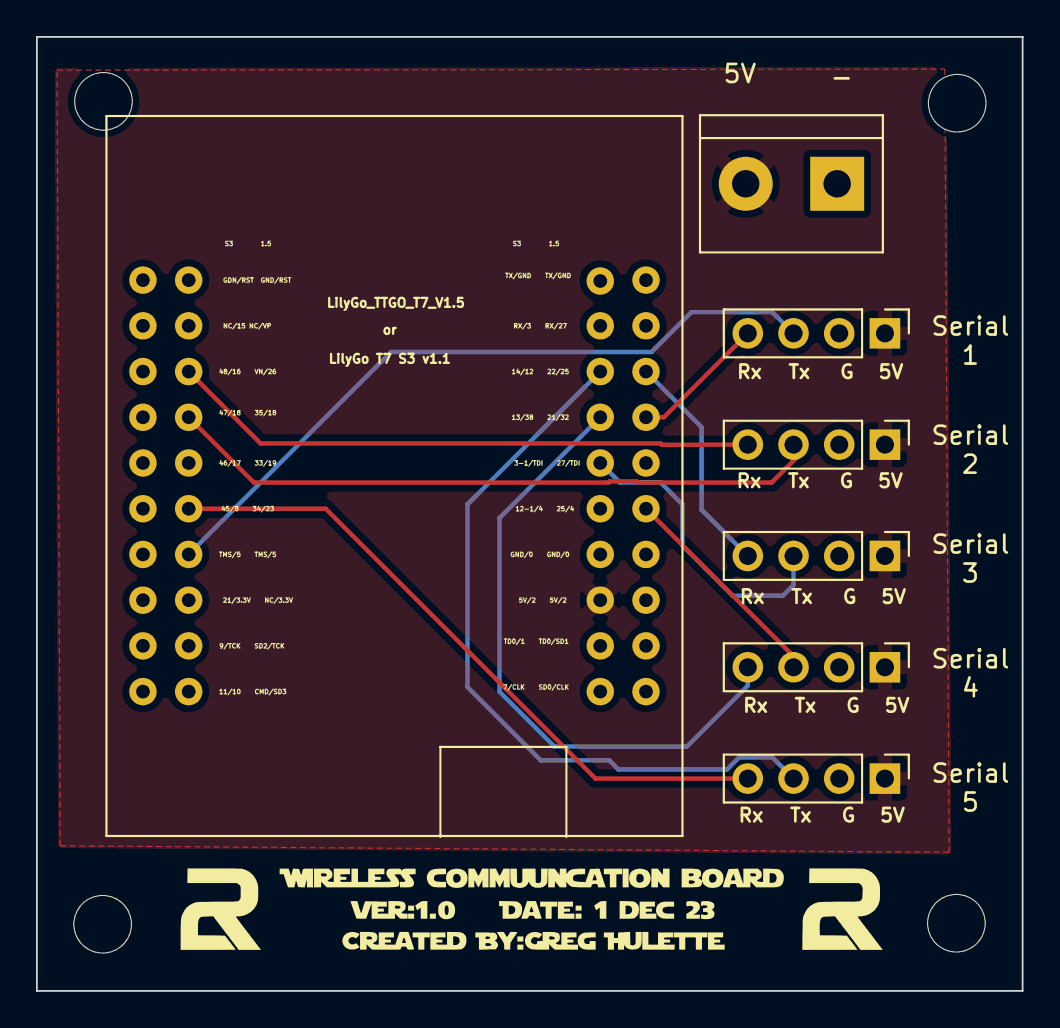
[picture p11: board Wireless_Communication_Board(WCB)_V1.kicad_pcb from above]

Board: 2 copper layers, 54.8 x 53.0 mm, 7 parts (0 on the bottom side), 12 nets.

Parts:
J1: S1; PinHeader_1x04_P2.54mm_Vertical
J2: S2; PinHeader_1x04_P2.54mm_Vertical
J3: S3; PinHeader_1x04_P2.54mm_Vertical
J4: S4; PinHeader_1x04_P2.54mm_Vertical
J5: S5; PinHeader_1x04_P2.54mm_Vertical
J6: Screw_Terminal_01x02; TerminalBlock_bornier-2_P5.08mm
U1: LilyGo_TTGO_T7_V1.5; LILYGO_TTGO_T7_V1.5

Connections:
+5V: J1.1, J2.1, J3.1, J4.1, J5.1, J6.2, U1.70 (5V)
GND: J1.2, J2.2, J3.2, J4.2, J5.2, J6.1, U1.60 (GND), U1.61 (GND), U1.62 (GND)
Rx1: J1.4, U1.32 (GPIO32)
Rx2: J2.4, U1.26 (GPIO26)
Rx3: J3.4, U1.251 (GPIO25_1)
Rx4: J4.4, U1.21 (GPIO21)
Rx5: J5.4, U1.23 (GPIO23)
Tx1: J1.3, U1.5 (GPIO5)
Tx2: J2.3, U1.18 (GPIO18)
Tx3: J3.3, U1.27 (GPIO27)
Tx4: J4.3, U1.4 (GPIO4)
Tx5: J5.3, U1.22 (GPIO22)

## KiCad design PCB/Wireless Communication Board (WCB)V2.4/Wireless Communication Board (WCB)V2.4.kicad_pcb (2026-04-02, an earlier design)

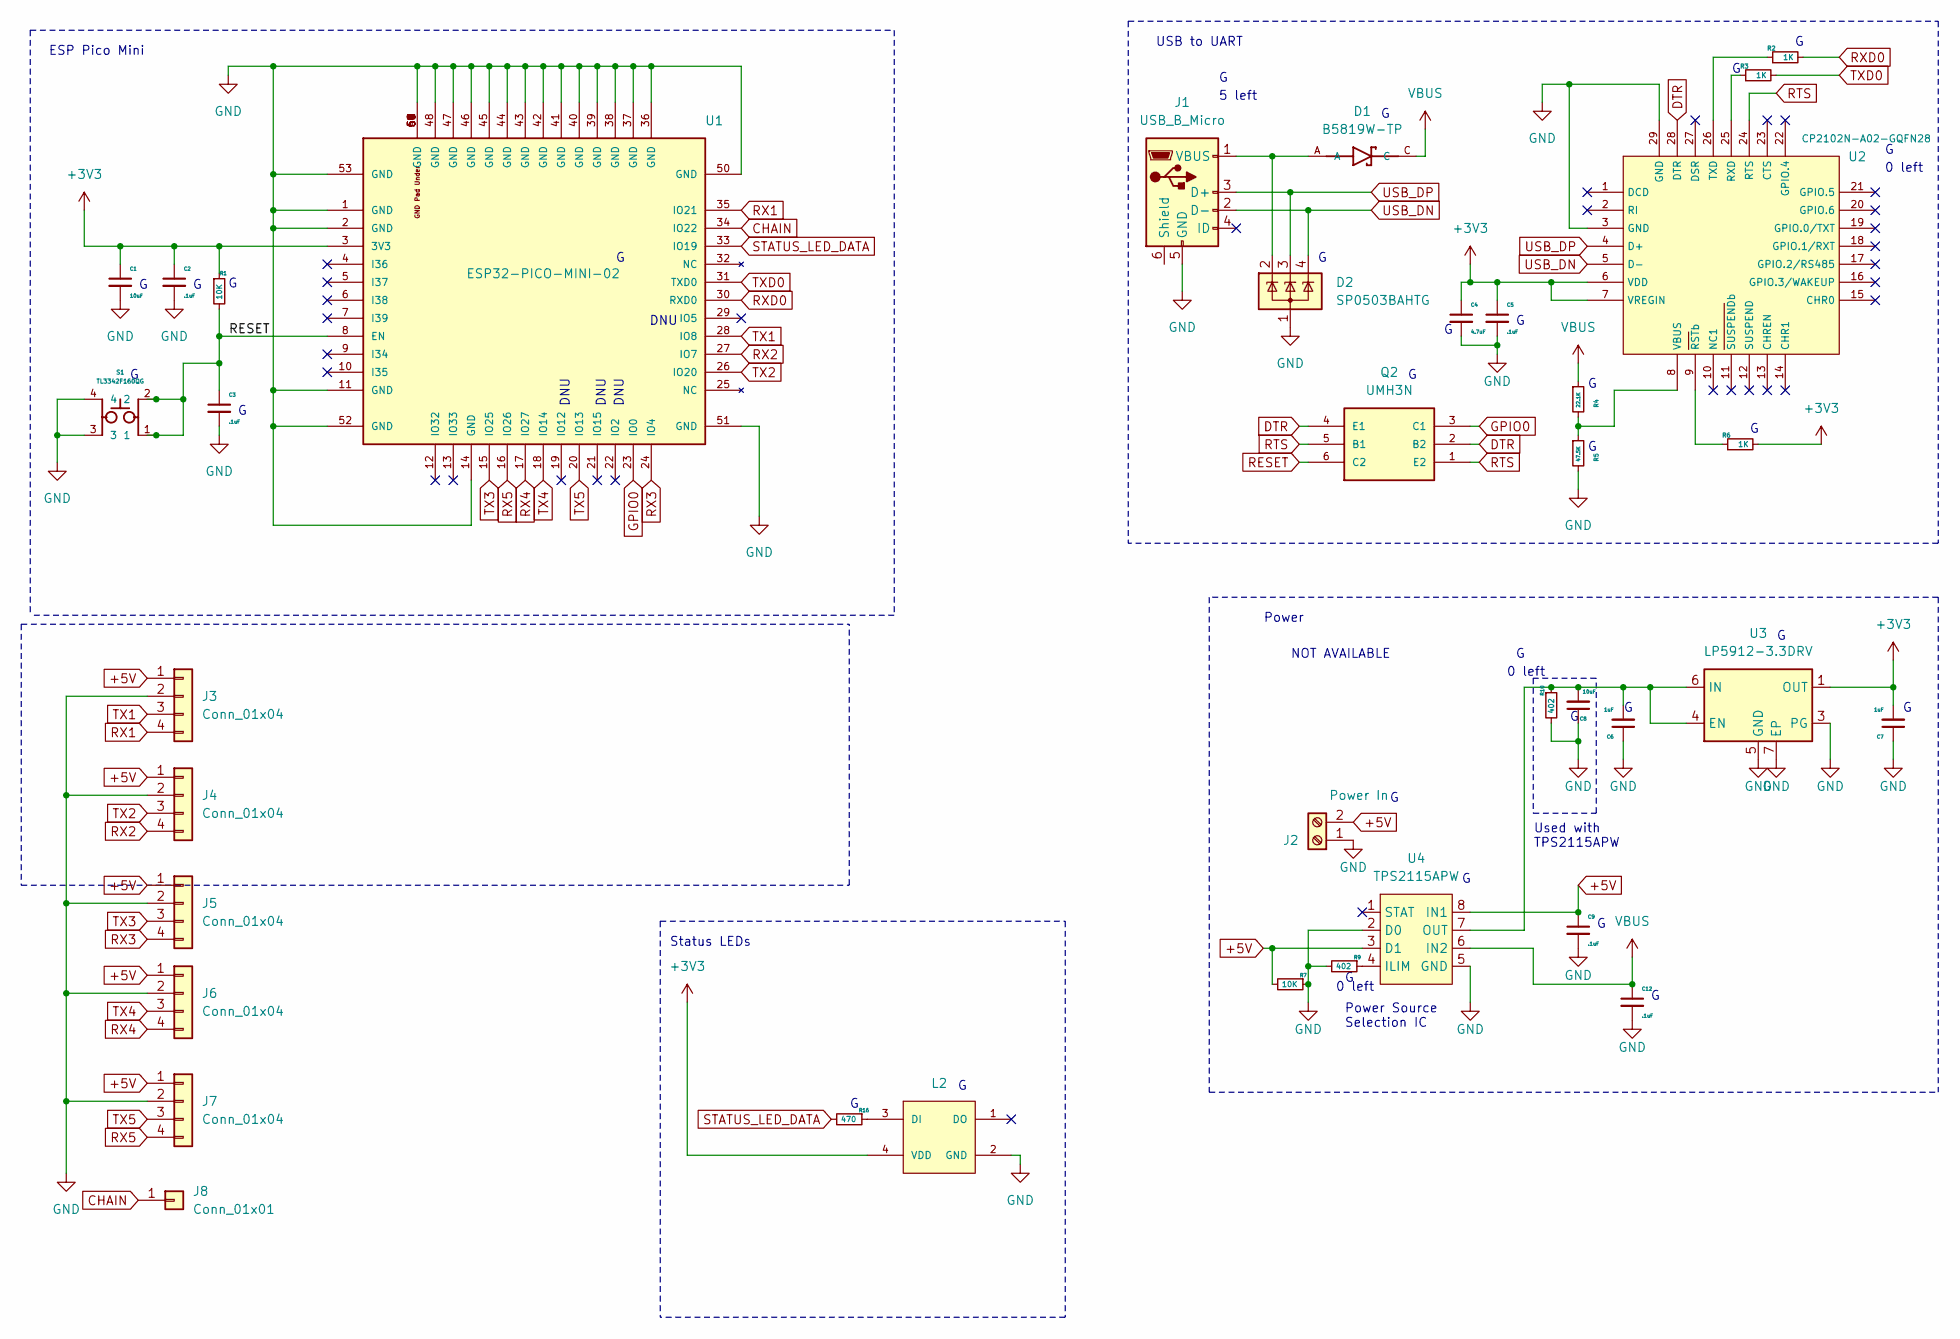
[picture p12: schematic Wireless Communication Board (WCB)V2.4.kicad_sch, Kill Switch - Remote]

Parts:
C1, C8: 10uF; C_0805_2012Metric; Manufacturers Part Numb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 CS2012X7R106K100NRE; LCSC C1222438
C2, C3, C5, C9, C12: .1uF; C_0402_1005Metric; Manufacturers Part Numb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 CL05B104KB54PNC; LCSC C307331
C4: 4.7uF; C_0805_2012Metric; Manufacturers Part Numb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 GCM21BR71C475KA67L; LCSC C126590
C6, C7: 1uF; C_0603_1608Metric; Manufacturers Part Numb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 GRM188B31H105KAALD; LCSC C913562
D1: B5819W-TP; SOD3716X135N; Manufacturers Part Numb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 B5819W-TP; Digikey Part Number B5819W-TPMSCT-ND
D2: SP0503BAHTG; SOT-143; Manufacturers Part Numb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 SP0503BAHTG; Digikey Part Number F2715CT-ND
J1: USB_B_Micro; USB_Micro-B_Amphenol_10118194_Horizontal; Manufacturers Part Numb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 10118194-0001LF; Digikey Part Number 609-4618-1-ND
J2: Power In; TerminalBlock_bornier-2_P5.08mm; Manufacturers Part Numb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 141-A-111/02; LCSC C3011914
J3, J4, J5, J6, J7: Conn_01x04; PinHeader_1x04_P2.54mm_Vertical; LCSC C2691448
J8: Conn_01x01; PinHeader_1x01_P2.54mm_Vertical; LCSC C81276
L2: WS2812B-2020; Manufacturers Part Numb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 WS2812B-2020; LCSC C965555
Q2: UMH3N; SOT65P230X110-6N; MANUFACTURER_PART_NUMBER UMH3N; Digikey Part Number UMH3NTNCT-ND
R1: 10K; R_0402_1005Metric; Manufacturers Part Numb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 RC0402JR-0710KL; Digikey Part Number 311-10KJRCT-ND
R2, R3, R6: 1K; R_0402_1005Metric; Manufacturers Part Numb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 RC0402JR-071KL; Digikey Part Number 311-1.0KJRCT-ND
R4: 22.1K; R_0402_1005Metric; Manufacturers Part Numb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 RC0402JR-0722KL; Digikey Part Number 311-22KJRCT-ND
R5: 47.5K; R_0402_1005Metric; Manufacturers Part Numb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 RC0402FR-0747K5L; Digikey Part Number 311-47.5KLRCT-ND
R7: 10K; R_0402_1005Metric; Manufacturers Part Numb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 AR02DTC1002; LCSC C414854
R9, R10: 402; R_0402_1005Metric; Manufacturers Part Numb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 CR204000F; LCSC C41042
R16: 470; R_0402_1005Metric; Manufacturers Part Numb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 RT0402BRD07470RL; LCSC C114949
S1: TL3342F160QG; SW_TL3342F160QG; Manufacturers Part Numb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 TS-1076S-A6B3; LCSC C492949
U1: ESP32-PICO-MINI-02; MODULE_ESP32-PICO-MINI-02; PARTREV v1.0; Digikey Part Number 1965-ESP32-PICO-MINI-02-N8R2CT-ND
U2: CP2102N-A02-GQFN28; QFN-28-1EP_5x5mm_P0.5mm_EP3.35x3.35mm; Manufacturers Part Numb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 CP2102N-A02-GQFN28; Digikey Part Number 336-5889-ND
U3: LP5912-3.3DRV; WSON-6-1EP_2x2mm_P0.65mm_EP1x1.6mm_ThermalVias; Manufacturers Part Numb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 LP5912Q3.3DRVTQ1; LCSC C575581
U4: TPS2115APW; TSSOP-8_4.4x3mm_P0.65mm; Manufacturers Part Numb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 TPS2115APWR; Digikey Part Number 296-26918-5-ND

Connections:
+3V3: C1.1, C2.1, C4.1, C5.1, C7.2, L2.4 (VDD), R1.1, R6.2, U1.3 (3V3), U2.6 (VDD), U2.7 (VREGIN), U3.1 (OUT)
+5V: C9.1, J2.2, J3.1, J4.1, J5.1, J6.1, J7.1, R7.2, U4.3 (D1), U4.8 (IN1)
CHAIN: J8.1, U1.34 (IO22)
DTR: Q2.2 (B2), Q2.4 (E1), U2.28 (DTR)
GND: C1.2, C2.2, C3.2, C4.2, C5.2, C6.1, C7.1, C8.1, C9.2, C12.2, D2.1 (A), J1.5 (GND), J2.1, J3.2, J4.2, J5.2, J6.2, J7.2, L2.2 (GND), R5.2, R7.1, R9.2, R10.2, S1.3, S1.4, U1.1 (GND), U1.2 (GND), U1.11 (GND), U1.14 (GND), U1.36 (GND), U1.37 (GND), U1.38 (GND), U1.39 (GND), U1.40 (GND), U1.41 (GND), U1.42 (GND), U1.43 (GND), U1.44 (GND), U1.45 (GND), U1.46 (GND), U1.47 (GND), U1.48 (GND), U1.49 (GND), U1.50 (GND), U1.51 (GND), U1.52 (GND), U1.53 (GND), U1.54 (GND), U1.55 (GND), U1.56 (GND), U1.57 (GND), U1.58 (GND), U1.59 (GND), U1.60 (GND), U1.61 (GND), U2.3 (GND), U2.29 (GND), U3.3 (PG), U3.5 (GND), U3.7 (EP), U4.2 (D0), U4.5 (GND)
GPIO0: Q2.3 (C1), U1.23 (IO0)
unnamed: C6.2, C8.2, R10.1, U3.4 (EN), U3.6 (IN), U4.7 (OUT)
unnamed: D1.A, D2.2 (K), J1.1 (VBUS)
unnamed: L2.3 (DI), R16.1
unnamed: R2.1, U2.26 (TXD)
unnamed: R3.1, U2.25 (RXD)
unnamed: R4.2, R5.1, U2.8 (VBUS)
unnamed: R6.1, U2.9 (RSTb)
unnamed: R9.1, U4.4 (ILIM)
RESET: C3.1, Q2.6 (C2), R1.2, S1.1, S1.2, U1.8 (EN)
RTS: Q2.1 (E2), Q2.5 (B1), U2.24 (RTS)
RX1: J3.4, U1.35 (IO21)
RX2: J4.4, U1.27 (IO7)
RX3: J5.4, U1.24 (IO4)
RX4: J6.4, U1.17 (IO27)
RX5: J7.4, U1.16 (IO26)
RXD0: R2.2, U1.30 (RXD0)
STATUS_LED_DATA: R16.2, U1.33 (IO19)
TX1: J3.3, U1.28 (IO8)
TX2: J4.3, U1.26 (IO20)
TX3: J5.3, U1.15 (IO25)
TX4: J6.3, U1.18 (IO14)
TX5: J7.3, U1.20 (IO13)
TXD0: R3.2, U1.31 (TXD0)
USB_DN: D2.4 (K), J1.2 (D-), U2.5 (D-)
USB_DP: D2.3 (K), J1.3 (D+), U2.4 (D+)
VBUS: C12.1, D1.C, R4.1, U4.6 (IN2)

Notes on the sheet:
0 left
Power
DNU
ESP Pico Mini
NOT AVAILABLE
5 left
Power Source Selection IC
Status LEDs
Used with TPS2115APW
USB to UART

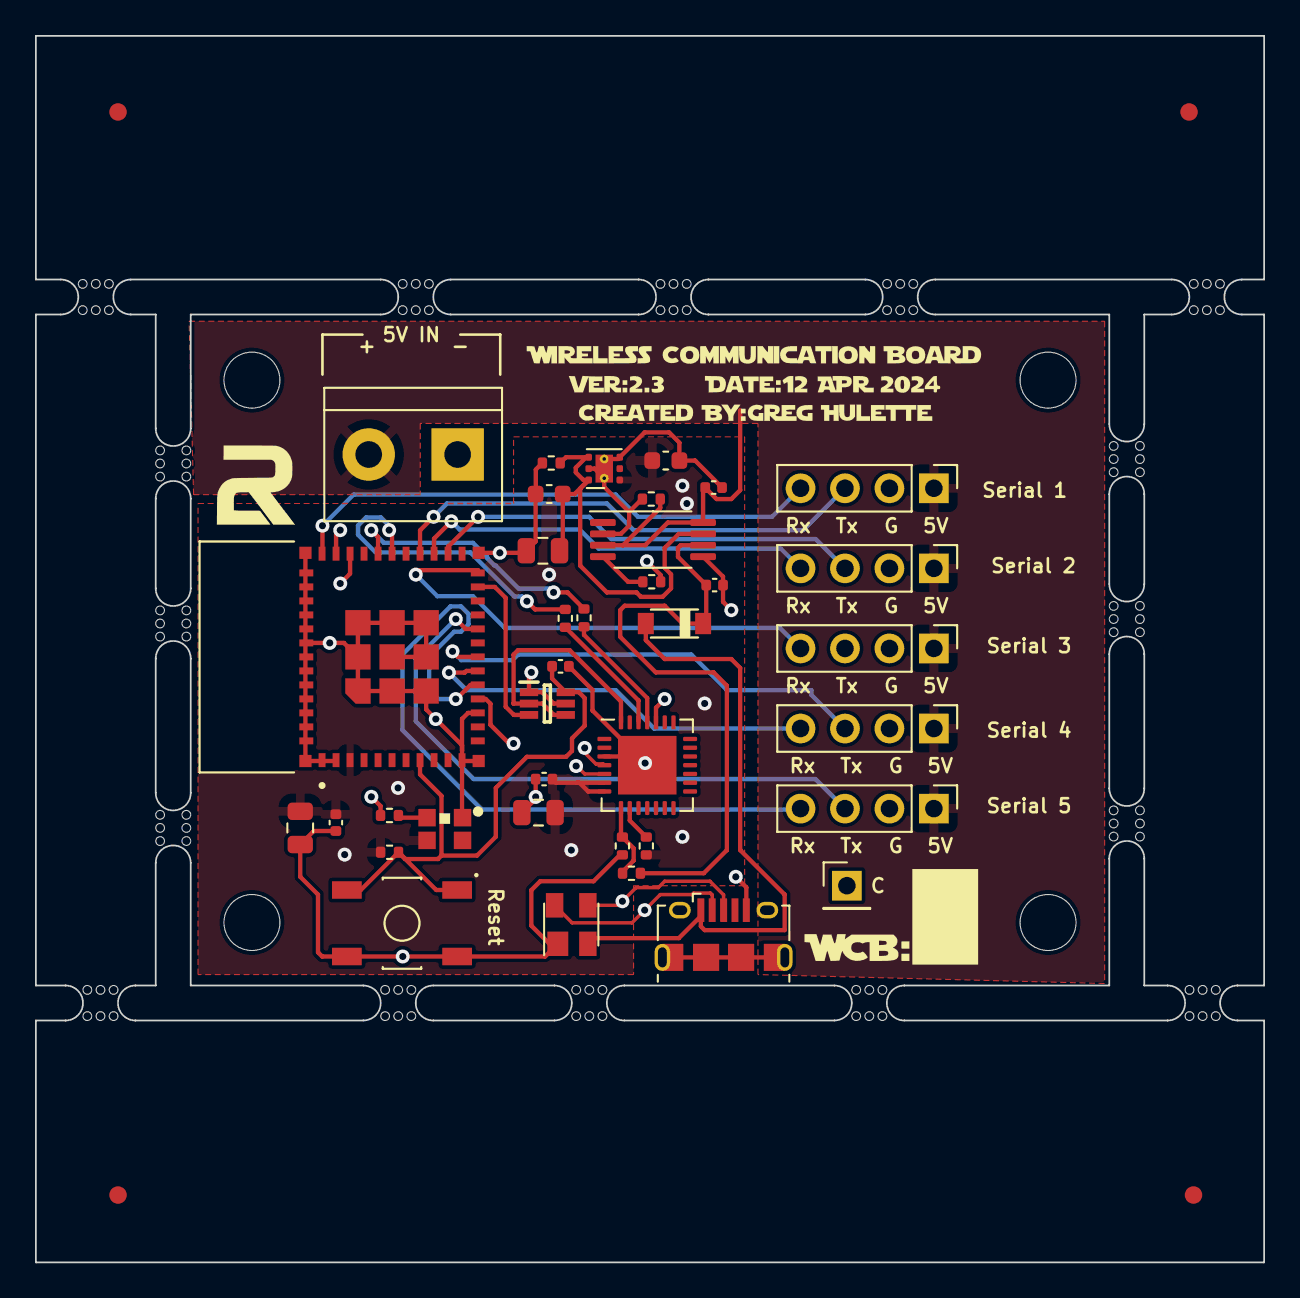
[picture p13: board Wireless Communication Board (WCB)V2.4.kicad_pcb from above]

Board: 4 copper layers, 70.2 x 70.1 mm, 53 parts (0 on the bottom side), 32 nets.

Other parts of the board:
mouse-bite-2mm-slot, mouse-bite-2mm-slot#2, mouse-bite-2mm-slot#3, mouse-bite-2mm-slot#4, mouse-bite-2mm-slot#5, mouse-bite-2mm-slot#6, mouse-bite-2mm-slot#7, mouse-bite-2mm-slot#8, mouse-bite-2mm-slot#9, mouse-bite-2mm-slot#10, mouse-bite-2mm-slot#11, mouse-bite-2mm-slot#12, mouse-bite-2mm-slot#13, mouse-bite-2mm-slot#14, mouse-bite-2mm-slot#15, mouse-bite-2mm-slot#16: VAL**; mouse-bite-2mm-slot

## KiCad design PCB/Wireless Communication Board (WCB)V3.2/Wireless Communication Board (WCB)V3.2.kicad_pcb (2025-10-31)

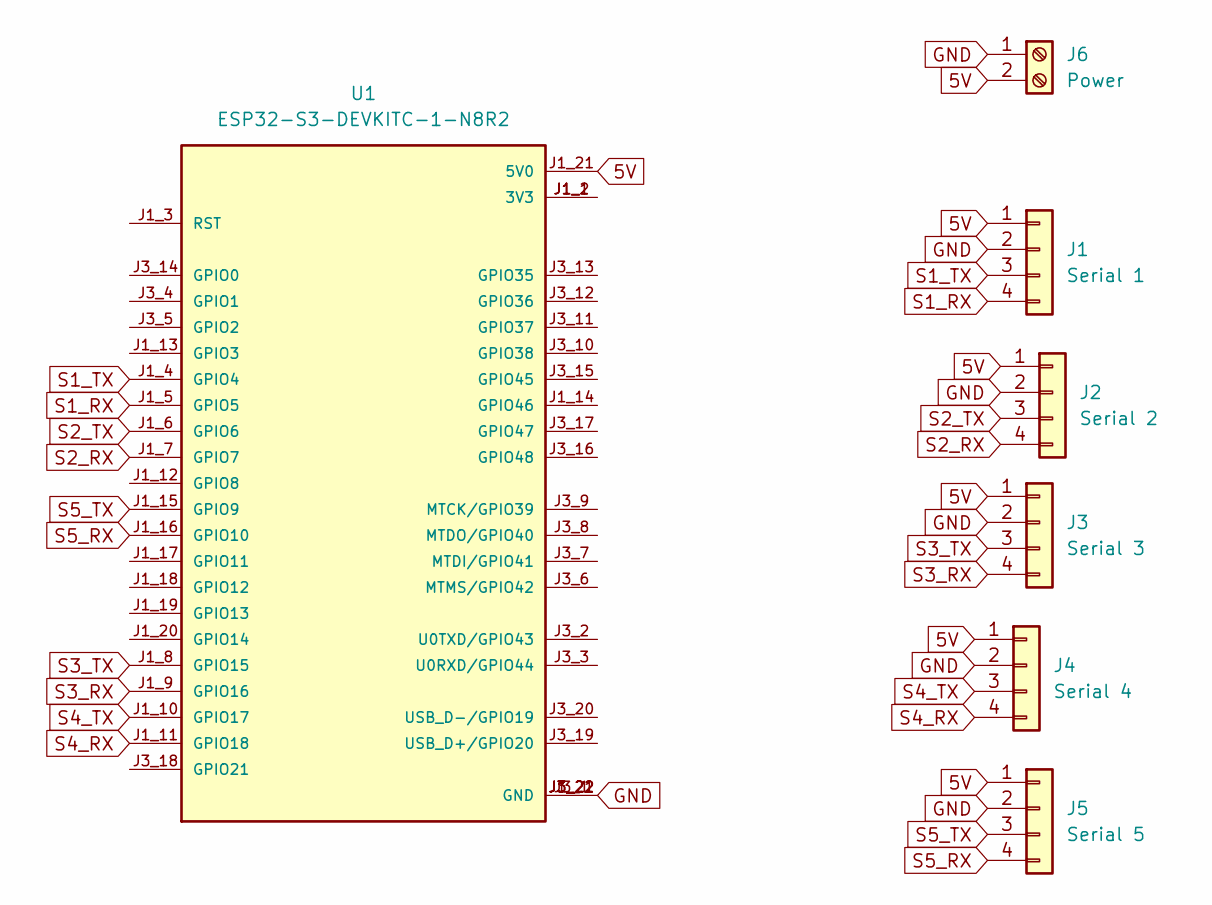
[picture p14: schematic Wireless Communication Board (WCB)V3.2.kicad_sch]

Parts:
J1: Serial 1; PinHeader_1x04_P2.54mm_Vertical
J2: Serial 2; PinHeader_1x04_P2.54mm_Vertical
J3: Serial 3; PinHeader_1x04_P2.54mm_Vertical
J4: Serial 4; PinHeader_1x04_P2.54mm_Vertical
J5: Serial 5; PinHeader_1x04_P2.54mm_Vertical
J6: Power; TerminalBlock_Phoenix_MKDS-1,5-2-5.08_1x02_P5.08mm_Horizont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
U1: ESP32-S3-DEVKITC-1-N8R2; XCVR_ESP32-S3-DEVKITC-1-N8R2; PARTREV V1

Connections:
5V: J1.1, J2.1, J3.1, J4.1, J5.1, J6.2, U1.J1_21 (5V0)
GND: J1.2, J2.2, J3.2, J4.2, J5.2, J6.1, U1.J1_22 (GND), U1.J3_1 (GND), U1.J3_21 (GND), U1.J3_22 (GND)
unnamed: U1.J1_1 (3V3), U1.J1_2 (3V3)
S1_RX: J1.4, U1.J1_5 (GPIO5)
S1_TX: J1.3, U1.J1_4 (GPIO4)
S2_RX: J2.4, U1.J1_7 (GPIO7)
S2_TX: J2.3, U1.J1_6 (GPIO6)
S3_RX: J3.4, U1.J1_9 (GPIO16)
S3_TX: J3.3, U1.J1_8 (GPIO15)
S4_RX: J4.4, U1.J1_11 (GPIO18)
S4_TX: J4.3, U1.J1_10 (GPIO17)
S5_RX: J5.4, U1.J1_16 (GPIO10)
S5_TX: J5.3, U1.J1_15 (GPIO9)

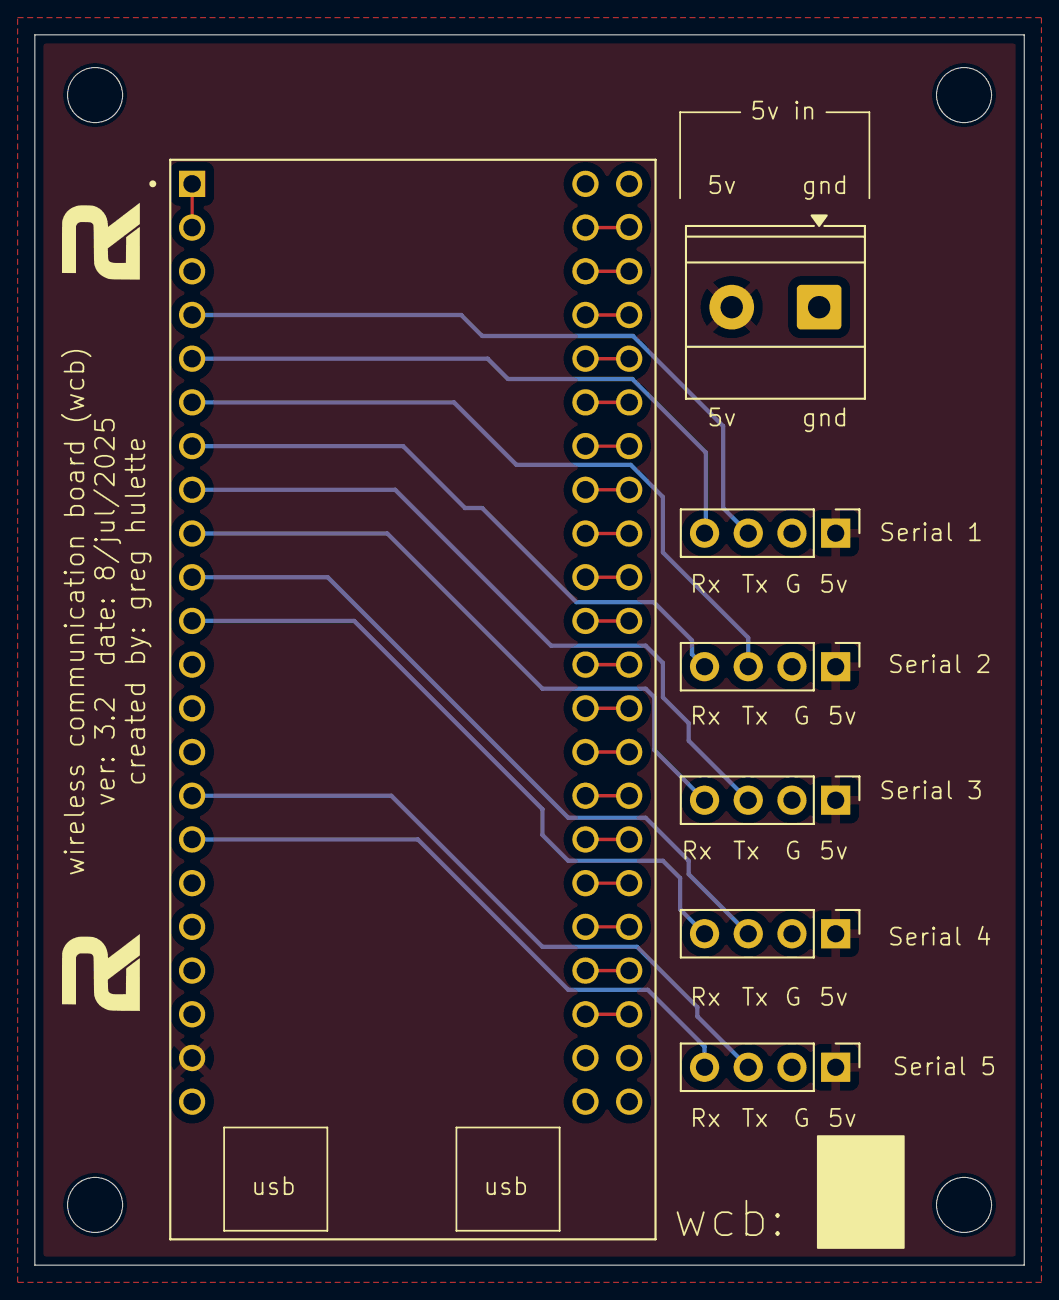
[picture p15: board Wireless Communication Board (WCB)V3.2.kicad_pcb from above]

Board: 2 copper layers, 57.5 x 71.5 mm, 7 parts (0 on the bottom side), 13 nets.

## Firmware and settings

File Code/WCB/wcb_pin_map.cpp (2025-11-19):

//////////////////////////////// 
// Wireless Communincation Board (WCB) Pinout
//////////////////////////////// 
#include <Arduino.h>
#include "wcb_pin_map.h"



extern void updatePinMap(){
 if (wcb_hw_version == 0){
    //////////////////////////////// 
    // This pinout is for a Version 1.0 board (LilyGo T7 V1.5 ESP32)
    ////////////////////////////////
    SERIAL1_TX_PIN = 5;   //  // Serial 1 Tx Pin
    SERIAL1_RX_PIN = 5;   //  // Serial 1 Rx Pin
    SERIAL2_TX_PIN = 5;   //  // Serial 2 Tx Pin
    SERIAL2_RX_PIN = 5;   //  // Serial 2 Rx Pin
    SERIAL3_TX_PIN = 5;   //  // Serial 3 Tx Pin
    SERIAL3_RX_PIN = 5;   //  // Serial 3 Rx Pin
    SERIAL4_TX_PIN = 5;   //  // Serial 4 Tx Pin 
    SERIAL4_RX_PIN = 5;   //  // Serial 4 Rx Pin
    SERIAL5_TX_PIN = 5;   //  // Serial 5 Tx Pin
    SERIAL5_RX_PIN = 5;   //  // Serial 5 Rx Pin
    ONBOARD_LED    = 19;     //  // ESP32 Status NeoPixel Pin
    STATUS_LED_PIN = 19;  //  // Not used on this board but defining it to match   
    // Serial.println("Loaded Default Pinout");
 } else if (wcb_hw_version == 1){
    //////////////////////////////// 
    // This pinout is for a Version 1.0 board (LilyGo T7 V1.5 ESP32)
    ////////////////////////////////
     SERIAL1_TX_PIN = 5;  //  // Serial 1 Tx Pin
     SERIAL1_RX_PIN = 32; //  // Serial 1 Rx Pin
     SERIAL2_TX_PIN = 26; //  // Serial 2 Tx Pin
     SERIAL2_RX_PIN = 18; //  // Serial 2 Rx Pin
     SERIAL3_TX_PIN = 27; //  // Serial 3 Tx Pin
     SERIAL3_RX_PIN = 25; //  // Serial 3 Rx Pin
     SERIAL4_TX_PIN = 4;  //  // Serial 4 Tx Pin 
     SERIAL4_RX_PIN = 21; //  // Serial 4 Rx Pin
     SERIAL5_TX_PIN = 22; //  // Serial 5 Tx Pin
     SERIAL5_RX_PIN = 23; //  // Serial 5 Rx Pin
     ONBOARD_LED    = 19; //  // ESP32 Status NeoPixel Pin
     STATUS_LED_PIN = 12; //  // Not used on this board but defining it to match version 2.1 board
    
    // Serial.println("Loaded HW Version 1.0 Pinout");

 } else if (wcb_hw_version == 21){
    //////////////////////////////// 
    // This pinout is for a Version 2.1 (Custom Board)
    ////////////////////////////////
     SERIAL1_TX_PIN = 8;  //  // Serial 1 Tx Pin
     SERIAL1_RX_PIN = 5;  //  // Serial 1 Rx Pin
     SERIAL2_TX_PIN = 20; //  // Serial 2 Tx Pin
     SERIAL2_RX_PIN = 7;  //  // Serial 2 Rx Pin
     SERIAL3_TX_PIN = 15; //  // Serial 3 Tx Pin
     SERIAL3_RX_PIN = 4;  //  // Serial 3 Rx Pin
     SERIAL4_TX_PIN = 14; //  // Serial 4 Tx Pin
     SERIAL4_RX_PIN = 27; //  // Serial 4 Rx Pin
     SERIAL5_TX_PIN = 13; //  // Serial 5 Tx Pin
     SERIAL5_RX_PIN = 12; //  // Serial 5 Rx Pin
     ONBOARD_LED    = 25; //  // Not Used in this board but defined to match the Version 1.0 board's onboard Green LED
     STATUS_LED_PIN = 19; //  // ESP32 Status NeoPixel Pin
    // Serial.println("Loaded HW Version 2.1 Pinout");
 } else if (wcb_hw_version == 23){
      //////////////////////////////// 
    // This pinout is for a Version 2.3 (Custom Board)
    ////////////////////////////////
     SERIAL1_TX_PIN = 8;  //  // Serial 1 Tx Pin
     SERIAL1_RX_PIN = 21; //  // Serial 1 Rx Pin
     SERIAL2_TX_PIN = 20; //  // Serial 2 Tx Pin
     SERIAL2_RX_PIN = 7;  //  // Serial 2 Rx Pin
     SERIAL3_TX_PIN = 25; //  // Serial 3 Tx Pin
     SERIAL3_RX_PIN = 4;  //  // Serial 3 Rx Pin
     SERIAL4_TX_PIN = 14; //  // Serial 4 Tx Pin
     SERIAL4_RX_PIN = 27; //  // Serial 4 Rx Pin
     SERIAL5_TX_PIN = 13; //  // Serial 5 Tx Pin
     SERIAL5_RX_PIN = 26; //  // Serial 5 Rx Pin
     ONBOARD_LED    = 32; //  // Not Used in this board but defined to match the Version 1.0 board's onboard Green LED
     STATUS_LED_PIN = 19; //  // ESP32 on board NeoPixel Pin
    // Serial.println("Loaded HW Version 2.3 Pinout");
 } else if (wcb_hw_version == 24){
    //////////////////////////////// 
    // This pinout is for a Version 2.4 (Custom Board)
    ////////////////////////////////
    SERIAL1_TX_PIN = 8;  //  // Serial 1 Tx Pin
    SERIAL1_RX_PIN = 21; //  // Serial 1 Rx Pin
    SERIAL2_TX_PIN = 20; //  // Serial 2 Tx Pin
    SERIAL2_RX_PIN = 7;  //  // Serial 2 Rx Pin
    SERIAL3_TX_PIN = 25; //  // Serial 3 Tx Pin
    SERIAL3_RX_PIN = 4;  //  // Serial 3 Rx Pin
    SERIAL4_TX_PIN = 14; //  // Serial 4 Tx Pin 
    SERIAL4_RX_PIN = 27; //  // Serial 4 Rx Pin
    SERIAL5_TX_PIN = 13; //  // Serial 5 Tx Pin
    SERIAL5_RX_PIN = 26; //  // Serial 5 Rx Pin
    ONBOARD_LED    = 32; //  // Not Used in this board but defined to match the Version 1.0 board's onboard Green LED
    STATUS_LED_PIN = 19; //  // ESP32 on board NeoPixel Pin
    // Serial.println("Loaded HW Version 2.4 Pinout");
 }else if (wcb_hw_version == 32 || wcb_hw_version == 31){
    //////////////////////////////// 
    // This pinout is for a Version 3.0 (DIY Version)
    ////////////////////////////////
    SERIAL1_TX_PIN  = 4;  //  // Serial 1 Tx Pin
    SERIAL1_RX_PIN  = 5; //  // Serial 1 Rx Pin
    SERIAL2_TX_PIN  = 6; //  // Serial 2 Tx Pin
    SERIAL2_RX_PIN	= 7;  //  // Serial 2 Rx Pin
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

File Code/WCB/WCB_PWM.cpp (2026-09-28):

#include "WCB_RemoteTerm.h"  // Must be first — redirects Serial → WCBDebugSerial
#include "WCB_PWM.h"
#include "WCB_Storage.h"
#include "wcb_pin_map.h"
#include <Preferences.h>
#include <sdkconfig.h>
#include "driver/rmt_tx.h"      // hardware-timed output pulses - see pwmPulse()
#include "driver/rmt_encoder.h"
#include "soc/soc_caps.h"
#include "freertos/semphr.h"
#if CONFIG_IDF_TARGET_ESP32
#include "hal/gpio_ll.h"   // level-emulated PWM input edges (erratum GPIO-3.14) - see pwmEdge()
#endif

extern Preferences preferences;
extern int WCB_Number;
// NO default here on purpose: WCB.ino:977 defaults useETM to true, and a second default in this
// file silently won the 2-argument calls below - clearAllPWMMappings' remote commands went out
// as plain packets that every ETM receiver drops (WCB.ino:4203-4225), while this board still
// printed success. State it at every call site instead.
extern void sendESPNowMessage(uint8_t target, const char *message, bool useETM);
extern bool debugEnabled;
extern char LocalFunctionIdentifier;
extern bool serialBroadcastEnabled[5];
extern bool blockBroadcastFrom[5];
extern void saveBroadcastSettingsToPreferences();
extern void saveBroadcastBlockSettings();
extern bool Kyber_Local;
extern bool Maestro_Remote;
extern bool debugPWMPassthrough;
extern bool isSerialPortUsedForHCR(int port);   // WCB_HCR.cpp  — serial-device port reservation
extern bool isSerialPortUsedForWLED(int port);  // WCB_WLED.cpp — serial-device port reservation
extern bool isSerialPortUsedForMaestro(int port);  // WCB_Maestro.cpp — local Maestro slots only
extern bool isSerialPortUsedForDFP(int port);      // WCB_DFP.cpp    — serial-device port reservation
// isSerialPortUsedForMP3 comes from WCB_Storage.h (included above).

PWMMapping pwmMappings[MAX_PWM_MAPPINGS];
volatile bool pwmRebootPending = false;

// PWM Stability Tracking
PWMStabilityTracker pwmStability[5] = {
    {0, {0}, 0, false, 0},
    {0, {0}, 0, false, 0},
    {0, {0}, 0, false, 0},
    {0, {0}, 0, false, 0},
    {0, {0}, 0, false, 0}
};

const unsigned long PWM_MIN_TRANSMIT_INTERVAL = 1;  // ms between transmits
const int PWM_CHANGE_THRESHOLD = 6;  // μs change to trigger transmission
const int PWM_STABILITY_RANGE = 6;   // μs range for stability

int pwmOutputPorts[MAX_PWM_OUTPUT_PORTS] = {0, 0, 0, 0, 0};
int pwmOutputCount = 0;
uint8_t pwmOutputAutoSrc[MAX_PWM_OUTPUT_PORTS] = {0, 0, 0, 0, 0};  // see WCB_PWM.h
bool pwmOutputPrevBcstOut[MAX_PWM_OUTPUT_PORTS] = {true, true, true, true, true};   // see WCB_PWM.h
bool pwmOutputPrevBlockIn[MAX_PWM_OUTPUT_PORTS] = {false, false, false, false, false};

// PWM reading variables for each port
volatile unsigned long pwmRiseTime[5] = {0};
volatile unsigned long pwmPulseWidth[5] = {0};
volatile bool pwmNewData[5] = {false};
#if CONFIG_IDF_TARGET_ESP32
static volatile uint8_t pwmLastLevel[5];   // pad level pwmEdge() last recorded per input port (level emulation)
#endif
extern bool espNowInitialized;

// Remote PWM configuration may go out once ESP-NOW is running. This used to be "uptime > 5 s", but nothing at boot
// sends remote PWM config — only commands do — so the gate only ever bit a command that arrived in the first five
// seconds after a reboot (a config push, a test): it cleared or changed the local mapping, saved it and printed
// success, while the remote board was never told. setup() registers the peers right after esp_now_init(), and an
// ETM send to a peer not yet seen online still goes out and retries.
bool canSendESPNow() {
    if (espNowInitialized) return true;
    Serial.println("⚠️  ESP-NOW is not running — remote PWM configuration was NOT sent");
    return false;
}

// Validation function to prevent PWM conflicts with Kyber
// quiet=true suppresses the refusal lines for callers that skip a reserved port as a matter of
// course - the WDP auto-config loop sees the same neighbour advert every 60 s forever, and its
// comment already claimed the skip was silent.
bool canUsePWMOnPort(int port, bool quiet) {
    // Only the port a Kyber mode owns: the Kyber's own port on Kyber LOCAL, S1 on Maestro REMOTE
    // (kyberModeReservesPort, WCB_Storage.cpp - see there for why). The other hardware port of a Kyber
    // LOCAL board is an ordinary port; reserving it too dropped a PWM output saved there from NVS at the
    // next boot (loadPWMOutputPortsFromPreferences) while ;P kept driving the pin (tracker #73 D4).
    // Every caller comes through here: ?MAP,PWM, both boot loaders and WDP PWMTARGET auto-config.
    // The REMOTE S1 text is pinned by HIL pwm.out_port_lines_and_guards / pwm.map_validation.
    if (kyberModeReservesPort(port)) {
        if (!quiet) Serial.printf("❌ Cannot use PWM on Serial%d - reserved for %s\n", port,
                                  Maestro_Remote ? "Maestro/Kyber" : "Kyber");
        return false;
    }

    // Reject ports already claimed by a serial-device module (HCR/MP3/WLED).
    // Symmetric with those modules' own guards, which reject PWM ports — so two
    // subsystems can never silently drive the same UART.
    // Maestro added 2026-09-20: a local Maestro slot owns its port just as firmly as an HCR or
    // WLED does, and ;P had no term for it at all (WCB.ino processPWMOutput).
    if (isSerialPortUsedForHCR(port) || isSerialPortUsedForMP3(port) || isSerialPortUsedForWLED(port) ||
        isSerialPortUsedForMaestro(port) || isSerialPortUsedForDFP(port)) {
        if (!quiet) Serial.printf("❌ Cannot use PWM on Serial%d - reserved for HCR/MP3/WLED/Maestro/DFP\n", port);
        return false;
    }

    return true;
}

// A port a serial mapping reads (?MAP,SERIAL,<port>,...) is refused for PWM when PWM is CONFIGURED: a PWM input takes
// its RX pin, and a PWM output port skips its UART at boot, so the mapping would read nothing - ?MAP,SERIAL refuses the
// opposite order already (WCB coverage re-scan #15). Kept out of canUsePWMOnPort on purpose: the boot loaders call that
// too, and the output loader ERASES a saved output on a refused port, so a pair saved by older firmware would lose its
// PWM at the next boot.
bool serialMapOwnsPort(int port, bool quiet) {
    if (!isSerialPortMonitored(port)) return false;
    if (!quiet) Serial.printf("❌ Cannot use PWM on Serial%d - a serial mapping reads that port\n", port);
    return true;
}
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

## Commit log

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2025-06-02 Fixed a Maestro Issue
    Fixed an issue where the stored sequence could not trigger a maestro on another WCB due to the loop interference mechanism.
    [WCB_Maestro.cpp]
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2025-07-07 updated the format of pin map and fixed one bug of the main sketch.
    Still do not use this version
    [wcb_pin_map.cpp]
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2025-07-23 fixed a bug in the code that printed out the first stored sequence twice in the ?config
    [WCB_Storage.cpp]
2025-07-24 Fixed a config output bug and capped the timer to 30 seconds.
    [command_timer.cpp]
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2026-01-26 Bu Fix
    Changed the removal of the serial mapping to match adding
    [WCB_Storage.cpp, WCB_Storage.h]
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2026-02-09 updated command syntax slightlt
    Update Comand syntax on broadcast commands, and serial labeling and pwm removal.
    Fixed a bug in the serial mapping as well.
    Updated version.
    [WCB_Storage.cpp]
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2026-03-05 Fix type case mismatch for serial mappings in parser
    parseMappingToken was storing type as 'SERIAL' (uppercase) but the UI
    creates mappings with type 'Serial'. This caused three bugs:
    - Raw mode (,R) silently dropped when pushing UI-created serial mappings
    - appendMappingRow select not pre-selected after a config pull
    - detectBidirMappings comparison failed against pulled configs
    Fix: normalize parsed type to 'Serial' at call site; use toUpperCase()
    in buildCommandString so firmware always receives MAP,SERIAL,...
    [parser.js]
2026-03-05 Fix rawMode detection after type case normalization
    parseMappingToken checked type === 'SERIAL' for raw mode but type is
    now passed as 'Serial'. Use toUpperCase() to match regardless of case.
    [parser.js]
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2026-03-05 Several mapping, wizard, and export fixes
    - Mapping destination WCB dropdown limited to wcbQuantity, with Local
    replacing the board's own slot in the list
    - addBoardSection now applies current appMode to new sections so
    mappings are visible when already in Advanced mode
    - saveMappingRow clears unsaved badge after direct send to board
    - removeMappingRow sends MAP CLEAR command to board on delete
    - Wizard no longer applies config to main page until user clicks
    All at Once or One at a Time on the Connect & Push screen
    - Export Config File button added to wizard review screen footer;
    exports from wizardState only, never touches the main page
    - Fix WCBQ in exported file: each [WCBn] secti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
    [parser.js]
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2026-03-11 Wizard: fix sequential/all-at-once connect, port picker, and UI polish
    Port picker & connect fixes:
    - monitorPort: deassert DTR/RTS on open to prevent ESP32 EN-pin reset;
    add 2 s drain + ESP32 boot-signature regex (BOOT_RE) so normal ETM
    heartbeat traffic never false-positives as "Rebooted!"
    - Track monitorPort promises in monitorPromises Map; _portPickerStopMonitors
    now awaits Promise.allSettled(monitorPromises) so every port is fully
    closed before boardManualConnect calls conn.connect()
    - portPickerSelect and closePortPickerModal made async; both await
    _portPickerStopMonitors before resolving the picker promise
    - Wire up previously inert "Select by COM#…" button — opens Chrom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
    [parser.js]
2026-03-11 FW: Add native MP3 Trigger v2.x serial control driver
    Adds WCB_MP3.h / WCB_MP3.cpp — a new peripheral module following the
    Maestro driver pattern — that lets any WCB board drive a SparkFun MP3
    Trigger v2.x over a dedicated serial port.
    Configuration:
    ?MP3,S<port>:<baud> Assign MP3 Trigger to a serial port (9600/38400)
    ?MP3,LIST Show configuration
    ?MP3,CLEAR Free the port
    ?MP3,ONFIN,<key> Run stored command when track finishes ('X')
    ?MP3,ONERR,<key> Run stored command on device error ('E')
    Audio commands (;A,...):
    ;A,PLAY,n / ;A,PLAYFS,n Play by name order or filesystem order
    ;A,STOP / ;A,NEXT / ;A,PREV
    ;A,VOL,n / ;A,VOLUP /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
    [WCB_Help.cpp, WCB_MP3.cpp, WCB_Storage.h]
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2026-03-28 kyber and maestro optimization
    working on the maestro and kyber integration. it was too jittery before. working much better now.
    [WCB_Maestro.cpp, WCB_Storage.cpp, WCB_Storage.h]
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2026-04-06 Fix RTERM WCB limit and dead code UB in command_timer
    WCB_RemoteTerm.cpp had a stale extern declaring WCBMacAddresses[9][6]
    instead of [MAX_WCB_COUNT][6], and an _relayWCB > 8 guard that silently
    blocked RTERM for WCB9+. Updated the extern to use MAX_WCB_COUNT and
    the guard to match.
    command_timer.cpp had a dead-code block using `static size_t = -1`
    (unsigned type initialized to -1 is UB) that tracked currentGroupIndex
    but never acted on it. Removed the block entirely.
    [WCB_RemoteTerm.cpp, command_timer.cpp]
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2026-05-19 Live baud re-init for software serial S3-S5; bump to 6.0.3
    S3-S5 baud changes now take effect immediately via applyLiveBaud()
    (SoftwareSerial end()+begin() re-init, PWM-reserved ports skipped)
    instead of silently requiring a reboot. S1/S2 behavior unchanged.
    [WCB_Storage.cpp]
2026-05-19 Targeted Maestro slot deletion; bump to 6.0.4
    ?MAESTRO,CLEAR,M<id>:W<wcb>S<port> now clears exactly that (id,port,target)
    slot; bare ?MAESTRO,CLEAR,M<id> clears all slots with that ID. Web tool
    emits a targeted clear for each Maestro removed/moved in the UI so the
    firmware registry no longer keeps an orphaned slot (e.g. moving M1 S2->S1).
    [WCB_Maestro.cpp, parser.js]
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2026-05-19 HCR: enforce 3s minimum poll interval; correct port guidance
    A 3s floor keeps EVERY serial port (incl. EspSoftwareSerial S3-S5 at
    9600) comfortably safe, so the prior 'prefer S1/S2' caution is dropped
    as inaccurate. Firmware ?HCR,POLL rejects <3 (OFF/0 still disables);
    Wizard clamps non-zero poll to >=3 in both handlers and reflects the
    clamp in the input; help text + tooltip updated to 'any port works'.
    [WCB_HCR.cpp, WCB_Help.cpp]
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2026-06-25 Bug Fix
    Fixed a bug where the sequences were not being triggered from neighbors.
    Also fixed a bug for managing one wcb via a relayed wcb. the config wasn't fully getting generated prior.
    [WCB_Storage.cpp, command_timer.cpp]
2026-06-29 firmware: WLED module + OTA loop() deferral + relay reliability + ?CONTROLLER
    - WCB_WLED.{h,cpp}: serial WLED control (?WLED config, ;L runtime -> /json/state)
    - OTA: defer esp_ota flash writes from the ESP-NOW callback to loop() (drainOtaPackets)
    - relay config pull: 3x CONFIG_REQ + target dedup + 2-pass CONFIG_FRAG + delivered-session guard
    - boot announce (PACKET_TYPE_ETM_BOOT) so relays re-mark a board ONLINE after a fast reboot
    - ?CONTROLLER command for the controller/special peer (legacy ?SPECIAL kept as input alias)
    - ;H,VOL accepts no-channel = all V/A/B (mirrors VOLUP/VOLDN)
    - WLED added to HCR/MP3 port-conflict guards + ?WLED? help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
    [WCB_HCR.cpp, WCB_Help.cpp, WCB_MP3.cpp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]
2026-06-29 wizard: OTA flashing (serial + wireless relay), relay reliability, otadata reset
    - OTA button: boardOtaSerial (?OTALOCAL) + boardOtaRelay (?OTA), ACK-paced with cursor fast-fail
    - post-OTA proactive re-pull + remote-terminal re-arm
    - relay config pull: 6s timeout / 2.5s retry
    - ?CONTROLLER parsed/emitted (legacy SPECIAL still accepted)
    - flasher: always reset OTA-data (0xE000) so the flashed app boots, decoupled from NVS erase
    [parser.js]
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2026-07-18 Broadcast: optional echo to S0/USB (opt-in, persisted, in backup)
    New broadcastToS0 flag: when ON, processBroadcastCommand also echoes the
    broadcast out S0/USB — INCLUDING when it arrived on S0 (no source-echo
    suppression, unlike S1-S5). Default OFF, persisted in NVS (bdcst_set/S0).
    Configurable via ?BCAST,OUT,S0,ON/OFF and ?SBOS0ON/OFF (S0 is output-only).
    Exported in the config backup; the Wizard preserves it through import/export/
    diff (round-trip only, no UI).
    Also fixes a pre-existing bug: ?SBO/?SBI were dead — the dispatch double-
    stripped the prefix (substring(3) into a handler that strips again + a
    length<6 guard), so every ?SBOSxON/?SBISxOFF (S1-S5 too) was rejected as
    "Invalid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
    [WCB_Storage.cpp, WCB_Storage.h, parser.js]
2026-07-18 WDP: receiver-side PWM output auto-config (TLV 0x10 PWMTARGET)
    A board advertises its remote PWM output targets; each named board self-
    configures that output port on discovery — live, idempotent, no reboot. So a
    target that was powered off when the mapping was created still sets itself up
    the moment it hears the advert. Add-only; removal stays handled by the
    existing ;MAP,PWM,CLEAR,OUT push.
    - New WDP_TLV_PWMTARGET (0x10) + WDP_MAX_PWMTARGET; advertise
    (wdpLocalPwmTargets), decode into nb.pwmSelfPorts, self-config gated on a
    confirmed peer.
    - Declare canUsePWMOnPort() so an unusable (e.g. Kyber-reserved) target port
    is skipped silently instead of re-logging + re-attempting every ad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
    [WCB_WDP.cpp]
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2026-07-23 Add Maestro async get-query request/response
    Implement async request/response for Maestro get queries (getMovingState, getPosition, getErrors). Query results land in RAM-only variables (m<dev>moving, m<dev>pos<ch>, m<dev>err) that IF logic can read without NVS write wear. Support cross-board queries with automatic forwarding to hosting board. Add maestroQueryPort gating to prevent background readers from corrupting replies during port reads. Add setVariableRAM() for non-persistent variable storage and update help documentation.
    [WCB_Help.cpp, WCB_Maestro.cpp, WCB_Variables.cpp]
2026-07-23 Forget temp WDP neighbors; remove temp clients
    Add wdpForgetNeighbor helper to clear WDP neighbor rows when ephemeral peers are evicted or explicitly forgotten, and use it from WCB.ino and WCB_WDP command handling so ?WDP,DUMP stops showing transient entries. Update Wizard UI: honor a dump row's SEEN/nd.live flag when rendering status, add removeClientCard to fully remove ephemeral client sections, and make meshAutoDiscoverTick vanish TEMPORARY peers (peer==4) when not seen while still tombstoning non-temporary peers. Also snapshot client keys to avoid mutation during iteration.
    [WCB_WDP.cpp]
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2026-07-24 Improve Maestro mesh replies and resource handling
    Rewrite inbound Maestro GETs received over the mesh so replies route back to the sender (adds maestroRewriteInboundGet and prototype, call-sites in WCB.ino). Add WCB_SPECIAL_PEER_ID and send :MQR replies to the special controller peer while keeping ;M! for ordinary WCBs. Ensure temporary peer adoption stamps lastSeenMs to avoid reaper leaks. Add RAM-only variable eviction (evictOneRamSlot) so persistent vars are not starved when table is full. Restore local baud on OTA failures to avoid leaving USB at a bumped baud. Small UI tweaks: preserve boardConfigs when removing client cards and refine mesh auto-discover removal logic. Add stopScript h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
    [WCB_Help.cpp, WCB_Maestro.cpp, WCB_OTA.cpp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]
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2026-07-29 Fix legacy "max 8/9 WCBs" caps that rejected high-numbered boards/relays
    A relayed remote terminal through a MgmtRelay at WCB19 returned nothing:
    the target's ?RTERM,START handler hard-capped the relay number at 8
    (WCB.ino:4639), so the serial mirror never armed for a relay > 8. Raised
    to MAX_WCB_COUNT and added on-demand ESP-NOW peer registration in
    WCB_RemoteTerm.cpp so the mirror's unicast reply reaches a high-numbered
    relay that isn't otherwise a registered peer.
    An audit found the same legacy assumption in every ID-addressed subsystem;
    all raised to MAX_WCB_COUNT (20):
    - WCB.ino:3105/3118 ?MGMT,STATS / ?MGMT,ETM requests (targetWCB > 8)
    - WCB_Maestro.cpp:586 remote-Maestro config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
    [WCB_Maestro.cpp, WCB_PWM.cpp, WCB_RemoteTerm.cpp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]
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2026-08-04 Handle special controller peer & Maestro ETM
    Adds CLAUDE.md working notes and fixes handling for the special controller (NaviCore): count it as a reachable peer for ETM ACK expectations and online checks so ensured sends and election logic treat it correctly. Update WDP auto-join to accept the controller's Maestro adverts even though it is marked a client. Ensure all Maestro sends use ETM (updated sendESPNowMessage calls and comments) so WCB_Client sees them. Allow per-host Maestro proxy slots (duplicate IDs supported). Also adjust ETM CHKSM help default to ON.
    [WCB_Help.cpp, WCB_Maestro.cpp, WCB_WDP.cpp]
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2026-08-06 DFPlayer Mini support: ?DFP config + ;D verb + WDP capability
    Adds the DFPlayer Mini as a peer of the MP3 Trigger — a board can host both
    at once, on different ports. ?DFP / ;D for one, ?MP3 / ;A for the other.
    * WCB_DFP.{h,cpp} — the driver, modelled on WCB_MP3: local config, remote
    routing, NVS, backup emit, ONFIN + error callbacks, port reservation.
    Wire bytes come from the shared WcbCmd DfPlayerCodec (>= 0.8.0), so a ;D
    produces identical frames whether a WCB or a WCB_Client host parses it.
    * ;D dispatch through the existing routeStoredOrCap(), so a ;D on a board
    with no local DFPlayer is forwarded to the board that advertises one —
    same single-owner electi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
    [WCB_DFP.cpp, WCB_Help.cpp, WCB_WDP.cpp]
2026-08-06 WCB OTA: register the ESP-NOW peer before relay OTA sends (fixes no-ACK via relay)
    Relay OTA failed with "no response from WCB<n> via relay" whenever the target and
    the relay weren't already mutually peered — common with a MgmtRelay. esp_now_send()
    only delivers to a REGISTERED peer; normal unicasts register it via addActivePeer(),
    but the OTA paths did a bare esp_now_send(). The target RECEIVES the BEGIN fine
    (ESP-NOW receive works unpeered) but its OTA ACK back to the relay (sendOtaAck) hit
    ESP_ERR_ESPNOW_NOT_FOUND and was silently dropped → the Wizard timed out.
    Add otaEnsurePeer() (best-effort esp_now_add_peer; MACs are deterministic from the
    WCB number) and call it before the ACK u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
    [WCB_OTA.cpp]
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2026-08-11 Variables: split into volatile (;V, default) and persistent (;VP)
    ;V now creates/updates a VOLATILE (RAM-only) variable — no flash write on value
    churn, gone on reboot. ;VP (and ?VAR,SET) create/update a PERSISTENT variable
    saved to NVS. A name is one variable: ;VP promotes an existing volatile var, and
    ;V never demotes a persistent one (demote = ?VAR,CLEAR + recreate). ?VAR,LIST and
    the set-echo now tag each variable [volatile]/[persistent].
    This makes the default safe against flash wear: an unaware user driving
    ;V,counter,<n> from a fast loop now stays RAM-only instead of rewriting the whole
    NVS blob on every change (hundreds/sec could wear the 20 KB partition in hours).
    Persistence is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
    [WCB_Help.cpp, WCB_Variables.cpp]
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2026-08-12 Variables: gate the ;V set-confirmation echo behind ?DEBUG,ON
    The "[VAR] <name> = <val> [type]" line for a runtime ;V/;VP set is now debug-only
    (off by default), so NaviCore re-broadcasting ;V,MODE,{mode} every 60 s no longer
    prints once a minute — and no ;V set echoes at all unless ?DEBUG,ON. Supersedes the
    earlier no-op-only suppression. The ?VAR,SET echo stays unconditional: it's the
    Wizard's config-push acknowledgement line (sendAndAwaitIdle), not the mesh spam path.
    [WCB_Variables.cpp]
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2026-08-12 ?STATS,RPT — collect delivery stats other nodes report about themselves
    Each board only measures its own links. This lets every node push its own
    counters to one collecting board, which lists them beside its own — so the fleet
    picture assembles itself with nobody computing a roll-up.
    ?STATS,RPT,<from>,<sent>,<ackd>,<retries>,<failed>,<noSlot>,<bcast>,<recv>
    Stored in reportedStats[], RAM-only, shown under ?STATS in a "Reported by Other
    Nodes" section with the age of each row, and cleared by ?STATS,RESET or a
    reboot. Nothing is written to flash, so a node can report as often as it likes.
    Why a "?" command and not a ";" one: executeCommand() routes "?" to
    processLocalCommand() and ret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
    [WCB_Help.cpp]
2026-08-13 ?STATS,RPT: noSlot -> unguaranteed
    Follows the WCB_Client 1.13.1 rename. Affects the reportedStats field, the
    ?STATS 'Reported by Other Nodes' output, the field list in the error message,
    and the ?STATS help text.
    Verified: clean compile on both CI targets.
    [WCB_Help.cpp]
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2026-08-17 Wizard: DFPlayer config + unified Audio section
    Collapse MP3 Trigger, HCR Vocalizer, and DFPlayer into one "Audio"
    subsection with per-device Enable checkboxes; each device's settings
    block shows only when enabled. Adds DFPlayer config (previously
    unconfigurable in the Wizard) as a full round-trip: local host
    (?DFP,S<port>:9600:V<vol> + ONERR) or remote route (?DFP,REMOTE,W<n>),
    mirroring the MP3 model — baud fixed at 9600, volume 0-30 (inverse of
    MP3's scale), its own serial-port claim ("Managed by DFPlayer").
    - parser.js: config.dfp default, ?DFP parse case, DFP push block,
    DFP port claim in evaluatePortClaims.
    - app.js: _audioMode()/onAudioToggle() helpers; MP3/HCR mode-reads and
    p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
    [parser.js]
2026-08-18 Sequence inventory: ?SEQ,NAMES, ?MGMT,SEQ, WDP SEQHASH TLV
    Lets a remote consumer (NaviCore's command picker, a web UI) learn WHICH
    stored sequences exist on each board and keep that list fresh, without
    scraping ?SEQ,LIST (UART0-only, no wire format) or the config pull (carries
    every value and silently drops the whole response past the 2912-char
    16-chunk ceiling on a board with a real sequence set).
    Design: advertise a 4-byte fingerprint, pull the names on demand.
    - WDP TLV 0x13 SEQHASH — FNV-1a over the NVS key_list, little-endian, placed
    before PORTLABEL in the payload build (functional beats cosmetic; ~16 B
    names each would evict the labels from the fixed 200 B advert). Absent = 0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
    [WCB_Help.cpp, WCB_Storage.cpp, WCB_Storage.h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]
2026-08-18 Sequence inventory: fetch one by key, plus a content-aware hash
    Adds the read-one half of the stored-sequence API and fixes a real defect in the
    fingerprint shipped in bbd6bdf.
    New:
    PACKET_TYPE_SEQVAL_REQ (15) / SEQVAL_FRAG (16)
    ?SEQ,GET,<key> - one sequence, local console
    ?MGMT,SEQGET,<n>,<key> - one sequence, over the mesh
    The request is its own 59-byte struct (espnow_struct_seqval_req) because it must
    carry the key. It cannot instead be an ordinary ?SEQ,GET,<key> command: a command
    arriving over ESP-NOW does not carry its sender into the handler - sourceID is a
    SERIAL PORT (0=USB, 1-5) and the ESP-NOW origin is only the lastReceivedViaESPNOW
    bool - so the target woul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
    [WCB_Help.cpp, WCB_Storage.cpp, WCB_Storage.h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]
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2026-08-19 Fix commandGroups use-after-free and four more S2 defects
    commandGroups use-after-free (FIX-006/011, 4 findings, 6 derivations)
    processCommandGroups() bound a reference into the vector and held it — plus
    a range-for iterator — across an explicit vTaskDelay. serialCommandTask is a
    separate task and reaches parseCommandGroups()/stopTimerSequence() during
    that yield; both clear() the vector and free every String in it.
    Fixed the victim rather than every mutator, per the verification: copy the
    group's commands out before yielding, hold nothing into the vector, and
    re-check a new commandGroupsGeneration counter afterwards so a chain that
    was replaced mid-flight is abandoned i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
    [WCB_Storage.cpp, command_timer.cpp]
2026-08-19 Fix eight more S2 defects: ETM checksum, Kyber duplication, remote-pull mixing
    ETM checksum silently dropped long commands while reporting success
    Under ?ETM,CHKSM the "|CRC########" suffix is appended and the result
    strncpy'd into structCommand[200], so anything over 187 chars lost its
    checksum in transit. The receiver then rejected it — but etmSendAck() fires
    BEFORE CRC verification, so the sender cleared its pending entry, counted a
    successful delivery, and ?STATS showed 100%. Nothing retried.
    Named the limit ETM_MAX_CMD_WITH_CRC and refuse over-long commands loudly
    rather than emitting a frame that will be ACKed and discarded. The relay's
    single-chunk shortcut now uses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
    [WCB_Storage.cpp]
2026-08-19 Fix twelve more review findings; both targets now warning-free
    ETM heartbeat interval could be poisoned to 0
    A bare `?ETM,HB` is the natural way to read the setting — help documents no
    query form — but it yielded "" and toInt() 0, written straight to NVS.
    scheduleNextHeartbeat then drew a negative interval that wrapped to a past
    deadline, settling at ~4 Hz of unacked 252-byte broadcasts and surviving
    reboots. The bare form now queries, values are range-checked, the legacy
    ?ETMHB spelling gets the same guard, and the scheduler clamps defensively
    for values restored from older NVS. ?ETM,MISS given the same treatment.
    etmMissedHeartbeats reverted to 3 everywhere
    The NVS fal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
    [WCB_Storage.cpp, parser.js]
2026-08-19 Fix eight more findings: KYBER,CLEAR clobbering, sequence cycles, fleet reboot
    ?KYBER,CLEAR reset the wrong port on every board
    It acted on a hard-coded port 2, and collectConfigCommands emits
    ?KYBER,CLEAR in every non-Kyber board's config chain — so every full push to
    every plain board reset Serial2 to 9600 and re-enabled its broadcast flags,
    silently undoing settings the same push had applied moments earlier. Now
    acts on the port the Kyber actually held, and does nothing when it was never
    configured. That also removes the serialBroadcastEnabled[-1] write that
    ?KYBER,CLEAR,S0 produced.
    ?ERASE,NVS rebooted the whole fleet and never finished
    clearAllPWMMappings() ends in ES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
    [WCB_PWM.cpp, WCB_Storage.cpp]
2026-08-19 Fix Wizard round-trip losses: baud pickers, Maestro id 9, label clear
    Baud pickers disagreed with the firmware in both directions
    The MP3 picker offered all 13 rates, but the firmware accepts only 9600 or
    38400 and rejects the entire ?MP3 line otherwise — so a user-selected
    115200 silently discarded the whole MP3 config. Reduced to the two legal
    values.
    The Kyber Maestro picker offered only 4 of the 13 legal rates, so a board
    reporting any other rate left the select blank and the blank was read back
    as the configured value. Now carries the full legal set.
    The S3-S5 cap of 57600 did the same to the per-port serial table: the
    firmware accepts the whole table on any port,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
    [parser.js]
2026-08-19 Fix the help-text cluster; add the missing ?OTA topic
    Help that actively misleads:
    - ?BAUD recommended ?MAESTRO,ENABLE, which is not implemented, and
    advertised the legacy ?Sx,rate form the parser rejects (it takes no
    comma). Both corrected to forms that work.
    - ?WCB documented a board-number range of 1-9; the parser accepts 1-20.
    - ?CMDCHAR documented ";Px,width", which cannot parse. The firmware itself
    emits ";Pxnnnn" (WCB_PWM.cpp) and the wiki documents that form.
    - ?WLED documented only the superseded single-device syntax. Rewritten for
    the ID-addressed form the firmware actually implements:
    ?WLED,<id>:W<wcb>S<port>:<baud> for config, ;L<id>,VERB at runtime, a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
    [WCB_Help.cpp]
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2026-08-19 Fix push ordering and make ?MAP,SERIAL replace rather than append
    Stored sequences were lost on any push containing a PWM mapping
    buildCommandString emitted sequences after the PWM/mapping block, but
    applying a PWM input mapping reboots the board — so everything after it went
    into a restarting board and was silently dropped. Sequences now come first
    and the PWM/mapping block is marked as must-stay-last.
    ?MAP,SERIAL appended destinations forever
    A ?MAP,SERIAL command carries the complete destination list for that input
    port, but the firmware merged it into the existing one. A destination the
    user removed or re-pointed in the Wizard therefore stayed live on the board
    indefin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
    [WCB_Storage.cpp, parser.js]
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

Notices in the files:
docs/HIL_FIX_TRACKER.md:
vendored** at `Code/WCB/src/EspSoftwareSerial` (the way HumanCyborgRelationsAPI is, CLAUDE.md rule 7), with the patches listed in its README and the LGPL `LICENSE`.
